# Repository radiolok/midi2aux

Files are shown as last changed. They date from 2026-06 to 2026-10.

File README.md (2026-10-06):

# АВК-6 «Музыкальная пауза»: FPGA-синтезатор и процессор эффектов

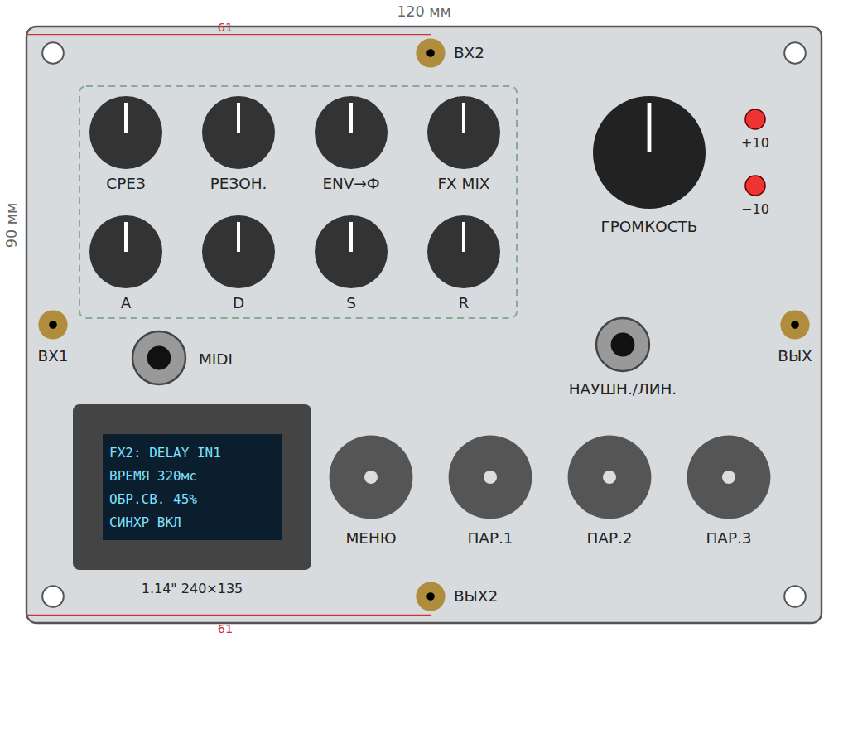
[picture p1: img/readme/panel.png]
Панель модуля (эскиз 120×90 мм)


Сменный модуль для аналогового компьютера **АВК-6**: полифонический MIDI-синтезатор и процессор
эффектов на ПЛИС **Tang Nano 20K** (макет — Tang Nano 9K). Модуль стыкуется с АВК в обе стороны:
входы ВХ1/ВХ2 и СИНХР принимают напряжения АВК и управляют синтезатором и эффектами, а выходы
ВЫХ/ВЫХ2 отдают в АВК звук, огибающие, LFO, GATE или напряжение высоты ноты. Готовый звук
доступен и без АВК — на гнезде наушников / линейного выхода.

Весь звуковой тракт (голоса, фильтры, огибающие, модуляция, эффекты) — в RTL на ПЛИС; распределение
голосов, меню, пресеты — прошивка софт-процессора PicoRV32 внутри той же ПЛИС.

> **Состояние.** Этапы 0–9 плана реализованы и проверены в симуляции (Verilator, бит-в-бит против
> Python-моделей, CI на каждый коммит). Плата, распиновка и проверка на железе — впереди
> (см. [«Что ещё нужно проверить на железе»](#что-ещё-нужно-проверить-на-железе)).
> Предыдущий модуль серии — одноголосный конвертер **MIDI2AUX** на Arduino Nano: [docs/midi2aux.md](docs/midi2aux.md).

Все графики ниже построены по тем же моделям, с которыми бит-в-бит сверяется RTL
(`fpga/model/synthmodel`), а снимки экрана — по коду меню прошивки (`make readme-img`).
Машинная единица АВК (МЕ) = 10 В; входы и выходы — ±12.5 В по постоянному току.

## Содержание

- [Возможности](#возможности)
- [Как устроен](#как-устроен)
- [Аппаратная часть](#аппаратная-часть)
- [Панель](#панель)
- [Голос: генераторы](#голос-генераторы)
- [Фильтр](#фильтр)
- [Огибающие](#огибающие)
- [Модуляция: LFO, матрица, детектор](#модуляция-lfo-матрица-детектор)
- [Связь с АВК](#связь-с-авк)
- [Эффекты](#эффекты)
- [Меню: как пользоваться](#меню-как-пользоваться)
- [Пресеты, SD-карта, обновление прошивки](#пресеты-sd-карта-обновление-прошивки)
- [Консоль](#консоль)
- [Сборка и проверка](#сборка-и-проверка)
- [Что ещё нужно проверить на железе](#что-ещё-нужно-проверить-на-железе)

## Возможности

| | |
|---|---|
| Полифония | 32 голоса на 20K, 16 на 9K (параметр `NUM_VOICES`), MIDI omni, velocity, pitch bend, mod wheel, sustain |
| Голос | 2 генератора (пила, меандр/PWM, треугольник, синус) + шум, расстройка, PolyBLEP, жёсткая синхронизация от СИНХР |
| Фильтр | резонансный ФНЧ / полосовой / ФВЧ 12 дБ/окт на голос, срез от огибающей, velocity и модуляции |
| Огибающие | две ADSR на голос: громкость и срез фильтра |
| Модуляция | 2 LFO (6 форм, сброс фазы от СИНХР), матрица 8 маршрутов «источник × глубина × через» на высоту, срез, громкость, скважность; следящий детектор огибающей входа |
| Связь с АВК | ВХ1/ВХ2 — 12-битные АЦП на 4·fs с цифровым фильтром; СИНХР — период, запуск нот, такт LFO и задержки; ВЫХ2 — любой сигнал шины или напряжение высоты ноты 1 В/окт |
| Эффекты | слоты на общей шине сигналов: MATH (как математические блоки АВК), DELAY ×2, CHORUS/FLANGER, REVERB; мягкий ограничитель на выходах |
| Управление | 8 ручек, 4 энкодера с кнопками, дисплей 240×135, консоль по USB-UART |
| Выходы | ВЫХ, ВЫХ2 — ±12.5 В по постоянному току в АВК; НАУШН./ЛИН. — наушники 16–600 Ом или линейный вход |
| Хранение | пресеты на SD-карте (FAT16/FAT32), обновление прошивки с карты |

## Как устроен

```mermaid
flowchart LR
    MIDI[MIDI вход] --> PARSER[UART + парсер MIDI]
    PARSER --> CPU[PicoRV32: распределение голосов,<br/>меню, пресеты]
    PANEL[ручки, энкодеры,<br/>дисплей] <--> CPU
    CPU --> VOICES
    subgraph VOICES[Голоса ×32, по очереди на одном конвейере]
      OSC[2 генератора + шум] --> SVF[фильтр 12 дБ/окт] --> VCA[усилитель]
      ENV[ADSR1, ADSR2] --> SVF
      ENV --> VCA
    end
    IN[ВХ1, ВХ2<br/>АЦП + дециматор] --> BUS
    SYNC[СИНХР] --> MOD
    MOD[LFO ×2, матрица,<br/>детектор] --> VOICES
    IN --> MOD
    VOICES --> BUS[шина сигналов S0…S7:<br/>синт, ВХ1, ВХ2, LFO1, LFO2,<br/>СИНХР, ENV, GATE]
    MOD --> BUS
    BUS --> SLOTS[слоты: MATH, DELAY,<br/>CHORUS, REVERB]
    SLOTS --> BUS
    SLOTS <--> MEM[(SDRAM / BRAM)]
    BUS --> MIX[микшер ВЫХ + ограничитель] --> DAC[ЦАП PCM5102A:<br/>ВЫХ, НАУШН./ЛИН., ВЫХ2]
    BUS --> MIX2[ВЫХ2: выбранный сигнал] --> DAC
```

Частота отсчётов ≈ 48.34 кГц (PLL 99 МГц из кварца 27 МГц); внутри — 18 бит, 1.0 = 1 МЕ.
Подробности архитектуры и карта регистров — [`fpga/README.md`](fpga/README.md) и ТЗ
[`.plans/fpga-synth/trs.md`](.plans/fpga-synth/trs.md).

## Аппаратная часть

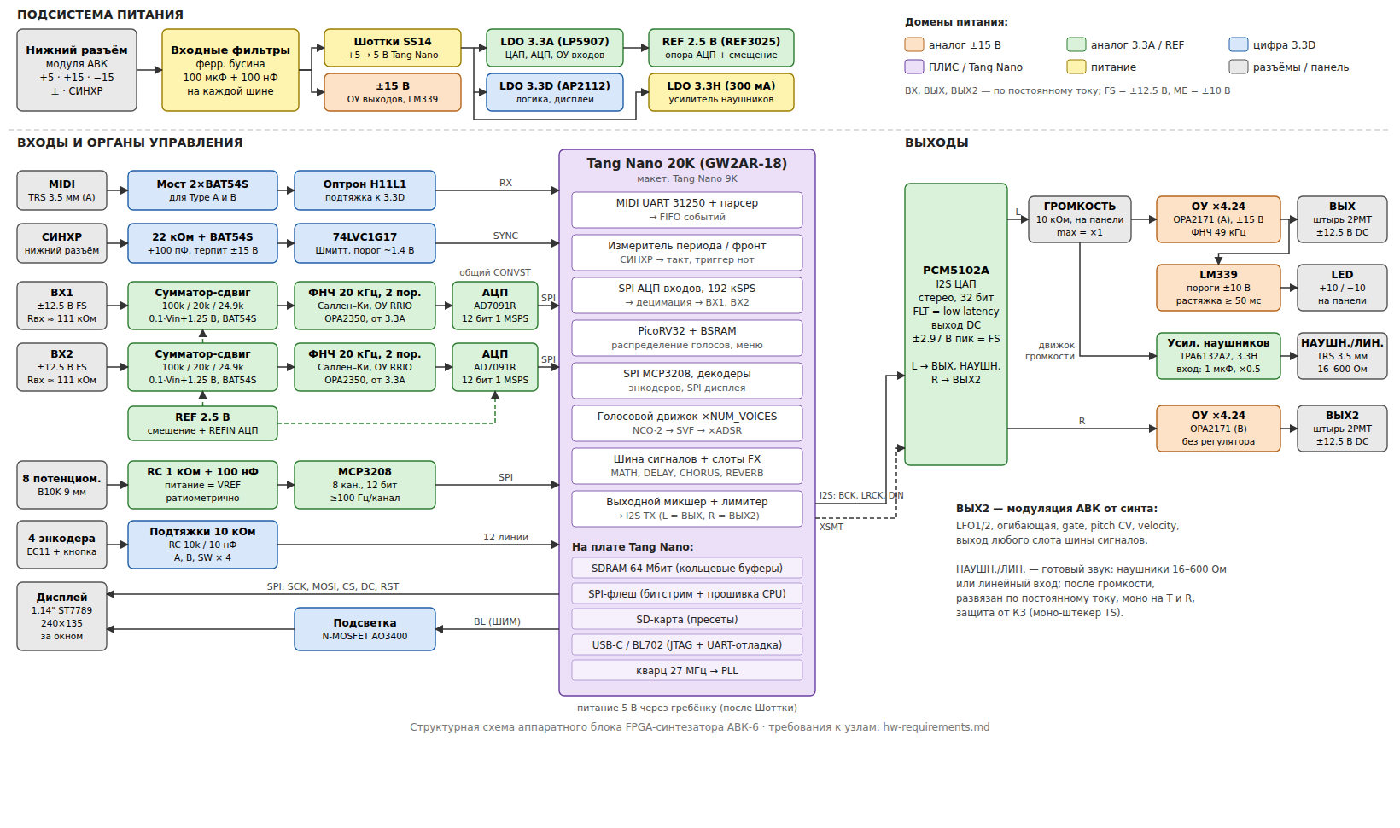
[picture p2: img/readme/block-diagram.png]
Структурная схема аппаратного блока


Цвет блока — домен питания. Всё питание приходит с нижнего разъёма модуля (+5, ±15 В):
Tang Nano питается через диод Шоттки (чтобы USB при прошивке не питал АВК), аналоговая часть —
от отдельного малошумящего LDO 3.3A и опоры 2.5 В, цифра — от LDO 3.3D, усилитель наушников —
от своего LDO 3.3H.

- **Входы ВХ1/ВХ2:** резисторный сумматор-сдвиг (0.1·Vin + 1.25 В, Rвх ≈ 111 кОм, выдерживает ±15 В) →
  ФНЧ 20 кГц 2-го порядка → 12-битный АЦП AD7091R. Оба АЦП запускаются одновременно, опора общая со
  смещением — поэтому A·B и A/B в слоте MATH не страдают от сдвига фаз и дрейфа.
- **MIDI** — через диодный мост (работает с кабелями TRS тип A и B) и оптрон; **СИНХР** с нижнего
  разъёма — через ограничитель и триггер Шмитта (ТТЛ и ±10 В).
- **Ручки** — через 8-канальный MCP3208, энкодеры и дисплей — прямо на ПЛИС.
- **ЦАП PCM5102A:** левый канал → ГРОМКОСТЬ → ОУ ×4.24 → ВЫХ (±12.5 В, индикаторы ±10 на LM339)
  и усилитель наушников TPA6132A2 → НАУШН./ЛИН.; правый канал → ОУ ×4.24 → ВЫХ2.

Требования к каждому узлу — [`hw-requirements.md`](.plans/fpga-synth/hw-requirements.md); принципиальная схема по узлам
(листы, номиналы, подключение по выводам) — [`hw/schematic.md`](hw/schematic.md);
плата и чертёж панели — [`hw/`](hw/README.md).

## Панель

| Элемент | Назначение |
|---|---|
| СРЕЗ, РЕЗОН., ENV→Ф, FX MIX | срез фильтра, резонанс, глубина огибающей на срез, уровень эффектов |
| A, D, S, R | огибающая громкости ADSR1 |
| ГРОМКОСТЬ | аналоговый регулятор выхода; индикаторы +10 / −10 — выход у границы МЕ |
| Энкодер МЕНЮ | листает страницы меню, нажатие — на первую страницу |
| Энкодеры ПАР.1–3 | меняют три параметра текущей страницы; кнопки ПАР.1/ПАР.2 на странице «ПРЕСЕТЫ» — загрузить / записать |
| ВХ1, ВХ2 | входы от АВК, ±12.5 В по постоянному току; штыри 2РМТ: ВХ1 — левый край по центру, ВХ2 — верхний край, 61 мм от левого угла |
| ВЫХ, ВЫХ2 | выходы в АВК: звук и второй канал (см. [ВЫХ2](#выход-2)); ВЫХ — правый край по центру, ВЫХ2 — нижний край, 61 мм от левого угла |
| MIDI | TRS 3.5 мм тип A (тип B тоже работает), слева — со стороны входов |
| НАУШН./ЛИН. | TRS 3.5 мм, справа — со стороны выходов: готовый звук после ГРОМКОСТИ, наушники 16–600 Ом или линейный вход; моно на оба канала, без постоянной составляющей |
| Дисплей | 1.14″ 240×135, меню и строка состояния |

Штыри ВХ/ВЫХ стоят на сетке перемычек АВК-6 (4 мм от края), чтобы соединять модуль с соседними
короткими скобами. Земли на панели нет — она есть на других модулях; СИНХР приходит через нижний
разъём. Эскиз в масштабе — [`panel-sketch.svg`](.plans/fpga-synth/panel-sketch.svg).

## Голос: генераторы

Два генератора на голос, их смесь и шум. Форма у каждого своя (`wave1`, `wave2`), второй генератор
можно сдвинуть на полутоны (`osc2semi`) и расстроить в центах (`detune`) — отсюда «толстый» звук.
Скважность `pw` задаёт ширину импульса меандра, её можно модулировать LFO (ШИМ).

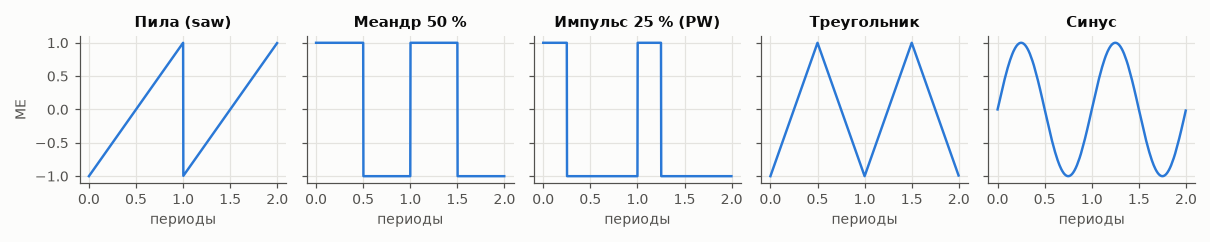
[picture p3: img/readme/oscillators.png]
Формы генераторов


**PolyBLEP** (`blep on`). У пилы и меандра бесконечно крутые скачки; на цифровой частоте отсчётов их
гармоники выше половины fs «заворачиваются» вниз и слышны как негармонический призвук на высоких
нотах. PolyBLEP сглаживает два отсчёта у каждого скачка по-полиномиальному — форма почти не
меняется, а завёрнутые частоты падают примерно на 15 дБ:

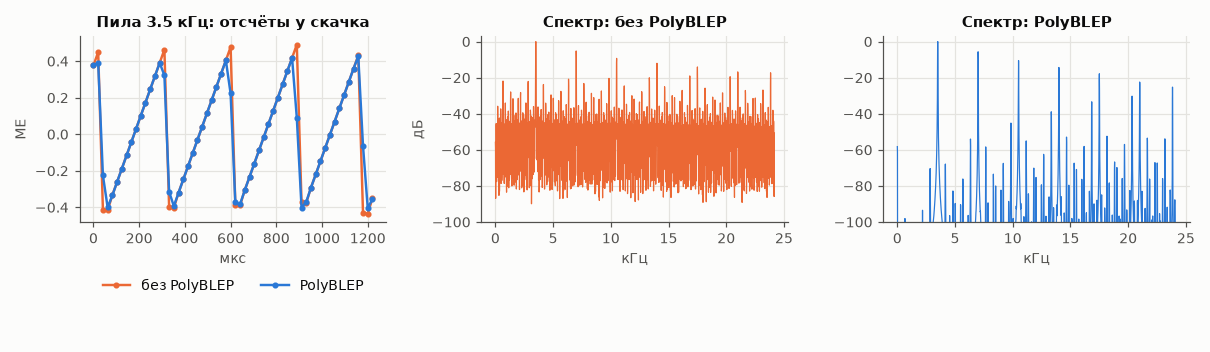
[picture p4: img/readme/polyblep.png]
PolyBLEP


**Жёсткая синхронизация** (`hsync osc1|osc2|both`). Каждый фронт на входе СИНХР перезапускает фазу
выбранных генераторов. Высота звука привязывается к частоте СИНХР, а собственная частота генератора
меняет тембр — классический «sync-звук», управляемый генератором АВК:

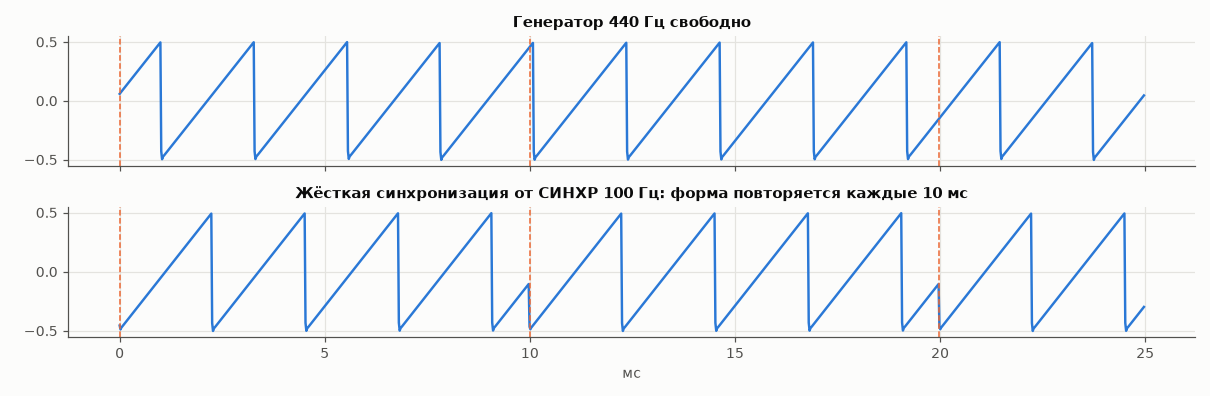
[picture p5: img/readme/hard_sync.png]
Жёсткая синхронизация


## Фильтр

Резонансный фильтр переменных состояний (Chamberlin, 12 дБ/окт, с двукратной передискретизацией) на
каждый голос. Режим `fmode`: **ФНЧ** (lp) — убирает верх, **полосовой** (bp) — оставляет полосу у среза,
**ФВЧ** (hp) — убирает низ. Резонанс (ручка РЕЗОН., добротность Q 0.5…20) поднимает частоты у среза;
при большом Q фильтр «звенит».

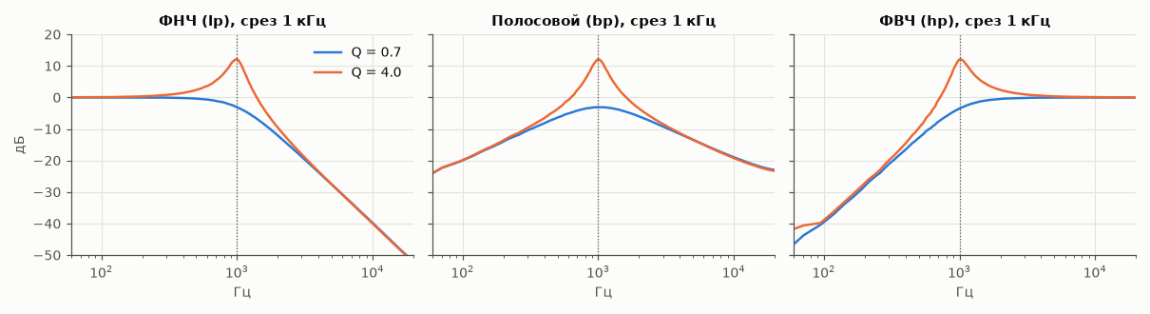
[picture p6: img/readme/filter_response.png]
АЧХ фильтра


Во времени: ФНЧ скругляет скачки пилы, с высоким резонансом на каждом скачке появляется затухающий
звон на частоте среза:

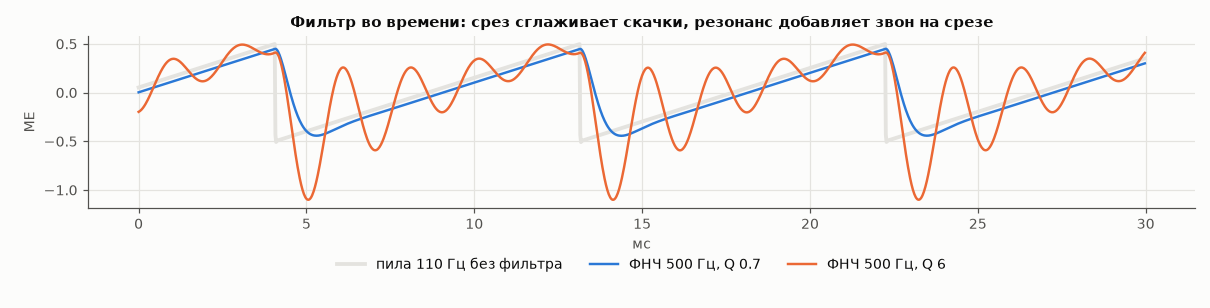
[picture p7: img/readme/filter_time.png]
Фильтр во времени


Срез складывается из: ручки СРЕЗ, огибающей ADSR2 × `env2amt` (± 4 октавы), силы нажатия × `velcut`
и маршрутов матрицы модуляции (например, ВХ1 → срез: генератор АВК «открывает» фильтр).

## Огибающие

**ADSR1** — громкость голоса (ручки A, D, S, R), **ADSR2** — срез фильтра (страницы «ADSR2»). Атака идёт
к 1.0 по экспоненте с «запасом» (как у аналоговых огибающих), спад и затухание — экспоненциальные;
время — до уровня −60 дБ. Повторное нажатие той же ноты перезапускает огибающие.

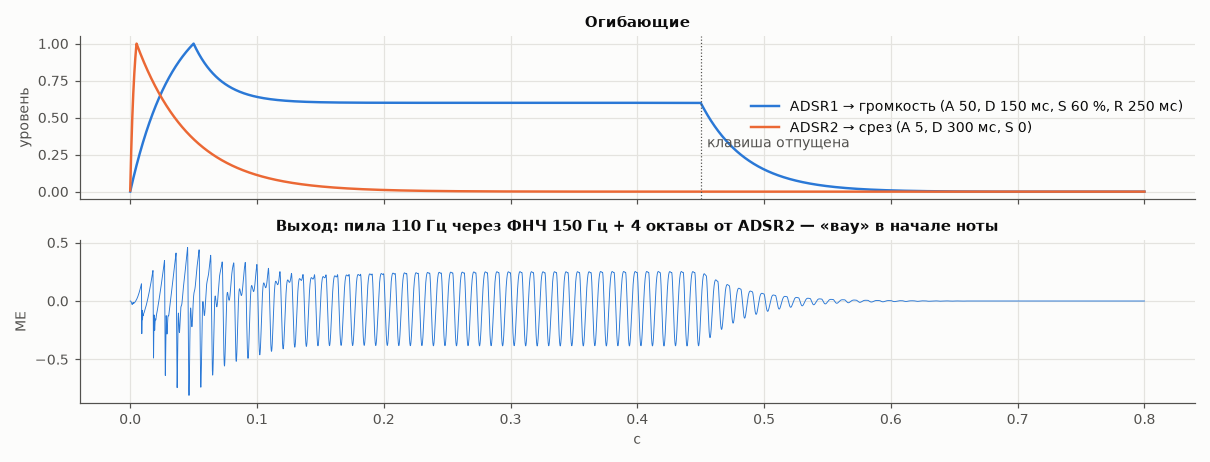
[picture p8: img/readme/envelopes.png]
Огибающие


## Модуляция: LFO, матрица, детектор

**Два LFO** (0.01…50 Гц): синус, треугольник, пила вверх и вниз, меандр, случайный (выборка-хранение).
В режиме `syncmode lfo` фронт СИНХР сбрасывает их фазу — LFO идут в такт с АВК.

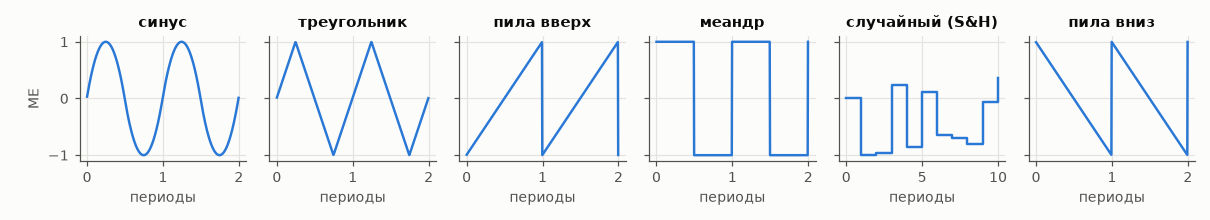
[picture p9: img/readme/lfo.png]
Формы LFO


**Матрица модуляции** — 8 маршрутов «источник × глубина × через»: значение источника умножается на
глубину и, если задан, на третий сигнал «через» (например, LFO1 × колесо модуляции = вибрато, маршрут 0).

| Источники | Назначения |
|---|---|
| 1 LFO1, 2 LFO2, 3 колесо модуляции, 4 ВХ1, 5 ВХ2, 6 СИНХР (±1), 7 ENV (ADSR1 последней ноты), 8 GATE, 9 AUX (из прошивки), 10 детектор огибающей | 1 высота (1 МЕ = октава при глубине 65536), 2 срез, 3 громкость (AM), 4 скважность (ШИМ) |

Маршруты 1…7 задаются из консоли: `route <k> <источник> <через> <назначение> <глубина>`,
например `route 1 4 0 1 65536` — ВХ1 управляет высотой, 1 МЕ (10 В) = октава.

**Следящий детектор огибающей** (источник 10) выделяет громкость сигнала ВХ1 или ВХ2 (`follsrc`), с
отдельными временами атаки и спада (`follatk`, `follrel`). Им удобно, например, открывать фильтр
громкостью сигнала из АВК:

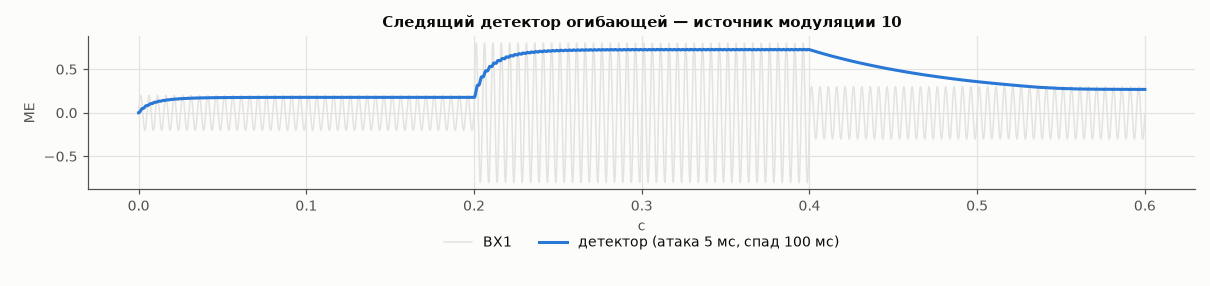
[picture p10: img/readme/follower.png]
Детектор огибающей


## Связь с АВК

**Входы ВХ1, ВХ2.** Два 12-битных АЦП опрашиваются с учетверённой частотой и проходят через
64-отводный цифровой ФНЧ (полоса 21.5 кГц). Нуль и масштаб калибруются командой `cal`.
Входы можно подмешать прямо в выход (`in1mix`, `in2mix`), направить в матрицу модуляции или на
вход любого эффекта.

**Вход СИНХР** (после компаратора) — `syncmode`:
- `off` — только измерение частоты (команда `avk`);
- `lfo` — фронт сбрасывает фазу LFO;
- `note` — каждый фронт перезапускает ноту `syncnote`: АВК «играет» синтезатором.

Также СИНХР задаёт время задержек (`dlysync on`) и жёстко синхронизирует генераторы (`hsync`).

**Шина сигналов.** Всё, что можно смешивать и обрабатывать, лежит на общей шине: S0 синтезатор,
S1 ВХ1, S2 ВХ2, S3 LFO1, S4 LFO2, S5 СИНХР (±1), S6 ENV, S7 GATE, дальше — выходы слотов эффектов.
Вход каждого эффекта — любой сигнал шины, в том числе выход другого эффекта.

**Выход 2** (`out2src`, `out2gain`): любой сигнал шины (по умолчанию LFO1) — так синтезатор
модулирует блоки АВК своими LFO, огибающей или GATE; либо `pitch` — напряжение высоты последней
ноты, 1 В/окт (0 В = нота 60, до первой октавы).

**Выходной микшер.** ВЫХ = синтезатор + подмешанные входы + эффекты (каждый со своим уровнем),
через мягкий ограничитель: до 1 МЕ (10 В) сигнал проходит без искажений, выше плавно упирается
в 1.25 МЕ — перегрузка микшера не даёт жёсткой отсечки:

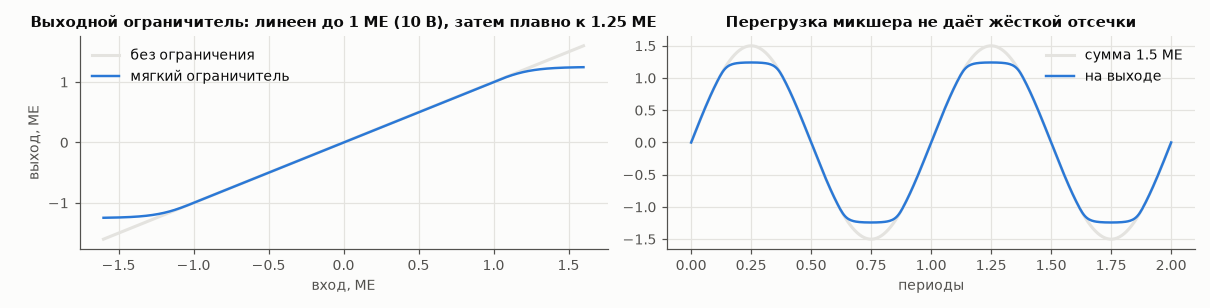
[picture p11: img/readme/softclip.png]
Мягкий ограничитель


## Эффекты

Эффекты — это **слоты** на шине сигналов. У каждого слота вход A (и B) — любой сигнал шины, выход
слота снова попадает на шину и в микшер с уровнем «уровень × FX MIX» (ручка FX MIX масштабирует все
эффекты сразу). На 20K шесть слотов: MATH, MATH, DELAY, DELAY, CHORUS, REVERB; на 9K — MATH, MATH,
DELAY (у 9K мало памяти). Эффекты с памятью работают и в обходе — линия задержки остаётся
заполненной, эффект включается без провала.

### MATH — математика над сигналами

Два слота повторяют математические блоки АВК над любыми двумя сигналами шины (`slot1a`, `slot1b`):

| `slot1op` | Операция | Для чего |
|---|---|---|
| `mul` | A·B | кольцевой модулятор, VCA под управлением АВК |
| `div` | A/B | деление напряжений (с насыщением) |
| `abs` | \|A\| | выпрямитель, удвоение частоты |
| `add`, `sub` | A+B, A−B | сумматор |
| `min`, `max` | min(A, B), max(A, B) | ограничители, логика |
| `mod` | A mod B | остаток — «пилообразное» свёртывание |
| `axpb` | A·k+B | масштаб и смещение (`slot1k`, −2…+2) |

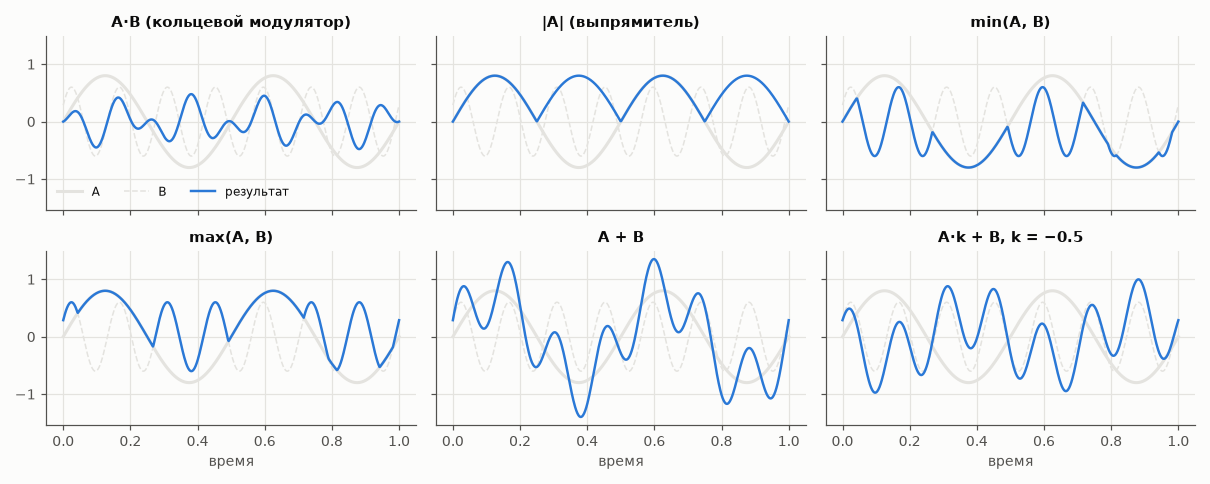
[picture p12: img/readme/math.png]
Операции MATH


Например: `set slot1op 1` (mul), `slot1a in1`, `slot1b in2`, `fxmix 100` — на выходе произведение двух
сигналов АВК; синус 300 Гц × синус 1 кГц даёт 700 и 1300 Гц (проверено в системном тесте).

### DELAY — задержка

Две независимых линии задержки (на 9K — одна): вход (`dly1src`, `dly2src`, по умолчанию ВХ1 и ВХ2),
время (`dly1time`, до 20 с; памяти хватает на ~21 с на линию на 20K и на 85 мс на 9K), повтор —
обратная связь (`dly1fb`, −99…99 %), уровень в выход (`dly1lvl`). `dlysync on` — время задержки равно периоду СИНХР: эхо в такт с АВК.

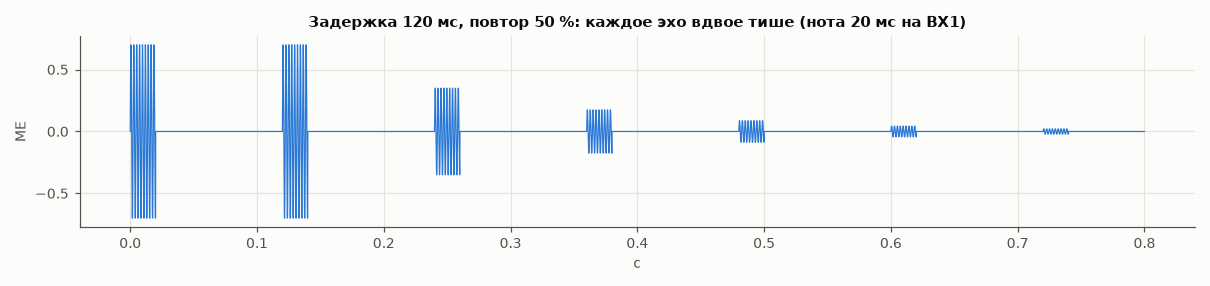
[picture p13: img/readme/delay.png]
Задержка


### CHORUS / FLANGER — хорус и флэнжер

Копия сигнала с задержкой, которая медленно «плавает» (треугольный LFO внутри слота), смешивается
с оригиналом. Параметры: базовая задержка `chobase` (0.1…20 мс), глубина качания `chodepth`,
частота `chorate`, повтор `chofb`, уровень `cholvl`.

- **Хорус** — задержка 5…20 мс, без повтора: звук «размножается», уровень и фаза дышат.

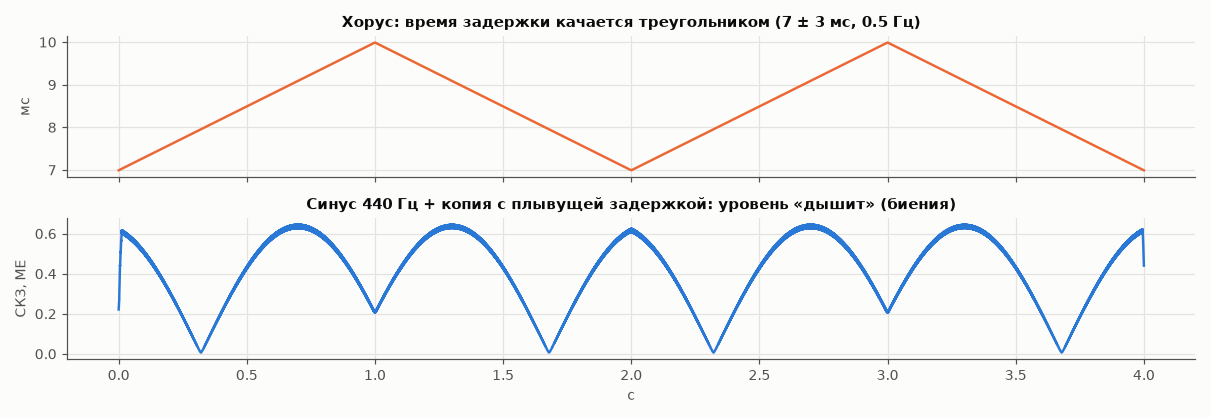
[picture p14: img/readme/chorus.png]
Хорус


- **Флэнжер** — задержка 0.5…5 мс с сильным повтором: получается гребёнка провалов по спектру,
  которая ездит вверх-вниз («реактивный» звук). На шуме это видно на спектрограмме:

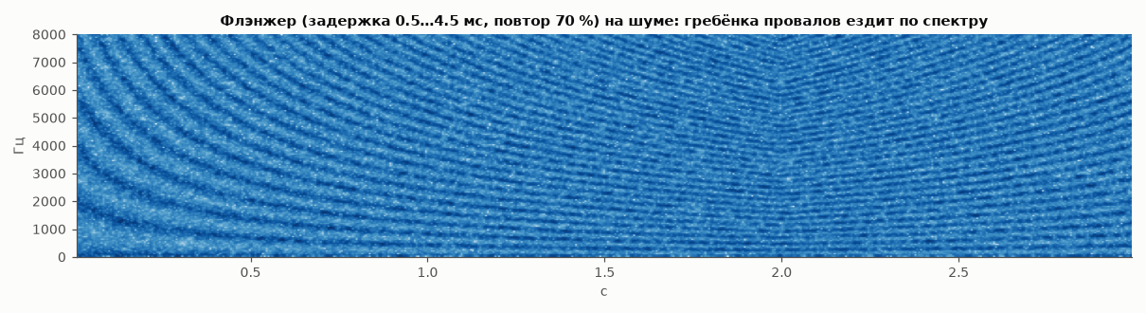
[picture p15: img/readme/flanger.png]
Флэнжер


### REVERB — реверберация

Классическая схема Шрёдера/Freeverb: 4 параллельных гребенчатых фильтра с глушением в обратной
связи и 2 последовательных всепропускающих. `revroom` — размер помещения (длительность хвоста),
`revdamp` — глушение (чем больше, тем быстрее гаснут высокие), `revlvl` — уровень, `revsrc` — вход
(по умолчанию синтезатор; можно реверберировать и сигнал АВК).

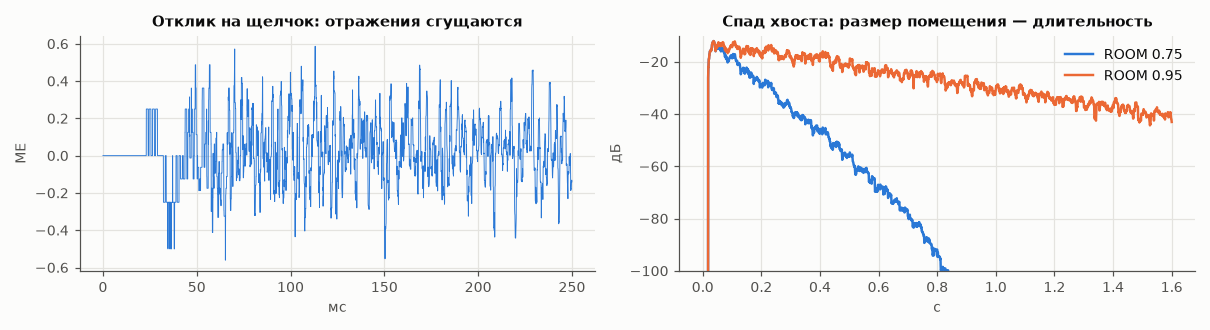
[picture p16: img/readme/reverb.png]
Реверберация


### Как добавить эффект

Эффект = RTL-модуль со стандартным интерфейсом слота (`fpga/rtl/avk/slot_*.sv`: `start`, A, B →
`y`, `done`; параметры; порт памяти) + строка в списке слотов (`SLOT_TYPES`) + описание в прошивке
(`sw/fw/avk.c`). Для каждого слота есть Python-модель, с которой RTL сверяется бит-в-бит.

## Меню: как пользоваться

Меню — это 22 страницы по три параметра. Верхняя строка — название и номер страницы, ниже три
параметра с текущими значениями, внизу строка состояния.

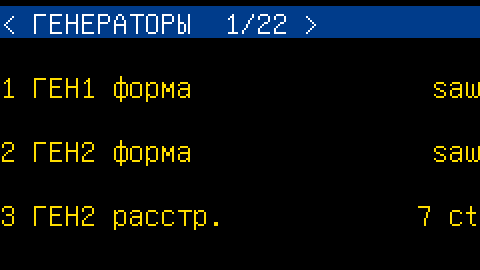
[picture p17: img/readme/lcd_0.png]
Страница меню


- **Энкодер МЕНЮ** листает страницы по кругу (назад с первой — на последнюю). **Нажатие МЕНЮ** —
  сразу на первую страницу.
- **Энкодеры ПАР.1, ПАР.2, ПАР.3** меняют первый, второй и третий параметр страницы. Шаг зависит от
  единиц: частоты, времена и добротность меняются примерно на 6 % за щелчок (быстро проходят весь
  диапазон), остальные — на 1/200 диапазона, перечисления — на один вариант.
- **Восемь ручек** закреплены за своими параметрами (СРЕЗ, РЕЗОН., ENV→Ф, FX MIX, A, D, S, R). Ручка
  не перехватывает параметр, пока её не повернули: после загрузки пресета значения не прыгают, а при
  первом повороте параметр переходит к положению ручки. По краям хода — «мёртвые зоны», чтобы
  уверенно доставать минимум и максимум. Срез, резонанс и времена — по экспоненте, остальное — линейно.
  При повороте ручки строка состояния на 1.5 с показывает новое значение:

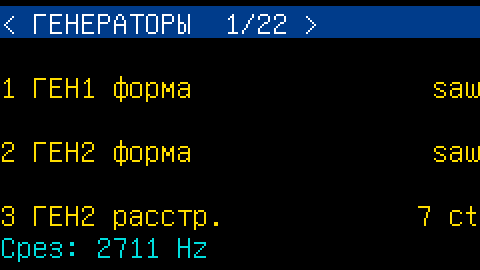
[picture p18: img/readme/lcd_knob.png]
Строка состояния при повороте ручки


- Строка состояния также показывает последнее MIDI-событие и результат записи/загрузки пресета.
- Все параметры меню доступны и из консоли (`set <имя> <значение>`, имена — в таблице).

Все страницы:

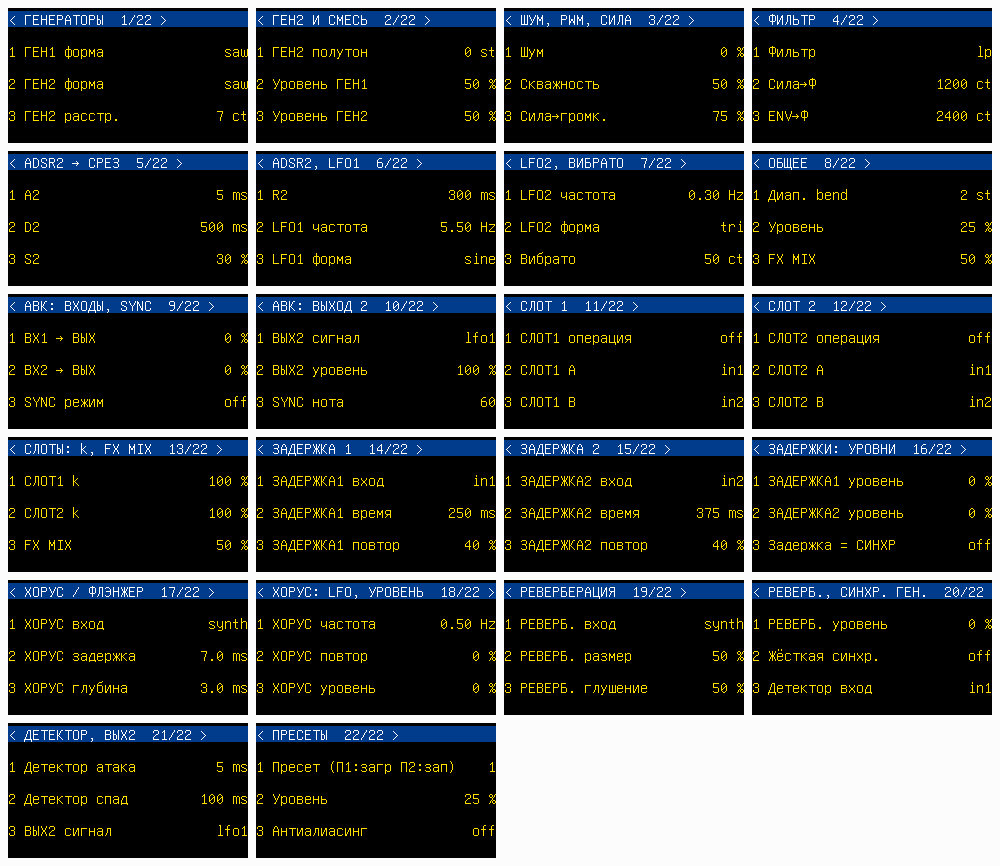
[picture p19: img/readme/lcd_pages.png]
Все страницы меню


| № | Страница | ПАР.1 | ПАР.2 | ПАР.3 |
|---|---|---|---|---|
| 1 | ГЕНЕРАТОРЫ | ГЕН1 форма (`wave1`) | ГЕН2 форма (`wave2`) | ГЕН2 расстр. (`detune`) |
| 2 | ГЕН2 И СМЕСЬ | ГЕН2 полутон (`osc2semi`) | Уровень ГЕН1 (`mix1`) | Уровень ГЕН2 (`mix2`) |
| 3 | ШУМ, PWM, СИЛА | Шум (`noise`) | Скважность (`pw`) | Сила→громк. (`velamp`) |
| 4 | ФИЛЬТР | Фильтр (`fmode`) | Сила→Ф (`velcut`) | ENV→Ф (`env2amt`) |
| 5 | ADSR2 → СРЕЗ | A2 (`a2`) | D2 (`d2`) | S2 (`s2`) |
| 6 | ADSR2, LFO1 | R2 (`r2`) | LFO1 частота (`lfo1rate`) | LFO1 форма (`lfo1wave`) |
| 7 | LFO2, ВИБРАТО | LFO2 частота (`lfo2rate`) | LFO2 форма (`lfo2wave`) | Вибрато (`vibrato`) |
| 8 | ОБЩЕЕ | Диап. bend (`bend`) | Уровень (`master`) | FX MIX (`fxmix`) |
| 9 | АВК: ВХОДЫ, SYNC | ВХ1 → ВЫХ (`in1mix`) | ВХ2 → ВЫХ (`in2mix`) | SYNC режим (`syncmode`) |
| 10 | АВК: ВЫХОД 2 | ВЫХ2 сигнал (`out2src`) | ВЫХ2 уровень (`out2gain`) | SYNC нота (`syncnote`) |
| 11 | СЛОТ 1 | СЛОТ1 операция (`slot1op`) | СЛОТ1 A (`slot1a`) | СЛОТ1 B (`slot1b`) |
| 12 | СЛОТ 2 | СЛОТ2 операция (`slot2op`) | СЛОТ2 A (`slot2a`) | СЛОТ2 B (`slot2b`) |
| 13 | СЛОТЫ: k, FX MIX | СЛОТ1 k (`slot1k`) | СЛОТ2 k (`slot2k`) | FX MIX (`fxmix`) |
| 14 | ЗАДЕРЖКА 1 | ЗАДЕРЖКА1 вход (`dly1src`) | ЗАДЕРЖКА1 время (`dly1time`) | ЗАДЕРЖКА1 повтор (`dly1fb`) |
| 15 | ЗАДЕРЖКА 2 | ЗАДЕРЖКА2 вход (`dly2src`) | ЗАДЕРЖКА2 время (`dly2time`) | ЗАДЕРЖКА2 повтор (`dly2fb`) |
| 16 | ЗАДЕРЖКИ: УРОВНИ | ЗАДЕРЖКА1 уровень (`dly1lvl`) | ЗАДЕРЖКА2 уровень (`dly2lvl`) | Задержка = СИНХР (`dlysync`) |
| 17 | ХОРУС / ФЛЭНЖЕР | ХОРУС вход (`chosrc`) | ХОРУС задержка (`chobase`) | ХОРУС глубина (`chodepth`) |
| 18 | ХОРУС: LFO, УРОВЕНЬ | ХОРУС частота (`chorate`) | ХОРУС повтор (`chofb`) | ХОРУС уровень (`cholvl`) |
| 19 | РЕВЕРБЕРАЦИЯ | РЕВЕРБ. вход (`revsrc`) | РЕВЕРБ. размер (`revroom`) | РЕВЕРБ. глушение (`revdamp`) |
| 20 | РЕВЕРБ., СИНХР. ГЕН. | РЕВЕРБ. уровень (`revlvl`) | Жёсткая синхр. (`hsync`) | Детектор вход (`follsrc`) |
| 21 | ДЕТЕКТОР, ВЫХ2 | Детектор атака (`follatk`) | Детектор спад (`follrel`) | ВЫХ2 сигнал (`out2src`) |
| 22 | ПРЕСЕТЫ | Пресет (`preset`) | Уровень (`master`) | Антиалиасинг (`blep`) |

Параметры ручек — `cutoff`, `res`, `env2amt`, `fxmix`, `a1`, `d1`, `s1`, `r1` — доступны и из консоли.

## Пресеты, SD-карта, обновление прошивки

На карте (FAT16 или FAT32, файлы в корне) пресеты лежат как `PRESET00.BIN` … `PRESET99.BIN`: все
параметры и маршруты матрицы 1…7. Пресет хранит значения по именам параметров, поэтому старые
пресеты загружаются и после обновления прошивки с новыми параметрами.

- **С панели:** последняя страница «ПРЕСЕТЫ», ПАР.1 — номер; **нажатие ПАР.1 — загрузить,
  нажатие ПАР.2 — записать**. Результат — в строке состояния.
- **Из консоли:** `save 5`, `load 5`, `ls` — список файлов, `sd` — переподключить карту.
- **Обновление прошивки:** положить `FIRMWARE.BIN` в корень карты и дать команду `fwupdate` —
  образ копируется во флеш (с проверкой CRC перед записью заголовка) и загружается при следующем
  включении. Без карты прошивку можно залить по USB-UART: `sw/tools/load.py`.

## Консоль

USB-UART Tang Nano (115200 бод): `help`, `list`, `get`/`set <параметр> <значение>`,
`route …`, `note <n> [vel]` / `off <n>`, `screen`, `panel`, `avk`, `cal <1|2> zero|<мВ>`,
`mem`, `sd`, `ls`, `save`, `load`, `fwupdate`. Подробно — [`sw/README.md`](sw/README.md).

## Сборка и проверка

Из корня репозитория (Ubuntu 24.04: Verilator, gcc-riscv64-unknown-elf, Python 3 с numpy/scipy/matplotlib/cocotb):

| Команда | Что делает |
|---|---|
| `make test` | линт RTL, тесты моделей, хост-тесты прошивки, юнит-тесты RTL (cocotb), системные тесты ядра — то же, что CI |
| `make fw` | прошивка RISC-V → `build/sw/fw.bin` |
| `make bitstream-20k`, `make bitstream-9k` | битстрим в Gowin EDA (локально) |
| `make readme-img` | картинки этого README |
| `make plots` | графики симуляции в `fpga/sim/img` |

Дальше: [`fpga/README.md`](fpga/README.md) — RTL, платы, тестбенч; [`fpga/sim/README.md`](fpga/sim/README.md)
— что и как проверяется, с графиками по этапам; [`sw/README.md`](sw/README.md) — прошивка;
[`.plans/fpga-synth/plan.md`](.plans/fpga-synth/plan.md) — план работ на железе (стенд на отладочных платах,
готовый блок), журнал сделанного в симуляции — [`done-sim.md`](.plans/fpga-synth/done-sim.md).

## Что ещё нужно проверить на железе

- распиновка: ручки, энкодеры, дисплей, АЦП, СИНХР, SD-карта пока не назначены (вопрос HO-01);
- фаза тактового сигнала встроенной SDRAM 20K (HO-07; команда `mem` для проверки);
- ресурсы и тайминг 32 голосов и 6 слотов в Gowin EDA;
- калибровка входов по реальному входному каскаду (`cal`);
- инициализация конкретного модуля ST7789, направление энкодеров, совместимость SD-карт;
- порядок и критерии всех проверок — части А (стенд) и Б (блок) [плана](.plans/fpga-synth/plan.md);
- PSRAM на 9K не используется (нужен IP Gowin) — на 9K одна задержка до 85 мс, без хоруса и реверберации.

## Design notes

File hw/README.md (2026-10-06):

# Железо: несущая плата и панель

Проект KiCad схемы — [`kicad/`](kicad/README.md) (сгенерирован по `schematic.md`, цепи сверены скриптом; PDF —
[`kicad/avk_synth.pdf`](kicad/avk_synth.pdf)). Дальше здесь будут плата (Tang Nano 20K, ЦАП, АЦП входов, ОУ, MIDI, СИНХР, органы
управления) и чертёж панели 120×90 мм. Схему и разводку рисует автор проекта.

Структурная схема

Исходные данные:
- **принципиальная схема по узлам** (листы KiCad, позиционные обозначения, номиналы, подключение по выводам, расчёты) —
  [`schematic.md`](schematic.md);
- требования к узлам, номиналы, открытые вопросы `HO-xx` — [`.plans/fpga-synth/hw-requirements.md`](../.plans/fpga-synth/hw-requirements.md);
- структурная схема — [`.plans/fpga-synth/block-diagram.svg`](../.plans/fpga-synth/block-diagram.svg)
  (генерируется `.plans/fpga-synth/tools-gen-block-diagram.py`);
- эскиз панели — [`.plans/fpga-synth/panel-sketch.svg`](../.plans/fpga-synth/panel-sketch.svg);
- трек «железо» H1–H4 — [`.plans/fpga-synth/plan.md`](../.plans/fpga-synth/plan.md).

Предварительная распиновка макета (этап 0) — в `fpga/boards/*/*.cst`, окончательная — после этапа 6 (HO-01).

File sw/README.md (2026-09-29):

# Прошивка софт-процессора (PicoRV32, RV32IMC)

```
include/hw.h       карта памяти и регистры периферии (fpga/rtl/synth_core.sv)
include/lib.h      общий рантайм: UART, printf-подмножество, CRC-32, SPI-флеш, string.h
lib/               его реализация (без libc, -nostdlib; libgcc — для 64-битной арифметики)
boot/              загрузчик в ROM (0x0010_0000, ≤ 4 КБ, без .data/.bss)
fw/                прошивка в RAM с адреса 0: start.S, link.ld, main.c
test/              хост-тесты на обычном gcc (+ ASan/UBSan): unity_lite.h, test_*.c
tools/bin2hex.py   BIN → HEX 32-битных слов (инициализация RAM в симуляции)
tools/bin2rom.py   BIN → SV case-ROM (fpga/rtl/soc/boot_rom.sv)
tools/load.py      загрузка прошивки по UART с компьютера (pyserial)
```

Сборка из корня репозитория:

| Команда | Результат |
|---|---|
| `make fw` | `build/sw/fw.{elf,bin,hex,map}`, `build/sw/boot.{elf,bin}` |
| `make swtest` | хост-тесты `sw/test` |
| `make bootrom` | пересобрать загрузчик и `fpga/rtl/soc/boot_rom.sv` (CI проверяет, что файл актуален) |

Тулчейн: `riscv-none-elf-` (xPack) или `riscv64-unknown-elf-` (Ubuntu: `apt install gcc-riscv64-unknown-elf`),
выбирается автоматически; явно — `make fw CROSS=riscv-none-elf-`.

## Загрузка прошивки

Загрузчик (`boot/boot.c`) после сброса печатает `AVK6 boot`, ждёт образ по UART `SYSINFO_BOOT_WAIT` мс
(500 по умолчанию), затем грузит образ из SPI-флеша, а если его нет — ждёт образ по UART бесконечно.
Работающая прошивка тоже реагирует на магическое слово `AVKB` и передаёт управление загрузчику,
поэтому новая прошивка заливается без нажатия сброса и без пересборки битстрима:

```bash
make fw
python3 sw/tools/load.py /dev/ttyUSB1 build/sw/fw.bin           # в RAM, запуск
python3 sw/tools/load.py /dev/ttyUSB1 build/sw/fw.bin --flash   # и сохранить во флеш
```

Протокол: `AVKB` → устройство отвечает `LOAD` → `len:u32le flags:u32le образ crc32:u32le`
(`flags` бит 0 — записать во флеш) → `OK` и запуск, либо `E1` (длина), `E2` (CRC), `E3` (проверка флеша).
Во флеше по адресу `SYSINFO_FW_FLASH`: заголовок `{"AVKF", len, crc}`, образ — со смещения +256.
Смещение — параметр `FW_FLASH_OFFSET` ядра (9K: 1 МБ, 20K: 5 МБ — за битстримом; уточнить на железе).

Системные тесты `fpga/sim/system/test_synth_core_soc.py` прогоняют всё это в Verilator: загрузку по UART,
отказ по CRC и повтор, запись во флеш (модель SPI NOR) и загрузку из него, повторный вход из прошивки,
печать MIDI-событий прошивкой.

## Консоль (UART, 115200 или `UART_BAUD` ядра)

| Команда | Что делает |
|---|---|
| `list`, `get <p>`, `set <p> <v>` | параметры из таблицы `fw/patch.c` (те же, что в меню) |
| `route <k> <src> <via> <dst> <depth>` | маршрут матрицы модуляции 1…7 (0 — вибрато); номера — `SRC_*`, `DST_*` в `hw.h` |
| `note <n> [vel]`, `off <n>` | нажать / отпустить ноту |
| `screen`, `panel` | текст экрана; энкодеры, кнопки, ручки |
| `avk` | коды и значения ВХ1/ВХ2, частота и счётчик фронтов СИНХР, текущие значения шины сигналов |
| `cal <1\|2> zero` | калибровка нуля входа: на вход подан 0 В |
| `cal <1\|2> <мВ>` | калибровка масштаба (после `zero`): на вход подано известное напряжение |

Параметры связи с АВК: `in1mix`, `in2mix` (входы в ВЫХ), `out2src`, `out2gain` (источник и уровень ВЫХ2),
`syncmode` (`off` / `lfo` — фронт СИНХР сбрасывает фазу LFO / `note` — фронт перезапускает ноту `syncnote`),
`slot1op`…`slot2k` (операция слота MATH, источники A и B, коэффициент k), `fxmix` (уровень слотов в ВЫХ).

Задержки (слоты DELAY): `dly1src`, `dly1time` (мс), `dly1fb` (повтор, %), `dly1lvl` (уровень в ВЫХ), то же `dly2*`;
`dlysync on` — время задержки равно периоду СИНХР. `mem <слово> [значение]` — чтение/запись внешней памяти
(проверка SDRAM на плате).

Хорус/флэнжер: `chosrc`, `chobase`, `chodepth` (0.1 мс), `chorate`, `chofb`, `cholvl`. Реверберация: `revsrc`,
`revroom`, `revdamp`, `revlvl`. `hsync` — жёсткая синхронизация генераторов от СИНХР (`osc1`/`osc2`/`both`);
детектор огибающей: `follsrc`, `follatk`, `follrel`, источник 10 в `route`; `out2src pitch` — на ВЫХ2
напряжение высоты последней ноты (1 В/окт, 0 В = нота 60).

SD-карта (FAT16/FAT32, корневой каталог): `sd` — подключить (делается и при старте), `ls`, `save <n>` / `load <n>` —
пресет `PRESETnn.BIN` (все параметры и маршруты 1…7), `fwupdate` — записать `FIRMWARE.BIN` во флеш (загрузится
при следующем старте). С панели: последняя страница «ПРЕСЕТЫ», номер — энкодер ПАР.1, нажатие ПАР.1 —
загрузить, ПАР.2 — записать. `tools/fatimg.py` — образы FAT для тестов.

`blep on` — PolyBLEP (подавление наложения спектра) для пилы и меандра.

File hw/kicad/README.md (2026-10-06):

# Проект KiCad: несущая плата FPGA-синтезатора АВК-6

Схема по описанию [`../schematic.md`](../schematic.md) и требованиям
[`hw-requirements.md`](../../.plans/fpga-synth/hw-requirements.md). Формат — **KiCad 7** (открывается и в 8/9,
при сохранении KiCad обновит формат). PDF всех листов — [`avk_synth.pdf`](avk_synth.pdf).

| Файл | Что |
|---|---|
| `avk_synth.kicad_pro`, `avk_synth.kicad_sch` | проект и корневой лист |
| `power`, `fpga`, `midi_sync`, `analog_in`, `audio_out`, `phones`, `panel` `.kicad_sch` | 7 листов по функциональным блокам (`schematic.md`, раздел 0) |
| `avk_synth.kicad_sym`, `sym-lib-table` | свои символы: **AD7091R**, **Tang_Nano_20K** (в стандартных библиотеках KiCad 7 их нет) |
| `tools/gen_kicad.py` | генератор: все детали, номиналы, посадочные места и цепи — в нём |
| `tools/check.py` | проверка: KiCad экспортирует netlist, он сравнивается с задуманными цепями |
| `tools/render.sh` | экспорт листов в SVG/PNG для просмотра |

## Как устроена схема

- Символы и посадочные места — **из стандартных библиотек KiCad** (Device, Diode, Audio, Amplifier_Audio, Comparator,
  Analog_ADC, Isolator, Regulator_Linear, Reference_Voltage, Memory_Flash …). Где точного символа нет, взят
  совместимый по выводам: OPA2350 — символ TLV9062, OPA2171 — символ OPA2277, W25Q64JV — символ W25Q32JVSS.
- На листе каждый узел — **блок в пунктирной рамке с заголовком**; блоки уложены по листу плитками, детали внутри — рядами.
  Выводы соединены **метками цепей**: локальные —
  внутри листа, глобальные — между листами, земля — символом GND. Проводов между деталями нет: это схема
  «на метках», её удобно читать по цепям и сверять с `schematic.md`; при желании перерисовать проводами в KiCad.
- Имена цепей к ПЛИС совпадают с портами `fpga/boards/tang_nano_20k/top_synth.sv`.
- Обозначения — как в `schematic.md` (R101…, U401…), аннотация не нужна.

## Проверено

- `python3 tools/check.py`: все **153 цепи** netlist KiCad совпадают с задуманными, нет повторов обозначений
  и цепей из одного вывода.
- Цоколёвки PCM5102A, LM339, MCP3208, H11L1, BAT54S, 74LVC1G17, W25Q, TPA6132A2 взяты из символов KiCad
  и сверены с `schematic.md`.
- ERC в KiCad 7 из командной строки недоступен — **запусти ERC в редакторе** при первом открытии.

## Не проверено — сверить до разводки

| Что | Где |
|---|---|
| Номера выводов **AD7091R** (свой символ, по памяти) и режим внешней опоры | `adc`, HO-09 |
| Выводы **Tang Nano 20K**: имена с `[IOnn]` — из `.cst` (предварительно), остальные не назначены; посадочного места нет | `fpga`, HO-01 |
| Распиновка **нижнего разъёма** J101 (сейчас Conn_01x05) и его посадочное место | `power`, HO-06 |
| TPA6132A2: HPVDD (конденсатор или к VDD), G0/G1 для 0 дБ, EN | `hp` |
| Порядок выводов модуля дисплея J901 и тип входа BLK | `panel` |
| Посадочные места панельных деталей (гнёзда TRS, потенциометры, энкодеры) — по купленным деталям | все |

## Перегенерация

```bash
python3 hw/kicad/tools/gen_kicad.py     # перезаписывает *.kicad_sch и avk_synth.kicad_sym
python3 hw/kicad/tools/check.py         # нужен kicad-cli (sudo apt install kicad)
```

**Генератор перезаписывает листы.** Пока схема правится через `gen_kicad.py` — правь его и `schematic.md` вместе.
Как только начнёшь править схему руками в KiCad (перерисовка проводами, разводка), генератор больше не запускай:
источником правды становятся файлы KiCad, а `check.py` можно оставить для сверки цепей с `schematic.md`.

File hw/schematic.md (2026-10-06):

# Принципиальная схема несущей платы: описание по узлам

Статус: **черновик v0.1** — исходные данные для рисования схемы в KiCad.
Требования (`Т-xx`) и обоснования — [`hw-requirements.md`](../.plans/fpga-synth/hw-requirements.md);
структурная схема — [`block-diagram.svg`](../.plans/fpga-synth/block-diagram.svg); панель — [`panel-sketch.svg`](../.plans/fpga-synth/panel-sketch.svg).

Как читать:
- **Проект KiCad** по этому описанию — [`kicad/`](kicad/README.md) (все листы, цепи сверены с этим документом скриптом).
- Картинки узлов — `hw/img/sch_*.png` (рядом SVG), генерируются `python3 hw/img/gen_schematics.py`
  (schemdraw + matplotlib); при изменении номиналов правится скрипт, а не картинка.
- Схема разбита на **7 листов KiCad** по функциональным блокам (раздел 0); разделы ниже идут по узлам (ain, adc, dac, aout, hp — части листов `analog_in`, `audio_out`, `phones`). У каждого листа — назначение, таблица элементов
  (позиционное обозначение, номинал, корпус, куда подключён), расчёт номиналов и замечания по разводке.
- **Имена цепей ПЛИС совпадают с портами** `fpga/boards/tang_nano_20k/top_synth.sv` (`i2s_bck`, `pot_cs_n`, …) —
  так проще сверять схему с `.cst`.
- **Номера выводов** указаны там, где цоколёвка стандартная (сдвоенный ОУ SOIC-8, LM339, MCP3208, SOT-23 и т. п.).
  Где написано «по даташиту» — цоколёвку брать из символа KiCad/даташита конкретной микросхемы и **обязательно сверить**.
- Резисторы 0603 1 %, если не сказано иное; «0.1 %» — прецизионные (тонкоплёночные, 25 ppm/°C). Конденсаторы до 1 нФ
  — C0G/NP0; 100 нФ…10 мкФ — X7R; электролиты — с запасом по напряжению ×1.5.

---

## 0. Листы и шины

| Лист | Поз. | Содержание | Шины питания |
|---|---|---|---|
| `power` | 1xx | нижний разъём, фильтры, Шоттки 5 В, LDO 3V3A / 3V3D / 3V3H, опора 2.5 В | вход: +5, +15, −15 |
| `fpga` | 2xx | гребёнки Tang Nano 20K, SPI-флеш прошивки, контрольные точки цифры | 5V_TN, 3V3D |
| `midi_sync` | 3xx | MIDI TRS → мост → оптрон; СИНХР → ограничитель → триггер Шмитта | 3V3D |
| `analog_in` | 4xx, 45x, 5xx | входные каскады ВХ1 / ВХ2 (сумматор-сдвиг, ограничитель, ФНЧ Саллена–Ки) и 2× AD7091R | 3V3A, 3V3D, REF2V5 |
| `audio_out` | 6xx, 7xx | PCM5102A; ГРОМКОСТЬ, выходные ОУ ВЫХ/ВЫХ2, индикаторы перегрузки | 3V3A, 3V3D, ±15, REF2V5 |
| `phones` | 8xx | усилитель наушников, гнездо НАУШН./ЛИН. | 3V3H |
| `panel` | 9xx | 8 потенциометров + MCP3208, 4 энкодера, дисплей, панельные штыри | 3V3A, 3V3D |

**Шины (глобальные метки):**

| Цепь | Источник | Потребители |
|---|---|---|
| `+5V_IN` | нижний разъём, после фильтра | Шоттки → `5V_TN`, LDO 3V3A / 3V3D / 3V3H |
| `5V_TN` | D102 (Шоттки) | вывод 5 V Tang Nano |
| `+15V`, `−15V` | нижний разъём, после фильтров | OPA2171, LM339 |
| `3V3A` | U101 LP5907 | ОУ входов, АЦП (VDD), ЦАП (AVDD, CPVDD), MCP3208, потенциометры, REF |
| `3V3D` | U102 AP2112K | ЦАП (DVDD), АЦП (VDRIVE), флеш, оптрон, 74LVC1G17, энкодеры, дисплей |
| `3V3H` | U103 AP2112K | усилитель наушников |
| `REF2V5` | U104 REF3025 | REFIN обоих АЦП, смещение входов, пороги индикаторов |
| `GND` | нижний разъём | единая земля (Т-2.1) |

---

## 1. Лист `power`

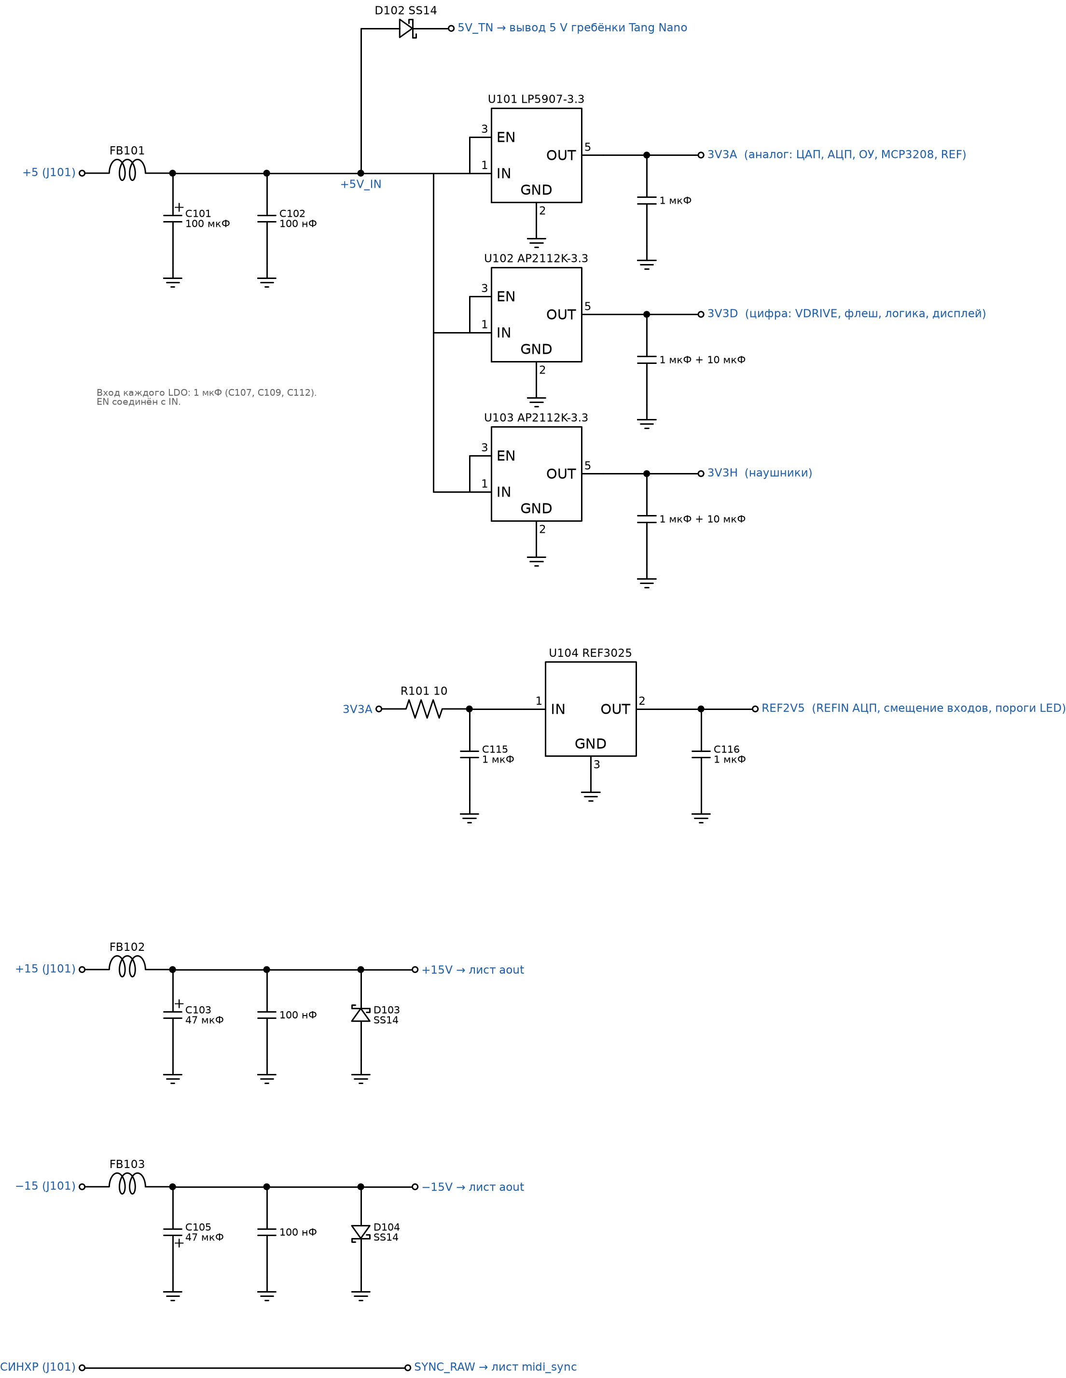
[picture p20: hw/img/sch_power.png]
Лист power: фильтры питания, LDO, опора 2.5 В


| Поз. | Номинал / тип | Корпус | Подключение / примечание |
|---|---|---|---|
| J101 | разъём штатного модуля АВК-6 | по образцу | +5, +15, −15, GND, СИНХР; распиновка — HO-06 |
| FB101 | ферритовая бусина 600 Ом @100 МГц, ≥ 2 А | 0805 | +5 → `+5V_IN` |
| FB102, FB103 | ферритовая бусина 600 Ом @100 МГц, ≥ 0.5 А | 0603 | +15 → `+15V`, −15 → `−15V` |
| C101 | 100 мкФ / 10 В, электролит или полимер | SMD 6.3×5.4 | `+5V_IN` – GND |
| C103, C105 | 47 мкФ / 25 В, электролит | SMD 6.3×5.4 | `+15V` – GND, `−15V` – GND (минус к −15!) |
| C102, C104, C106 | 100 нФ | 0603 | рядом с электролитами |
| D102 | SS14 (1 А, 40 В) | SMA | анод `+5V_IN`, катод `5V_TN` (Т-2.2) |
| D103 | SS14 | SMA | катод `+15V`, анод GND (защита ОУ, Т-2.9) |
| D104 | SS14 | SMA | анод `−15V`, катод GND |
| U101 | LP5907MFX-3.3 (250 мА, 6.5 мкВ rms) | SOT-23-5 | 1 IN = `+5V_IN`, 2 GND, 3 EN = IN, 4 NC, 5 OUT = `3V3A` |
| C107, C108 | 1 мкФ X7R | 0603 | вход и выход U101 (керамика обязательна) |
| U102 | AP2112K-3.3 (600 мА) | SOT-23-5 | 1 VIN = `+5V_IN`, 2 GND, 3 EN = VIN, 4 NC, 5 VOUT = `3V3D` |
| C109, C110 | 1 мкФ + C111 10 мкФ | 0603 / 0805 | вход, выход U102; 10 мкФ — на выходе (дисплей, флеш) |
| U103 | AP2112K-3.3 | SOT-23-5 | как U102, VOUT = `3V3H` |
| C112, C113 | 1 мкФ + C114 10 мкФ | 0603 / 0805 | вход, выход U103 |
| R101 | 10 Ом | 0603 | `3V3A` → вход REF (RC-фильтр с C115) |
| C115 | 1 мкФ | 0603 | вход U104 – GND |
| U104 | REF3025 (2.5 В, 0.2 %, 50 ppm/°C) или REF3325 / ADR361 (лучше по дрейфу) | SOT-23-3 | REF3025: 1 IN, 2 OUT = `REF2V5`, 3 GND (сверить по даташиту выбранной опоры) |
| C116 | 1 мкФ X7R | 0603 | `REF2V5` – GND, у вывода OUT (проверить допустимую ёмкость нагрузки опоры) |
| TP101…TP107 | контрольные точки | — | `+5V_IN`, `+15V`, `−15V`, `3V3A`, `3V3D`, `3V3H`, `REF2V5`; TP108, TP109 — GND |

**Расчёт и замечания:**
- Потери на LDO: (5 − 3.3) В × ток. U102 (3V3D: дисплей ~30 мА, флеш, логика) — до 0.1 Вт; U103 (наушники) — до 0.15 Вт
  в пиках. SOT-23-5 справляется, но под выводом GND — полигон.
- REF2V5 нагружен: 2 × REFIN АЦП (единицы мкА), 2 × Rb 20 кОм (до ±0.1 мА в зависимости от входа), ветка индикаторов
  (≤ 0.1 мА) — итого < 0.5 мА, REF3025 отдаёт до 25 мА.
- Шины ±15 в схеме используются только в листе `aout`; −15 не заводить на другие листы.

## 2. Лист `fpga`

| Поз. | Номинал / тип | Корпус | Подключение / примечание |
|---|---|---|---|
| J201, J202 | гнёзда 1×20, шаг 2.54 (ответные к гребёнкам Tang Nano 20K) | THT | цоколёвка — по схеме Sipeed Tang Nano 20K (HO-01) |
| U201 | W25Q64JVSSIQ (64 Мбит SPI NOR) — прошивка CPU и калибровки | SOIC-8 | 1 /CS = `flash_cs_n`, 2 DO = `flash_miso`, 3 /WP = 3V3D, 4 GND, 5 DI = `flash_mosi`, 6 CLK = `flash_sck`, 7 /HOLD = 3V3D, 8 VCC = 3V3D |
| R201 | 10 кОм | 0603 | `flash_cs_n` → 3V3D (флеш не выбрана, пока ПЛИС не сконфигурирована) |
| C201 | 100 нФ | 0603 | VCC U201 |
| R202…R2xx | 33 Ом | 0603 | последовательно в **выходах ПЛИС с быстрыми фронтами**, у вывода ПЛИС: `i2s_bck`, `i2s_lrck`, `i2s_din`, `adc_sclk`, `pot_sck`, `lcd_sck`, `flash_sck` (гасят звон на линиях длиннее ~5 см) |
| TP2xx | контрольные точки | — | `i2s_bck`, `i2s_lrck`, `i2s_din`, `adc_sclk`, `adc_sdo1`, `midi_rx`, `sync_in` (Т-15.5) |

**Внешний флеш нужен**: на Tang Nano 20K встроенная SPI-флеш занята битстримом и недоступна пользовательской логике,
поэтому прошивка CPU (`FW_FLASH_OFFSET`) и калибровки (план, Ж0.3) лежат во внешней микросхеме на гребёнке
(`fpga/README.md`). На 9K используется встроенная флеш — U201 на макете не нужна.

**Назначение выводов ПЛИС** (номера — из текущего `tang_nano_20k_synth.cst`, предварительно; остальные — назначить при HO-01
и внести в единую таблицу пинов, план Ж0.1):

| Цепь | Направление | Вывод ПЛИС | Лист |
|---|---|---|---|
| `i2s_bck`, `i2s_lrck`, `i2s_din` | выход | 25, 26, 27 | dac |
| `dac_xsmt` | выход | 28 | dac, hp |
| `midi_rx` | вход | 29 | midi_sync |
| `uart_tx`, `uart_rx` | — | 69, 70 (BL702 на плате Tang Nano — **на несущую не выводить**) | — |
| `flash_sck`, `flash_mosi`, `flash_miso`, `flash_cs_n` | вых/вых/вх/вых | 73, 74, 75, 85 | fpga |
| `sync_in` | вход | HO-01 | midi_sync |
| `adc_convst_n`, `adc_cs_n`, `adc_sclk` | выход | HO-01 | adc |
| `adc_sdo1`, `adc_sdo2` | вход | HO-01 | adc |
| `pot_sck`, `pot_mosi`, `pot_cs_n` / `pot_miso` | выход / вход | HO-01 | panel |
| `enc_a[3:0]`, `enc_b[3:0]`, `enc_sw[3:0]` | вход | HO-01 | panel |
| `lcd_sck`, `lcd_mosi`, `lcd_cs_n`, `lcd_dc`, `lcd_rst_n`, `lcd_bl` | выход | HO-01 | panel |
| `sd_*` | — | слот TF на плате Tang Nano (на несущую не выводить) | — |

Итого на гребёнке: **37 GPIO** (33 по Т-3.4 + 4 на флеш). Если свободных меньше — объединить SCK/MOSI потенциометров,
дисплея и флеша в одну шину с раздельными CS (тогда RTL: общий SPI-мастер, план Ж0.1).

Питание Tang Nano: `5V_TN` → вывод 5 V гребёнки; GND — **все** выводы GND гребёнки на полигон. Вывод 3V3 Tang Nano
на несущей не использовать (у платы свой LDO, и 3V3D от него не зависит).

## 3. Лист `midi_sync`

### 3.1 MIDI (Т-4)

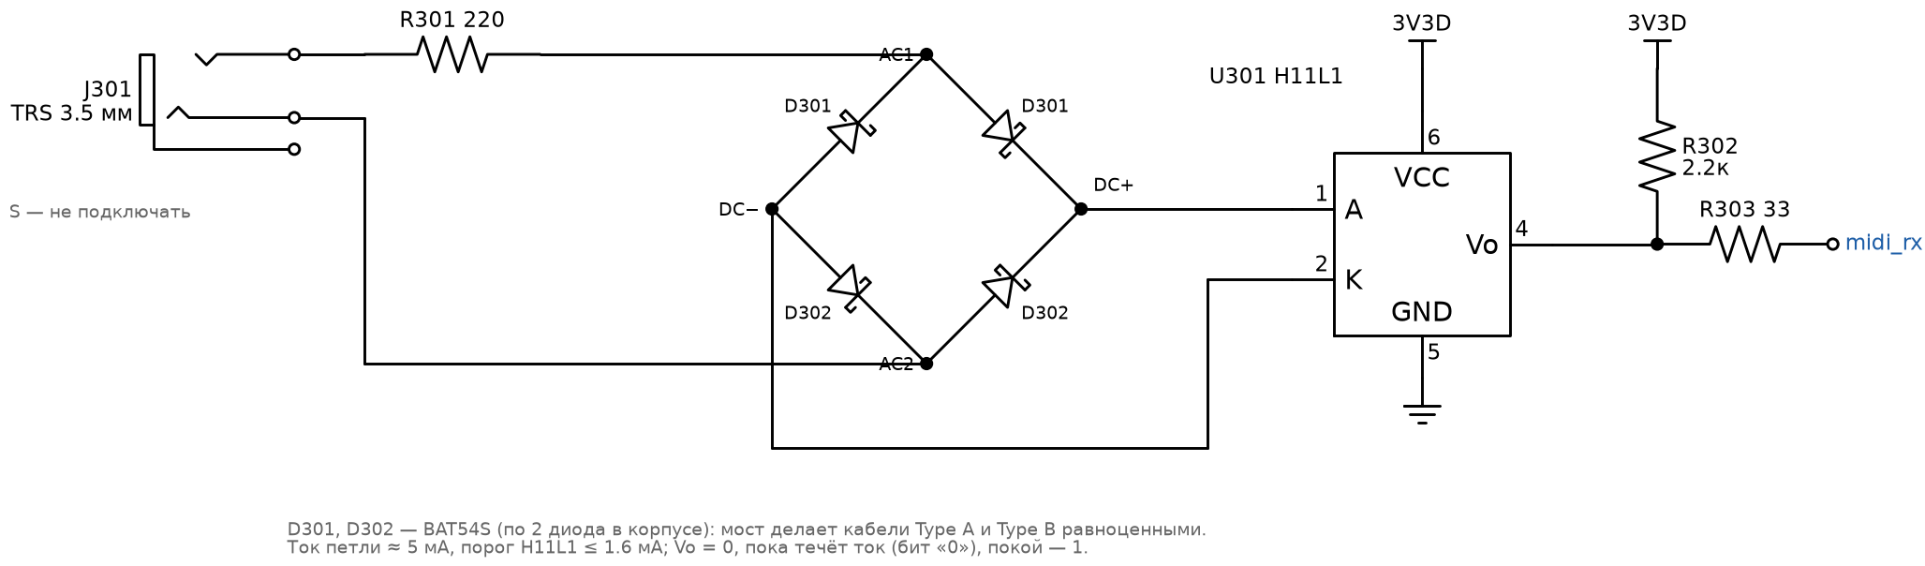
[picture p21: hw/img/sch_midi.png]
MIDI-вход: мост и оптрон


| Поз. | Номинал / тип | Корпус | Подключение / примечание |
|---|---|---|---|
| J301 | гнездо 3.5 мм стерео на панель (PJ-392 / Lumberg 1503 09) | THT | T, R, S; на панели слева (у входов) |
| R301 | 220 Ом | 0805 | T → AC1 моста |
| D301, D302 | BAT54S (два Шоттки последовательно; 1 — анод D1, 2 — катод D2, 3 — средняя точка) | SOT-23 | мост: вывод 3 D301 = AC1, вывод 3 D302 = AC2; выводы 2 обоих = DC+; выводы 1 обоих = DC− |
| U301 | H11L1 (оптрон с триггером Шмитта, VCC 3…15 В) | DIP-6 / SMD-6 | 1 анод = DC+, 2 катод = DC−, 4 Vo, 5 GND, 6 VCC = 3V3D (сверить цоколёвку по даташиту) |
| C302 | 100 нФ | 0603 | VCC U301 |
| R302 | 2.2 кОм | 0603 | Vo → 3V3D (выход — открытый коллектор) |
| R303 | 33 Ом | 0603 | Vo → `midi_rx` |
| C301 | 10 нФ / 100 В, **не устанавливать** | 0603 | S → GND, только если будут наводки; MIDI-приёмник по стандарту экран не заземляет |

**Расчёт:** ток петли от передатчика 5 В (220 + 220 Ом в передатчике + R301 220 Ом): (5 − 1.2 светодиод − 2·0.3 мост) / 660 ≈ 4.8 мА;
от передатчика 3.3 В (33 + 10 Ом): (3.3 − 1.8) / 263 ≈ 5.7 мА. Порог H11L1 ≤ 1.6 мА — запас ×3.
Полярность: ток течёт при «0» бита → Vo = 0; покой (нет тока) → Vo = 1 — это и ждёт `uart_rx` RTL (покой — высокий уровень).
Мост делает разницу между TRS Type A и Type B несущественной (Т-4.2).

### 3.2 СИНХР (Т-5)

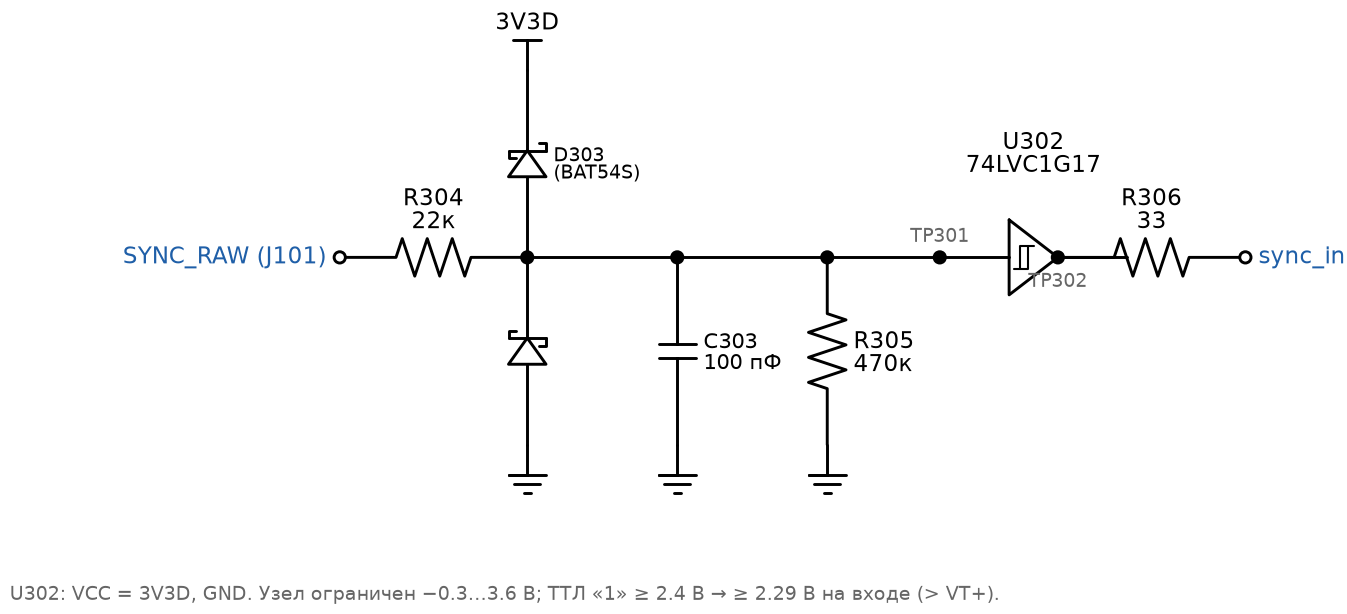
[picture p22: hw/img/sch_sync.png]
Вход СИНХР


| Поз. | Номинал / тип | Корпус | Подключение / примечание |
|---|---|---|---|
| R304 | 22 кОм | 0603 | `SYNC_RAW` → узел |
| D303 | BAT54S | SOT-23 | 1 = GND, 2 = 3V3D, 3 = узел (ограничение −0.3…+3.6 В) |
| C303 | 100 пФ | 0603 | узел → GND (τ = 2.2 мкс — фильтр иголок, на 1.1 кГц не влияет) |
| R305 | 470 кОм | 0603 | узел → GND: определённый «0», когда АВК выключен или СИНХР не подан |
| U302 | 74LVC1G17 (буфер с триггером Шмитта) | SOT-23-5 | 1 NC, 2 A = узел, 3 GND, 4 Y, 5 VCC = 3V3D |
| C304 | 100 нФ | 0603 | VCC U302 |
| R306 | 33 Ом | 0603 | Y → `sync_in` |

**Расчёт:** ТТЛ «1» ≥ 2.4 В → узел 2.4 · 470 / 492 = 2.29 В > порога VT+ 74LVC1G17 при 3.3 В (≤ 2.0 В) — уверенная «1».
При +15 В ток через ограничитель (15 − 3.6) / 22 к ≈ 0.52 мА — поглощает нагрузка 3V3D; при −15 В ≈ 0.67 мА в GND.
**Поправка к Т-5.3:** порог — порог 74LVC1G17 при 3.3 В (VT+ ≈ 1.5…2.0 В, VT− ≈ 0.9…1.4 В), а не «~1.4 В»; для ТТЛ и ±10 В годится.

## 4. Лист `ain` (повторяется для ВХ1 и ВХ2)

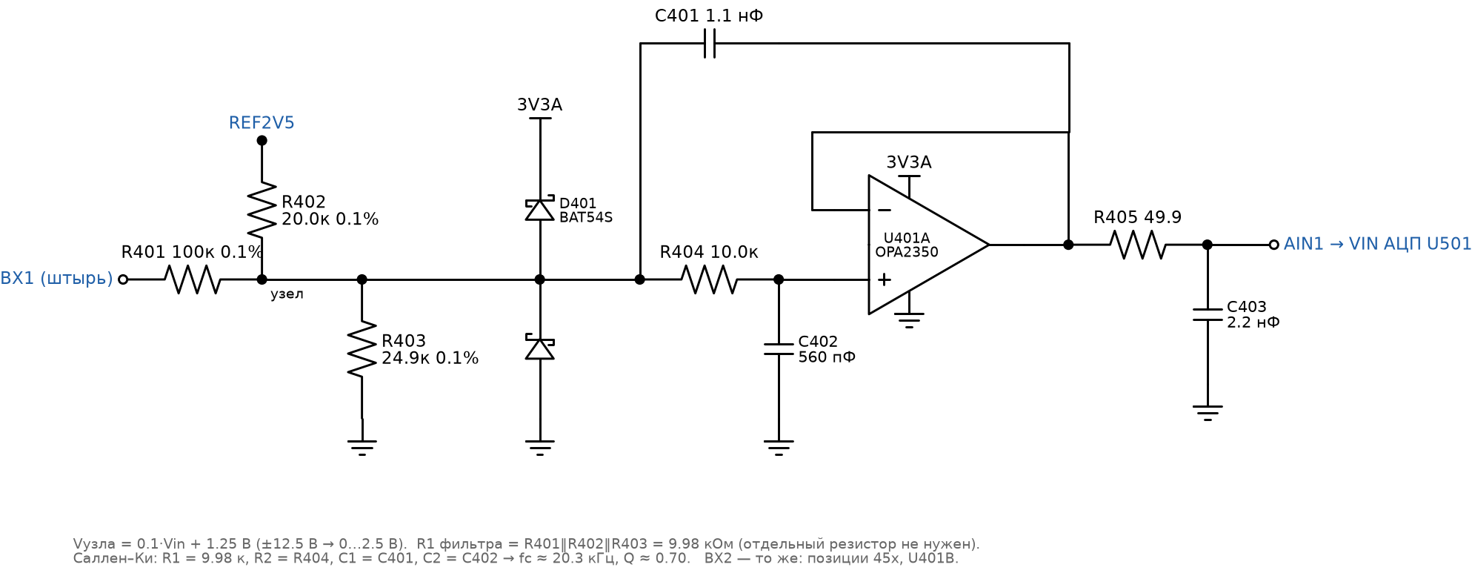
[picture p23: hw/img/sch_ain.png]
Входной каскад ВХ1 (ВХ2 — так же)


| Поз. (ВХ1 / ВХ2) | Номинал / тип | Корпус | Подключение / примечание |
|---|---|---|---|
| R401 / R451 | 100 кОм 0.1 % | 0805 | панельный штырь ВХ → узел сумматора (Ra) |
| R402 / R452 | 20.0 кОм 0.1 % | 0603 | `REF2V5` → узел (Rb) |
| R403 / R453 | 24.9 кОм 0.1 % | 0603 | узел → GND (Rc) |
| D401 / D451 | BAT54S | SOT-23 | 1 = GND, 2 = 3V3A, 3 = узел |
| C401 / C451 | 1.1 нФ C0G 1 % (или 1 нФ + 100 пФ) | 0603 | узел → выход ОУ (C1 фильтра Саллена–Ки) |
| R404 / R454 | 10.0 кОм 0.1 % | 0603 | узел → вход + ОУ (R2 фильтра) |
| C402 / C452 | 560 пФ C0G 1 % | 0603 | вход + ОУ → GND (C2 фильтра) |
| U401 | OPA2350 / TLV9062 / OPA2365 — **одна сдвоенная на оба канала**: A — ВХ1, B — ВХ2 | SOIC-8 | 1 OUTA, 2 IN−A = 1, 3 IN+A; 4 V− = GND; 5 IN+B, 6 IN−B = 7, 7 OUTB; 8 V+ = 3V3A |
| C404 | 100 нФ | 0603 | V+ U401 |
| R405 / R455 | 49.9 Ом | 0603 | выход ОУ → `AIN1` / `AIN2` |
| C403 / C453 | 2.2 нФ C0G | 0603 | `AIN1` / `AIN2` → GND, у вывода VIN АЦП |
| TP401 / TP451 | контрольная точка | — | `AIN1` / `AIN2` (Т-15.5) |

**Расчёт:**
- Сумматор: 1/Ra : 1/Rb : 1/Rc = 1 : 5 : 4.02 → Vузла = 0.1·Vin + 0.5·REF = 0.1·Vin + 1.25 В. ±12.5 В → 0…2.5 В.
  Выходное сопротивление узла (Тевенен) R1 = Ra‖Rb‖Rc = 9.98 кОм — это **первый резистор фильтра**, отдельный не нужен.
  Rвх по ВХ ≈ Ra + Rb‖Rc = 111 кОм (Т-6.2).
- Фильтр Саллена–Ки, единичное усиление, R1 = 9.98 к, R2 = 10.0 к, C1 = 1.1 нФ, C2 = 560 пФ:
  fc = 1 / (2π·√(R1·R2·C1·C2)) ≈ 20.3 кГц; Q = √(R1·R2·C1·C2) / (C2·(R1 + R2)) ≈ 0.70 (Баттерворт).
  На 172 кГц: −40·lg(172/20.3) ≈ −37 дБ (Т-6.3).
- Перегрузка: при +15 В узел = 2.75 В (< 3.3 В, ограничитель молчит), при −15 В узел = −0.25 В — открывается D401,
  ток ≤ 0.15 мА. ОУ с однополярным питанием 3V3A сам не выведет АЦП за 0…3.3 В.
- RC 49.9 Ом / 2.2 нФ (fc ≈ 1.45 МГц) — «резервуар» для заряда УВХ АЦП; ОУ видит его через 49.9 Ом и остаётся устойчивым.
- Погрешность: 0.1 % резисторов → ≤ 0.2 % усиления и ≤ 3 мВ смещения (приведено ко входу ≤ 30 мВ) до калибровки (Т-6.4).

**Разводка:** R401 у штыря, остальное — компактно у АЦП; узел сумматора (высокоомный) — короткий, окружить GND,
цифровые линии рядом не вести. Каналы ВХ1 и ВХ2 развести симметрично (Т-6.6).

## 5. Лист `adc`

| Поз. | Номинал / тип | Корпус | Подключение / примечание |
|---|---|---|---|
| U501, U502 | AD7091R (12 бит, 1 MSPS, SPI) — U501 для ВХ1, U502 для ВХ2 | MSOP-10 | выводы — **по даташиту**; цепи ниже |
| — VIN | | | U501: `AIN1`; U502: `AIN2` |
| — VDD | | | 3V3A, у каждой 100 нФ + 1 мкФ (C501…C504) |
| — VDRIVE | | | 3V3D, 100 нФ (C505, C506) — логика 3.3 В (Т-7.4) |
| — REFIN/REFOUT | | | `REFIN_ADC` (см. ниже), 1 мкФ X7R на GND у каждого (C507, C508; номинал — по даташиту) |
| — REGCAP (если есть) | | | конденсатор внутреннего регулятора — по даташиту |
| — GND | | | GND |
| — CONVST | | | `adc_convst_n` — **общий** для обоих (одновременная выборка, Т-7.1) |
| — CS | | | `adc_cs_n` — общий |
| — SCLK | | | `adc_sclk` — общий (через 33 Ом у ПЛИС, лист fpga); развести «звездой» от ПЛИС или цепочкой с минимальным отводом |
| — SDO | | | U501 → `adc_sdo1`, U502 → `adc_sdo2` (раздельные линии; общий CS не мешает) |
| R501 | 0 Ом (перемычка, выбор опоры) | 0603 | `REF2V5` → `REFIN_ADC` |

**Опора (HO-09).** По требованию Т-7.3 оба АЦП работают от общей внешней 2.5 В (`REF2V5`), той же, что даёт смещение
входов, — тогда смещение и шкала уходят вместе и сокращаются. **Нужно подтвердить по даташиту AD7091R**, как отключается
внутренняя опора при подаче внешней на REFIN/REFOUT (вывод, команда или режим питания). Запасной вариант без внешней опоры:
R501 не ставить, `REF2V5` брать с REFOUT U501 через повторитель на свободном ОУ (буфер обязателен — REFOUT высокоомный),
U104 не устанавливать.

**Разводка:** АЦП — между входными каскадами и ПЛИС; аналоговая и цифровая стороны микросхемы ориентированы к своим зонам;
полигон GND сплошной, без разреза.

## 6. Лист `dac`

| Поз. | Номинал / тип | Корпус | Подключение / примечание |
|---|---|---|---|
| U601 | PCM5102A | TSSOP-20 | цоколёвка ниже — **сверить с даташитом** |
| вывод 1 CPVDD | | | 3V3A; C601 100 нФ + C602 10 мкФ |
| 2 CAPP — 4 CAPM | | | C603 2.2 мкФ X7R между CAPP и CAPM (летающий конденсатор накачки) |
| 3 CPGND | | | GND |
| 5 VNEG | | | C604 2.2 мкФ X7R → GND |
| 6 OUTL | | | → R601 470 Ом → `DAC_L`; C605 2.2 нФ C0G `DAC_L` → GND |
| 7 OUTR | | | → R602 470 Ом → `DAC_R`; C606 2.2 нФ C0G `DAC_R` → GND |
| 8 AVDD | | | 3V3A; C607 100 нФ + C608 10 мкФ |
| 9 AGND | | | GND |
| 10 DEMP | | | GND (без де-эмфазиса) |
| 11 FLT | | | 3V3D (фильтр low latency, Т-8.2) |
| 12 SCK | | | GND (тактирование PLL от BCK, Т-8.1) |
| 13 BCK, 14 DIN, 15 LRCK | | | `i2s_bck`, `i2s_din`, `i2s_lrck` |
| 16 FMT | | | GND (I2S) |
| 17 XSMT | | | `dac_xsmt` через R603 1 кОм; R604 10 кОм → GND (молчит, пока ПЛИС не сконфигурирована, Т-8.3) |
| 18 LDOO | | | C609 1 мкФ X7R → GND (выход внутреннего LDO, наружу не нагружать) |
| 19 DGND | | | GND |
| 20 DVDD | | | 3V3D; C610 100 нФ + C611 10 мкФ |
| TP601, TP602 | | | `DAC_L`, `DAC_R` |

**Расчёт:** RC 470 Ом / 2.2 нФ (fc ≈ 154 кГц) — рекомендованный даташитом фильтр внеполосного шума.
Нагрузка на `DAC_L`: ГРОМКОСТЬ 10 к ‖ делитель наушников 20 к ≈ 6.7 кОм — 470 Ом дают −6.6 % шкалы на ВЫХ при громкости
на максимуме; на `DAC_R` (нагрузка ~1 МОм входа ОУ) — 0 %. Это **убирается программной калибровкой выходов** (план Ж0.3):
требование «×1 в крайнем положении» (Т-9.2) выполняется для всей цепочки после калибровки. Если нужна точность без
калибровки — R601 = 100 Ом, C605 = 10 нФ (та же fc, −1.5 %).

**Разводка:** конденсаторы накачки (C603, C604) и LDOO — вплотную к выводам; I2S от ПЛИС — короткие, с GND рядом.

## 7. Лист `aout`

### 7.1 Выходные усилители ВЫХ, ВЫХ2 (Т-9)

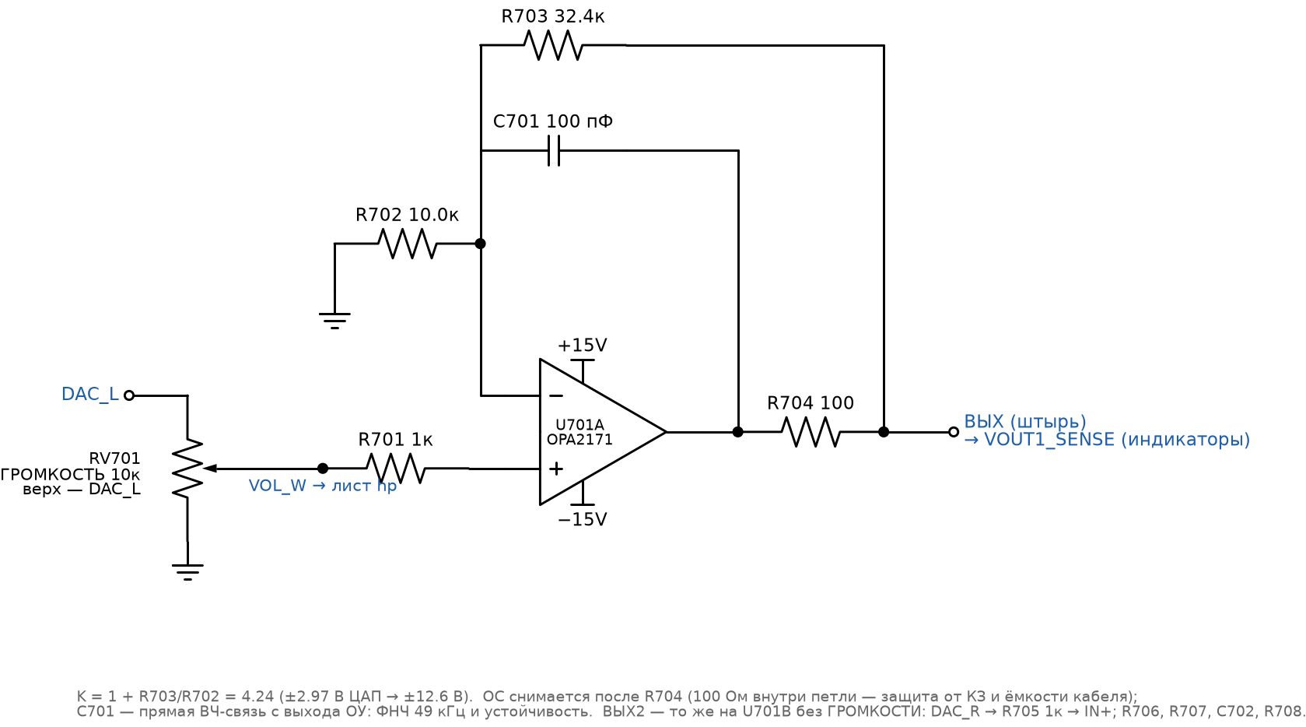
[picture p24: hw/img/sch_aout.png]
Выходной усилитель ВЫХ (ВЫХ2 — так же, без громкости)


| Поз. | Номинал / тип | Корпус | Подключение / примечание |
|---|---|---|---|
| RV701 | 10 кОм, логарифмический (A) или линейный (HO-04), на плату, вал с резьбовой втулкой; Ø ручки — крупная | 9 / 16 мм | 1 (низ) = GND, 3 (верх) = `DAC_L`, 2 (движок) = `VOL_W` |
| R701 | 1 кОм | 0603 | `VOL_W` → IN+ U701A (защита входа, развязка от ёмкости) |
| U701 | OPA2171 (±18 В, RRO, малый входной ток) | SOIC-8 | 1 OUTA, 2 IN−A, 3 IN+A, 4 V− = −15V, 5 IN+B, 6 IN−B, 7 OUTB, 8 V+ = +15V |
| C703, C704 | 100 нФ | 0603 | V+ и V− U701, у выводов; C705, C706 10 мкФ / 25 В на группу |
| R702 / R706 | 10.0 кОм 0.1 % | 0603 | IN− → GND (Rg) |
| R703 / R707 | 32.4 кОм 0.1 % | 0603 | **ВЫХ / ВЫХ2 (после R704 / R708)** → IN− (Rf: ОС с нагрузки, Т-9.5) |
| C701 / C702 | 100 пФ C0G | 0603 | **OUT ОУ** → IN− (ВЧ-обратная связь мимо R704 — устойчивость на ёмкость кабеля + ФНЧ) |
| R704 / R708 | 100 Ом | 0805 | OUT ОУ → штырь ВЫХ / ВЫХ2 (защита от КЗ и ёмкости, внутри петли ОС) |
| R705 | 1 кОм | 0603 | `DAC_R` → IN+ U701B |
| TP701, TP702 | | | ВЫХ, ВЫХ2 |

**Расчёт:** K = 1 + 32.4/10.0 = 4.24 → полная шкала ЦАП ±2.97 В → ±12.6 В; МЕ ±10 В при 0.79 FS (Т-9.1).
ФНЧ: 1/(2π·32.4 к·100 пФ) ≈ 49 кГц (Т-9.6). Выходное сопротивление на НЧ ≈ 100 Ом / (петлевое усиление) < 0.1 Ом (Т-9.5).
КЗ на GND: ток ограничен ОУ (~±35 мА у OPA2171) и 100 Ом; рассеяние в SOIC-8 ≈ 0.5 Вт на канал в худшем случае —
кратковременно допустимо; длительное КЗ обоих каналов — проверить нагрев на макете (план, А4.6).

### 7.2 Индикаторы перегрузки +10 / −10 (Т-10)

Все четыре компаратора LM339 питаются от +15 / −15 (вывод 3 VCC = +15V, вывод 12 GND = **−15V**): тогда входной диапазон
−15…+13.5 В охватывает и ±10 В, и 0 В, а открытый коллектор тянет выход к −15 В.

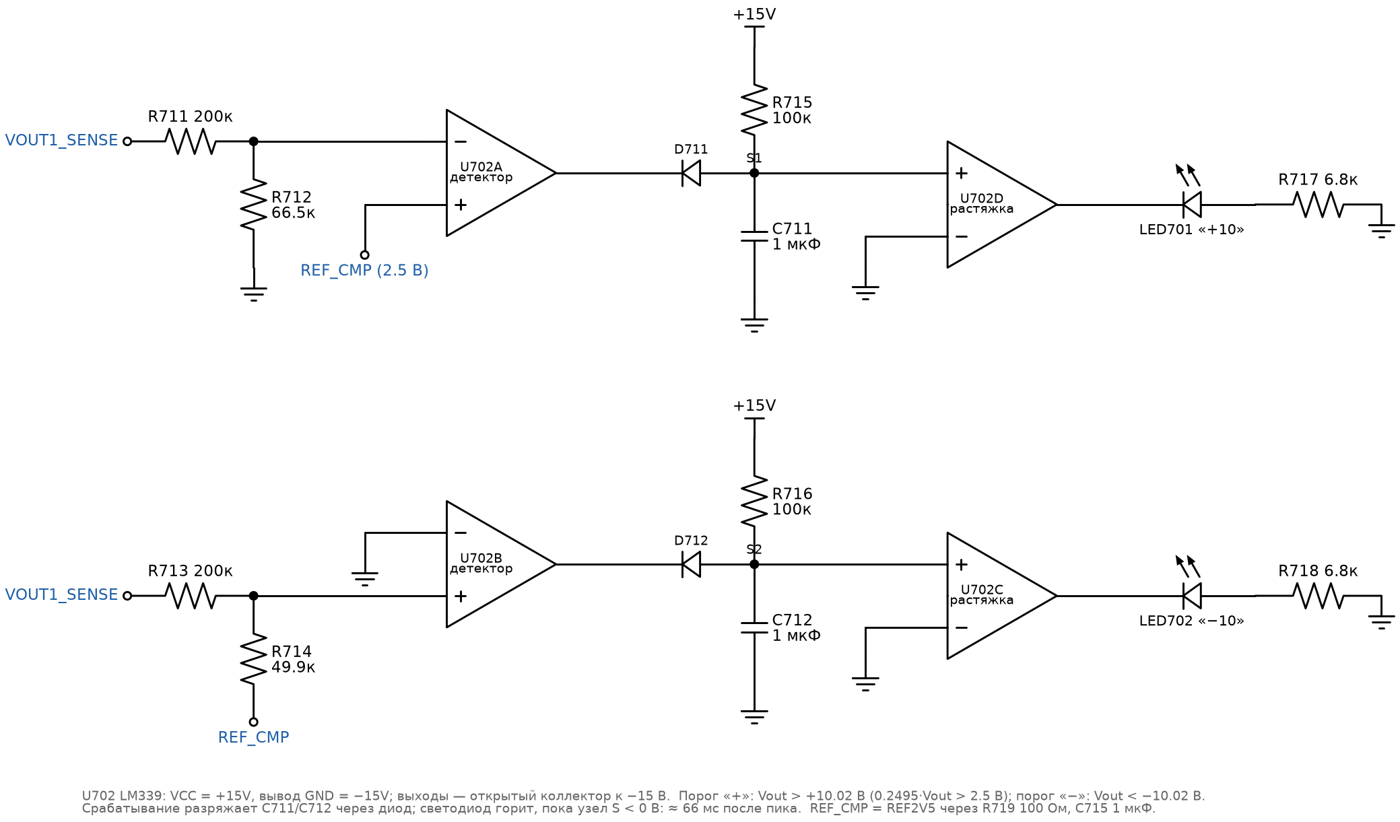
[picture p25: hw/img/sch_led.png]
Индикаторы перегрузки +10 / −10


| Поз. | Номинал / тип | Корпус | Подключение / примечание |
|---|---|---|---|
| U702 | LM339 (4 компаратора, открытый коллектор) | SOIC-14 | 1 OUT2, 2 OUT1, 3 VCC = +15V, 4 IN1−, 5 IN1+, 6 IN2−, 7 IN2+, 8 IN3−, 9 IN3+, 10 IN4−, 11 IN4+, 12 GND = −15V, 13 OUT4, 14 OUT3 |
| C713, C714 | 100 нФ | 0603 | VCC и «GND» (−15V) U702 |
| R711 / R712 | 200 кОм / 66.5 кОм | 0603 | делитель ВЫХ → IN1− (порог +10.02 В) |
| R713 / R714 | 200 кОм / 49.9 кОм | 0603 | сумматор ВЫХ и `REF_CMP` → IN2+ (порог −10.02 В) |
| R719, C715 | 100 Ом, 1 мкФ | 0603 | `REF2V5` → `REF_CMP` (развязка опоры АЦП от бросков компараторов; 100 Ом последовательно с R714 сдвигают порог «−» всего на 0.02 В — больше не ставить) |
| D711, D712 | 1N4148W | SOD-123 | анод — узел S1/S2, катод — OUT1/OUT2 |
| R715, R716 | 100 кОм | 0603 | S1/S2 → +15V |
| C711, C712 | 1 мкФ X7R / 25 В | 0805 | S1/S2 → GND |
| LED701, LED702 | красный 3 мм повышенной яркости (на панель, Т-10) | THT | катод → OUT4 / OUT3, анод → R717 / R718 |
| R717, R718 | 6.8 кОм | 0603 | анод LED → GND |

**Как работает:**
- Детектор «+»: 0.2495·Vout > 2.5 В (Vout > +10.02 В) → IN1− > IN1+ → OUT1 открыт (−15 В) → через D711 быстро
  разряжает C711 до ≈ −14 В.
- Детектор «−»: (Vout/200к + 2.5/49.9к) < 0 (Vout < −10.02 В) → IN2+ < IN2− → OUT2 открыт → разряжает C712.
- Растяжка: пока S < 0 В, IN+ < IN− → OUT открыт → светодиод горит, ток (15 − 1.8) / 6.8 к ≈ 1.9 мА.
  После превышения S заряжается через 100 к к +15 В; от −14 В до 0 В — τ·ln(29/15) ≈ 66 мс (Т-10.2: ≥ 50 мс).
- Нагрузка на ВЫХ: 266.5 к ‖ 249.9 к ≈ 129 кОм (Т-10.3: ≥ 100 кОм). Порог ±10.02 В ±0.25 В при 0.1 % делителях и 0.2 % опоре.

## 8. Лист `hp` — наушники / линейный (Т-9a)

| Поз. | Номинал / тип | Корпус | Подключение / примечание |
|---|---|---|---|
| R801, R802 | 10 кОм / 10 кОм | 0603 | `VOL_W` → R801 → узел HP_IN → R802 → GND (×0.5) |
| C801, C802 | 1 мкФ (плёнка PPS / X7R 16 В) | 0805 | HP_IN → INL+ (2), HP_IN → INR+ (3) |
| C808, C809 | 1 мкФ (как C801/C802) | 0805 | INL− (1) → GND, INR− (4) → GND: **входы TPA6132A2 дифференциальные**, «−» сажается на землю по переменному току через такой же конденсатор |
| U801 | TPA6132A2RTE (усилитель наушников DirectPath) | WQFN-16 3×3 | выводы по символу KiCad: 1 INL−, 2 INL+, 3 INR+, 4 INR−, 5 OUTR, 6 G0, 7 G1, 8 HPVSS, 9 CPN, 10 PGND, 11 CPP, 12 HPVDD, 13 EN, 14 VDD, 15 SGND, 16 OUTL, 17 EP |
| — VDD (14) | | | `3V3H`; C806 2.2 мкФ + C807 100 нФ |
| — накачка | | | C804 1 мкФ CPP–CPN; C805 1 мкФ HPVSS → GND; C810 1 мкФ HPVDD → GND (**проверить по даташиту**: возможно, HPVDD соединяется с VDD) |
| — PGND, SGND, EP | | | GND |
| — G0, G1 | | | R804, R805 0 Ом на GND — коэффициент 0 дБ проверить по таблице даташита (вариант +6 дБ — перестановкой перемычек) |
| — EN | | | `HP_EN`: `dac_xsmt` → R803 10 кОм → EN; C803 1 мкФ → GND (включение ≈ 10 мс после ЦАП, Т-9a.7) |
| — OUTL / OUTR | | | → J801 Tip / Ring напрямую (каждый наушник — свой канал, Т-9a.5) |
| J801 | гнездо 3.5 мм стерео на панель | THT | T = OUTL, R = OUTR, S = GND; на панели справа (у выходов) |
| D801, D802 | TVS PESD5V0S1BA (двунаправленные) | SOD-323 | T → GND, R → GND |
| TP801 | | | HP_IN |

**Расчёт:** полная шкала ЦАП на `VOL_W` 2.1 В rms → ×0.5 → ≈ 1.05 В rms на входе → при 0 дБ ≈ 1 В rms на выходе
(линейный уровень; на 32 Ом ≈ 31 мВт — ограничение самой микросхемы, Т-9a.3). Нижняя граница — от 1 мкФ и входного
сопротивления TPA6132A2 (единицы–десятки кОм по выбранному усилению): ≤ 5 Гц проверить по даташиту, при необходимости
C801/C802 и C808/C809 → 2.2 мкФ. Делитель 20 кОм нагружает движок громкости; учтено в листе `dac`.

**Альтернатива под ручную пайку** (если QFN неудобен): NJM4556A (SOIC-8) от ±9 В (78L09 / 79L09 от ±15 В),
канал A → Tip, B → Ring, по 10 Ом в выходе, вход 1 мкФ + 100 кОм на GND, усиление ×1 (повторитель). Защита от
длительного КЗ хуже (Т-9a.6) — оставить посадочное место только если TPA6132A2 недоступен.

## 9. Лист `panel`

### 9.1 Потенциометры и MCP3208 (Т-11)

| Поз. | Номинал / тип | Корпус | Подключение / примечание |
|---|---|---|---|
| RV901…RV908 | B10K, 9 мм, вертикальный, на плату, вал с резьбовой втулкой | THT | 1 = GND, 3 = `3V3A` (VREF), 2 → R90x; порядок: RV901 СРЕЗ, RV902 РЕЗОН., RV903 ENV→Ф, RV904 FX MIX, RV905 A, RV906 D, RV907 S, RV908 R |
| R901…R908 | 1 кОм | 0603 | движок → CHx |
| C901…C908 | 100 нФ | 0603 | CHx → GND, у MCP3208 |
| U901 | MCP3208 | SOIC-16 | 1…8 CH0…CH7 (= RV901…RV908), 9 DGND, 10 CS/SHDN = `pot_cs_n`, 11 DIN = `pot_mosi`, 12 DOUT = `pot_miso`, 13 CLK = `pot_sck`, 14 AGND, 15 VREF, 16 VDD |
| — VDD, VREF | | | `3V3A`; C909 100 нФ + C910 1 мкФ у VDD; VREF — от той же `3V3A` через R909 10 Ом + C911 1 мкФ (общая точка с верхними выводами потенциометров → ратиометрия, Т-11.2) |
| R910 | 10 кОм | 0603 | `pot_cs_n` → 3V3D (АЦП выключен до конфигурации ПЛИС) |

Порядок каналов CH0…CH7 = порядок ручек в прошивке (`panel` в консоли, план А3.4) — при ином порядке разводки
поправить таблицу в прошивке, а не схему.

### 9.2 Энкодеры (Т-12) — на каждый из 4 (n = 0…3)

| Поз. | Номинал / тип | Корпус | Подключение / примечание |
|---|---|---|---|
| SW90n | EC11 с кнопкой (вал 20 мм, 20–30 щелчков) | THT | C (общий) = GND; A, B, кнопка (второй вывод кнопки — GND) |
| R92n, R93n, R94n | 10 кОм | 0603 | подтяжки A, B, кнопки → 3V3D (у энкодера) |
| R95n, R96n, R97n | 10 кОм | 0603 | A → `enc_a[n]`, B → `enc_b[n]`, кнопка → `enc_sw[n]` |
| C92n, C93n, C94n | 10 нФ | 0603 | `enc_a/b/sw[n]` → GND (у ПЛИС; τ = 100 мкс) |

SW900 = МЕНЮ (`enc_*[0]`), SW901 = ПАР.1, SW902 = ПАР.2, SW903 = ПАР.3. Активный уровень — низкий (как ждёт RTL).

### 9.3 Дисплей (Т-13)

| Поз. | Номинал / тип | Корпус | Подключение / примечание |
|---|---|---|---|
| J901 | гнездо 1×8, 2.54 (или FPC — по выбранному модулю) | THT | 1 GND, 2 VCC = 3V3D, 3 SCL = `lcd_sck`, 4 SDA = `lcd_mosi`, 5 RES = `lcd_rst_n`, 6 DC = `lcd_dc`, 7 CS = `lcd_cs_n`, 8 BLK (порядок выводов — **по модулю**) |
| C912 | 10 мкФ + 100 нФ | 0805 / 0603 | VCC дисплея |
| R911 | 100 Ом | 0603 | `lcd_bl` → BLK (вариант 1: у модуля свой ключ подсветки, вход BLK — логический) |
| Q901, R912, R913 | AO3400 (SOT-23: 1 G, 2 S, 3 D), 100 Ом в затвор, 100 кОм затвор → GND — **не устанавливать в варианте 1** | SOT-23 | вариант 2 (BLK — прямо анод подсветки, ~20 мА): BLK → 3V3D через токовый резистор модуля, катод подсветки → D Q901, S → GND, G ← `lcd_bl` |

Какой вариант — по конкретному модулю (Т-13.2): у большинства модулей ST7789 1.14″ вход BLK логический (вариант 1).

### 9.4 Панельные штыри

| Поз. | Тип | Подключение |
|---|---|---|
| J911…J914 | контактные площадки / гнездо 1×1 под провод к штырю 2РМТ | J911 = ВХ1 → R401, J912 = ВХ2 → R451, J913 = ВЫХ ← R704, J914 = ВЫХ2 ← R708 |

Земля на панель не выводится (Т-14.2).

## 10. Сводная таблица цепей ПЛИС ↔ листы

| Цепь RTL | Лист / элемент | Подтяжка / защита |
|---|---|---|
| `midi_rx` | U301 Vo | R302 2.2 к к 3V3D, R303 33 Ом |
| `sync_in` | U302 Y | R306 33 Ом |
| `adc_convst_n`, `adc_cs_n`, `adc_sclk` | U501, U502 | 33 Ом на SCLK у ПЛИС |
| `adc_sdo1`, `adc_sdo2` | U501, U502 SDO | — |
| `i2s_bck`, `i2s_lrck`, `i2s_din` | U601 | 33 Ом у ПЛИС |
| `dac_xsmt` | U601 XSMT (R603/R604), U801 EN (R803/C803) | R604 10 к к GND |
| `pot_sck`, `pot_mosi`, `pot_miso`, `pot_cs_n` | U901 | R910 10 к к 3V3D на CS; 33 Ом на SCK |
| `enc_a/b/sw[3:0]` | SW900…SW903 | 10 к к 3V3D + 10 к / 10 нФ |
| `lcd_*` | J901 | 33 Ом на SCK |
| `flash_*` | U201 | R201 10 к к 3V3D на CS; 33 Ом на SCK |

## 11. Что проверить по даташитам при рисовании

| # | Что | Где |
|---|---|---|
| 1 | Цоколёвка и отключение внутренней опоры AD7091R при внешней на REFIN (HO-09), номинал конденсатора на REFIN/REFOUT и REGCAP | лист `adc` |
| 2 | Цоколёвка PCM5102A (TSSOP-20), номиналы накачки и LDOO | лист `dac` |
| 3 | TPA6132A2: выводы, G0/G1 для 0 дБ, полярность и пороги EN, входное сопротивление (нижняя граница), конденсаторы накачки | лист `hp` |
| 4 | Цоколёвка H11L1 (DIP-6 / SMD) | лист `midi_sync` |
| 5 | Распиновка гребёнок Tang Nano 20K: 5 V, GND, свободные GPIO в банках 3.3 В (HO-01) | лист `fpga` |
| 6 | Распиновка нижнего разъёма АВК-6 (HO-06) | лист `power` |
| 7 | Модуль дисплея: порядок выводов и тип входа BLK | лист `panel` |
| 8 | Допустимая ёмкость на выходе выбранной опоры 2.5 В | лист `power` |

## 12. Перечень элементов (сводно)

| Тип | Поз. | Кол-во |
|---|---|---|
| ЦАП PCM5102A | U601 | 1 |
| АЦП AD7091R | U501, U502 | 2 |
| АЦП MCP3208 | U901 | 1 |
| ОУ OPA2350 / TLV9062 (3.3 В) | U401 | 1 |
| ОУ OPA2171 (±15 В) | U701 | 1 |
| Компаратор LM339 | U702 | 1 |
| Усилитель наушников TPA6132A2 | U801 | 1 |
| Оптрон H11L1 | U301 | 1 |
| 74LVC1G17 | U302 | 1 |
| SPI NOR W25Q64JV | U201 | 1 |
| LP5907-3.3 / AP2112K-3.3 | U101 / U102, U103 | 1 / 2 |
| Опора REF3025 (или REF3325 / ADR361) | U104 | 1 |
| SS14 | D102…D104 | 3 |
| BAT54S | D301…D303, D401, D451 | 5 |
| 1N4148W | D711, D712 | 2 |
| TVS для наушников | D801, D802 | 2 |
| AO3400 (опционально) | Q901 | 0–1 |
| Ферритовые бусины | FB101…FB103 | 3 |
| Потенциометры B10K 9 мм / ГРОМКОСТЬ 10 к | RV901…RV908 / RV701 | 8 / 1 |
| Энкодеры EC11 с кнопкой | SW900…SW903 | 4 |
| Светодиоды 3 мм красные | LED701, LED702 | 2 |
| Гнёзда 3.5 мм TRS на панель | J301, J801 | 2 |
| Гнёзда 1×20 под Tang Nano | J201, J202 | 2 |
| Гнездо дисплея 1×8 | J901 | 1 |
| Нижний разъём АВК | J101 | 1 |
| Резисторы 0.1 % | R401–R404, R451–R454, R702, R703, R706, R707, (R711–R714 — 0.1 % желательно) | 12 (+4) |

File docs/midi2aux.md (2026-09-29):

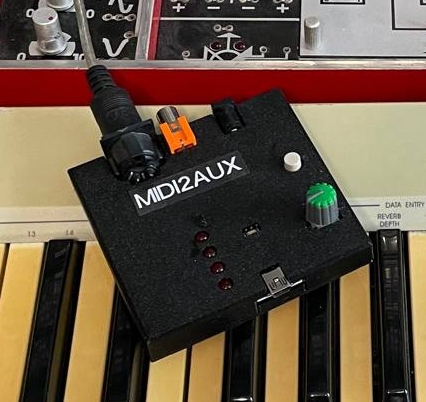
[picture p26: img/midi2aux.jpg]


# MIDI→AUX Converter

> Исходный README модуля MIDI2AUX (Arduino Nano). Главная страница репозитория — [README.md](../README.md): FPGA-синтезатор для АВК-6.

Firmware for Arduino Nano (ATmega328P) that converts MIDI Note-On/Off messages into analog audio waveforms. Part of the АВК-6 «Музыкальная пауза» project.

## Hardware

| Pin | Function |
|-----|---|
| PD0 | MIDI input (RX via optocoupler, 31250 baud) |
| PD2 | Optocoupler enable (active HIGH) |
| PD3 | Audio PWM output (OC2B → RC filter, 160 kHz) |
| PC0 | Potentiometer (ADC0, 0–5V) |
| PC1 | Button (internal pull-up, mode switch + note off on press) |
| PD4 | LED — Square wave |
| PD5 | LED — Triangle wave |
| PD6 | LED — Sawtooth wave |
| PD7 | LED — Sine wave |

## Waveform Modes

| Mode | Waveform | Potentiometer effect |
|---|---|---|
| 0 | Square | Duty cycle (0–100%) |
| 1 | Triangle | Rise/fall split point |
| 2 | Sawtooth | Ramp duration |
| 3 | Sine | None (fixed) |

Short press the button to cycle modes. Note is silenced on press.

## Building & Upload

```bash
pio run                 # build
pio run --target upload # build & upload
```

Remove MIDI jumper before upload — optocoupler gate (PD2) isolates RX.

## Architecture

Fully interrupt-driven. Main loop does nothing but sleep (`SLEEP_MODE_IDLE`).

| Subsystem | Timer | Interrupt | Priority | Description |
|---|---|---|---|---|
| Button | Timer1 | `TIMER1_COMPA_vect` | **High** | 10 ms tick, debounce 30 ms, calls `noteOff()` on press |
| Waveform | Timer0 | `TIMER0_COMPA_vect` | Low | Generates PWM sample at note × 64 Hz |
| Audio PWM | Timer2 | — | — | 160 kHz Fast PWM on PD3, OCR2B updated by waveform ISR |
| ADC | — | `ADC_vect` | — | Free-running, updates `potValue` every 104 µs |
| MIDI | — | `USART_RX_vect` | — | Calls `midiParser()` directly, no buffers |

### Timer0 Prescaler

| Period | Prescaler | OCR0A range |
|---|---|---|
| < 2040 | 8 | 62–254 |
| ≥ 2040 | 64 | 32–238 |

OCR0A clamped to ≥ 350 (44 µs period at prescaler 8) to prevent ISR cascade on high notes.

### Memory

| Resource | Used | Free |
|---|---|---|
| Flash | 2586 bytes (8.4%) | 28134 bytes |
| RAM | 74 bytes (3.6%) | 1974 bytes |

## Project Structure

```
platformio.ini
fw/src/
├── main.cpp          # init, sleep loop
├── uart.h / uart.cpp # MIDI UART (RX-only, ISR-driven)
├── midi.h / midi.cpp # Note period table, MIDI parser, noteOn/noteOff
└── waveform.h / waveform.cpp  # Sine table, waveform ISR, 4 modes
```

---

*Project created with [KiloCode](https://github.com/Kilo-Org/kilocode) agent, model `deepseek/deepseek-v4-pro`.*

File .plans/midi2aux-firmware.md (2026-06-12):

# MIDI→AUX Converter Firmware Plan

## Overview

Firmware for Arduino Nano (ATmega328P) that converts MIDI Note-On/Off messages into analog audio waveforms. Part of the АВК-6 "Музыкальная пауза" project.

## Hardware Pinout

| Pin | Function |
|---|---|
| PD0 | MIDI input (RX via optocoupler, collector pull-up to +5V) |
| PD1 | Free (TX, unused) |
| PD3 | Audio PWM output (OC2B) → RC filter → output capacitor |
| PC0 | Potentiometer (ADC0, 0–5V) |
| PC1 | Button (internal pull-up) |
| PD4 | LED0 – Square wave |
| PD5 | LED1 – Triangle wave |
| PD6 | LED2 – Sawtooth wave |
| PD7 | LED3 – Sine wave |

- PD3 = D3 (OC2B) — PWM audio OUT
- PD4–PD7 = D4–D7 — 4 LEDs (as per spec)

## Project Structure

```
C:\home\midi2aux\
├── platformio.ini
├── fw/
│   └── src/
│       ├── main.cpp          # Entry point, setup(), main loop
│       ├── uart.cpp          # Peter Fleury UART (single USART, adapted)
│       ├── uart.h
│       ├── midi.cpp          # Note period table, noteOn/noteOff, MIDI parser
│       ├── midi.h
│       ├── waveform.cpp      # Sine table init, Timer1 ISR, waveform compute
│       └── waveform.h
```

## Architecture

### 1. MIDI Input (USART0 @ 31250 baud)
- Peter Fleury UART library (`ATMEGA_USART0` for ATmega328P)
- Single USART — use `uart_init()`, `uart_getc()`, `uart_available()`
- MIDI parser: collect 3-byte packets (Note On 0x90 / Note Off 0x80)
- Note On velocity>0 → `noteOn(note)`; velocity=0 or Note Off → `noteOff()`
- System Stop (0xFC) → `noteOff()`

### 2. Note→Frequency (from BrainfuckPC reference)
```cpp
uint32_t notes[12] = { 1956947, 1847042, 1743489, 1646090, 1553247, 1466074,
                       1384083, 1306122, 1233141, 1163636, 1098524, 1036672 };

uint16_t getNotePeriod(uint8_t note) {
    uint8_t octave = note / 12;
    uint8_t semi   = note % 12;
    uint32_t fp    = notes[semi] >> octave;
    return (uint16_t)(fp >> 6);  // prescaler=1 → divide by 64
}
```
- This yields `OCR1A = F_CPU / (128 * freq_note) - 1` → Timer1 period for note*64 Hz
- Default octaves: contra (note 24) to third (note 64)

### 3. Timer2 – PWM (160kHz, 100 steps)
- Mode 7: Fast PWM, OCR2A as TOP
- `OCR2A = 99` → `f = 16e6 / 100 = 160kHz`
- Output on PD3 (OC2B), duty cycle = `OCR2B` (0–99)
- `TCCR2A = (1<<COM2B1) | (1<<WGM21) | (1<<WGM20)`
- `TCCR2B = (1<<WGM22) | (1<<CS20)` — prescaler 1

### 4. Timer1 – System Timer (note*64 Hz)
- CTC mode 4, prescaler = 1
- `OCR1A` = period from `getNotePeriod(note)`
- `TIMSK1 = (1<<OCIE1A)`
- ISR fires 64 times per note cycle, computes next PWM value
- Phase counter `phase` (0–63) increments each ISR

### 5. Waveform Generation (4 modes)

Phase counter `phase` (0–63) increments each Timer1 ISR. Pot value `pot` (0–255) from ADC.

| Mode | Pot effect | Computation |
|---|---|---|
| 0 - Square | Duty cycle (0–100%) | `OCR2B = (phase < pot*64/255) ? 99 : 0` |
| 1 - Triangle | Rise/fall split | pot determines split point; linear ramp up then down |
| 2 - Sawtooth | Ramp duration | pot determines ramp duration; linear up then 0 |
| 3 - Sine | **No effect** | 16-entry quarter-wave table lookup |

### 6. Sine Table (16 entries, quarter wave)
- Computed at startup: `sine[i] = sin(i * π / 32) * 49` (0–49)
- Centered at 50 (midpoint of 0–99 PWM range):
  - Q1 (phase 0–15):  `50 + sine[phase]`
  - Q2 (phase 16–31): `50 + sine[31-phase]`
  - Q3 (phase 32–47): `50 - sine[phase-32]`
  - Q4 (phase 48–63): `50 - sine[63-phase]`

### 7. Button & LEDs
- Button on PC1: short press cycles mode 0→1→2→3→0
- Debounce: ~30ms
- LEDs active high on PD4–PD7

### 8. ADC
- PC0 (ADC0), 8-bit via ADCH (ADLAR=1)
- Read in main loop, `volatile uint8_t potValue` (0–255)

### 9. Main Loop Pseudocode
```
loop:
    read ADC → potValue
    if button short press (debounced):
        waveMode = (waveMode+1) % 4
        update LEDs (PD4–PD7)
        wait release
    if uart data available:
        midiParser(uart_getc())
```

### 10. noteOn / noteOff
```
noteOn(note):
    period = getNotePeriod(note)
    OCR1A = period
    TCNT1 = 0
    TCCR1B |= (1<<CS10)  // start timer
    TIMSK1 |= (1<<OCIE1A)

noteOff():
    TCCR1B &= ~((1<<CS12)|(1<<CS11)|(1<<CS10))  // stop timer
    TIMSK1 &= ~(1<<OCIE1A)
    OCR2B = 0  // silence PWM
```

## Implementation Order

1. Create `platformio.ini` (bare AVR-GCC, board nanoatmega328)
2. Copy & adapt `uart.h`/`uart.cpp` — strip uart2/uart3, keep single USART
3. Create `midi.h`/`midi.cpp` — note table, period calc, MIDI parser state machine
4. Create `waveform.h`/`waveform.cpp` — sine table init, Timer1 ISR, 4 waveforms
5. Create `main.cpp` — timer init, GPIO, ADC, main loop
6. Build: `pio run`
7. Upload: `pio run --target upload`

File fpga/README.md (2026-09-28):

# FPGA-синтезатор для АВК-6 — RTL, симуляция, модели

ТЗ и план: [`.plans/fpga-synth/`](../.plans/fpga-synth/). Сейчас реализован **этап 0** (инфраструктура):
заглушечное ядро `stub_core` — синус 440 Гц в левый канал и пила в правый через I2S, эхо байтов MIDI
для тестбенча, «мигалка».

Графики и результаты: симуляция — [`sim/README.md`](sim/README.md), модели — [`model/README.md`](model/README.md).

## Структура

```
fpga/
  rtl/                 переносимый RTL (без примитивов производителя)
    files.f            список файлов — общий для Verilator и Gowin EDA
    stub_core.sv       ядро этапа 0
    audio/             audio_clkgen (BCK/LRCK/audio_tick), i2s_tx, nco_sine,
                       sine_quarter_rom.sv (генерируется: make luts)
    midi/              uart_rx, uart_tx, midi_parser
    common/            sync_fifo
    soc/               шина PicoRV32: RAM, boot ROM (генерируется: make bootrom), периферия, SPI
    voice/             voice_engine (голоса с разделением по времени), mod_unit (LFO, матрица)
    panel/             ручки (MCP3208), энкодеры, контроллер ST7789
    avk/               связь с АВК: АЦП ВХ1/ВХ2 + дециматор, СИНХР, шина сигналов, слоты (MATH, DELAY)
    mem/               внешняя память: арбитр, BRAM, контроллер SDRAM
    third_party/       PicoRV32 (ISC), без изменений
    mono_core.sv       ядро этапа 1 (один голос, без процессора)
    synth_core.sv      ядро с этапа 2 (PicoRV32 + звуковой тракт)
    lint.vlt           исключения линта (third_party, board-top)
  boards/
    tang_nano_9k/      top_synth.sv / top_mono.sv, pll_sys.v (rPLL), .cst на каждое ядро, .sdc, build.tcl
    tang_nano_20k/     то же для 20K
  sim/
    tb/tb_audio.cpp    общий тестбенч Verilator для ядер: MIDI → ядро → декодер I2S → WAV + JSON
    system/            системные тесты (pytest): сборка, прогон, анализ WAV, графики
    unit/              юнит-тесты блоков RTL (cocotb + Verilator), сравнение с моделями
    stimuli/           файлы стимулов MIDI
    gowin_stubs/       заглушки примитивов Gowin для линта board-top
  model/
    synthmodel/        Python-модели: clocks, nco, adsr, svf, analysis, wavio, luts
    tests/             pytest
    gen_refs.py        эталонные WAV + графики моделей
  requirements.txt
```

## Установка (Ubuntu 24.04)

```bash
sudo apt-get install verilator gcc-riscv64-unknown-elf make g++   # Verilator 5.020, GCC 13
pip install -r fpga/requirements.txt                               # numpy, scipy, matplotlib, pytest
```

Другие дистрибутивы: Verilator ≥ 5.0 (из пакетов или из исходников), любой RISC-V GCC —
`riscv64-unknown-elf-gcc` или xPack `riscv-none-elf-gcc`; префикс определяется автоматически,
можно задать явно: `make fw CROSS=riscv-none-elf-`.

## Команды (из корня репозитория)

| Команда | Что делает |
|---|---|
| `make lint` | `verilator --lint-only -Wall`: ядро и оба board-top (с заглушкой `rPLL`) |
| `make unit` | юнит-тесты блоков RTL (cocotb) |
| `make sim` | системные тесты: ядро целиком, MIDI → WAV → проверки |
| `make model` | pytest моделей + эталонные WAV в `build/model/` |
| `make fw` | прошивка RISC-V → `build/sw/fw.{elf,bin,hex,map}` |
| `make test` | `lint` + `model` + `unit` + `sim` — то же, что проверяет CI (кроме `fw`) |
| `make all` | `test` + `fw` |
| `make luts` | перегенерировать `rtl/audio/sine_quarter_rom.sv` из модели |
| `make plots` | `sim` + `refs` и обновить графики в `sim/img/`, `model/img/` |
| `make bitstream-9k`, `make bitstream-20k` | Gowin EDA, только локально |

Отдельный тест: `python3 -m pytest -q fpga/sim/system/test_mono_core.py`.

Результаты в `build/sim/<тест>/`: WAV (стерео, 24 бит — можно послушать), PNG (осциллограммы, спектры),
JSON (сводка тестбенча). В CI — артефакты `sim-results`, `model-refs`, `firmware` на странице запуска workflow.

## Что проверяется

Тестбенч (`tb/tb_audio.cpp`, код возврата ≠ 0 при ошибке):
- формат I2S на уровне выводов, как его принимает ЦАП: LRCK/DIN меняются только по спаду BCK,
  32 такта BCK на слот, MSB через такт после фронта LRCK, биты ниже `DATA_W` — нули, период BCK постоянный;
- MIDI: байты из файла стимулов передаются на `midi_rx` с таймингом 31250 бод; принятые ядром байты
  совпадают с отправленными (ядра с `-DMIDI_ECHO`).

`system/test_stub_core.py` (этап 0):
- fs = sys_clk / (128 · BCK_HALF), отклонение от 48 кГц ≤ 3 %;
- L (синус): основной тон 440 Гц ± 0.5 %, THD ≤ −70 дБ, THD+N ≤ −60 дБ, пик 0.99…1.0 FS;
- R (пила): основной тон ± 0.5 %, H2/H1 = −6 ± 1 дБ;
- оба канала **побитово** совпадают с моделью `synthmodel.nco`.

`system/test_mono_core.py` (этап 1): частота каждой ноты ± 0.1 % (running status, Note On vel 0,
байт realtime внутри сообщения, omni, pitch bend ±2 полутона), гейт на R, тишина после Note Off,
All Notes Off и Stop, задержка MIDI → звук ≤ 3 мс.

Юнит-тесты (`unit/`): `uart_rx` (рассогласование скорости ±3 %, ошибка стопа, помеха), `sync_fifo`,
`midi_parser` (случайные потоки против `synthmodel.midi`), `pitch2inc` (побитово с `synthmodel.pitch`,
точность < 0.02 цента), `dac_scale`; далее — голоса, модуляция, панель, блоки `avk/` (подробно по этапам —
в [`sim/README.md`](sim/README.md)).

### Формат стимулов MIDI

Текст, строка — `<время_мс> <байт hex> [<байт hex> …]`, `#` — комментарий. Байты строки идут
подряд с указанного времени (или сразу после предыдущего сообщения, если оно ещё передаётся).
Пример — `sim/stimuli/stub_midi.txt`; тесты генерируют стимулы сами (`vsys.write_midi`). Входы ВХ1/ВХ2 из файлов подключатся к тестбенчу вместе
с моделью АЦП (этап 6), сейчас у ядра этих входов нет.

## Тактирование

Кварц 27 МГц → rPLL → sys_clk **99 МГц** (27 · 11 / 3, VCO 792 МГц).
BCK = sys_clk / (2 · 16) = 3.094 МГц = 64 · fs, **fs = 48 339.84 Гц** (+0.7 % от 48 кГц).
Инкремент фазы NCO считается от фактической fs (`synthmodel.clocks`, `stub_core.sv`).
Для другой sys_clk достаточно поменять `SYS_CLK_HZ` — делитель BCK выбирается автоматически
(нужно sys_clk ≥ 256 · fs).

## Gowin EDA (битстрим, локально)

В CI Gowin EDA нет. Нужна Gowin EDA (Education достаточно) с `gw_sh` в `PATH`:

```bash
make bitstream-9k             # synth_core → build/gowin/9k-synth/impl/pnr/avk_synth_9k.fs
make bitstream-9k CORE=mono   # mono_core (этап 1, без процессора)
make bitstream-20k            # → build/gowin/20k-synth/impl/pnr/avk_synth_20k.fs
openFPGALoader -b tangnano9k build/gowin/9k-synth/impl/pnr/avk_synth_9k.fs       # в SRAM
openFPGALoader -b tangnano20k -f build/gowin/20k-synth/impl/pnr/avk_synth_20k.fs # во флеш
```

После прошивки битстрима `synth_core` загрузить прошивку: `python3 sw/tools/load.py <порт> build/sw/fw.bin`
(см. [`sw/README.md`](../sw/README.md)).

Или в GUI: новый проект под нужный кристалл (9K: `GW1NR-LV9QN88PC6/I5`, 20K: `GW2AR-LV18QN88C8/I7`),
добавить файлы из `rtl/files.f`, `boards/<плата>/pll_sys.v`, `top_<ядро>.sv`, `<плата>_<ядро>.cst`, `.sdc`; top module — `top`,
Verilog Language — SystemVerilog 2017.

`build.tcl` проверен только «всухую» (на заглушках команд `gw_sh`): при первой сборке могут
понадобиться правки опций под версию Gowin EDA. Для второго мнения RTL синтезируется и yosys:
`yosys -p "read_verilog -sv <files>; synth_gowin -top top"` (≈ 240 LUT, таблица синуса → BSRAM).

Светодиоды `synth_core`: 0–3 — GPIO прошивки (0 мигает), 4 — активность MIDI, 5 — trap процессора.
`mono_core`: 0 — мигание, 1 — событие MIDI, 2 — гейт, 3 — PLL, 4 — ЦАП включён.
Кнопки: S1 — сброс (9K: активный 0, 20K: активная 1), S2 — вход GPIO.

**Распиновка — предварительная (HO-01)**: I2S и MIDI на свободных выводах разъёмов
(9K и 20K: BCK 25, LRCK 26, DIN 27, XSMT 28, MIDI 29); UART BL702 — 9K: 17/18, 20K: 69/70;
SPI-флеш — 9K: встроенная на плате (59–62), 20K: внешняя на разъёме (73, 74, 75, 85). Перед подключением сверить со схемой
Sipeed; окончательная таблица пинов — после этапа 6.

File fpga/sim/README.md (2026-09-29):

# Симуляция (Verilator)

Запуск: `make sim` из корня. Как устроены тестбенч, стимулы и проверки — в [`../README.md`](../README.md#что-проверяется).

## Этап 0: `stub_core` — синус → I2S → WAV

Выход I2S, декодированный тестбенчем на уровне выводов (как принимает PCM5102A), 0.3 с симуляции,
sys_clk 99 МГц, fs = 48 339.84 Гц.

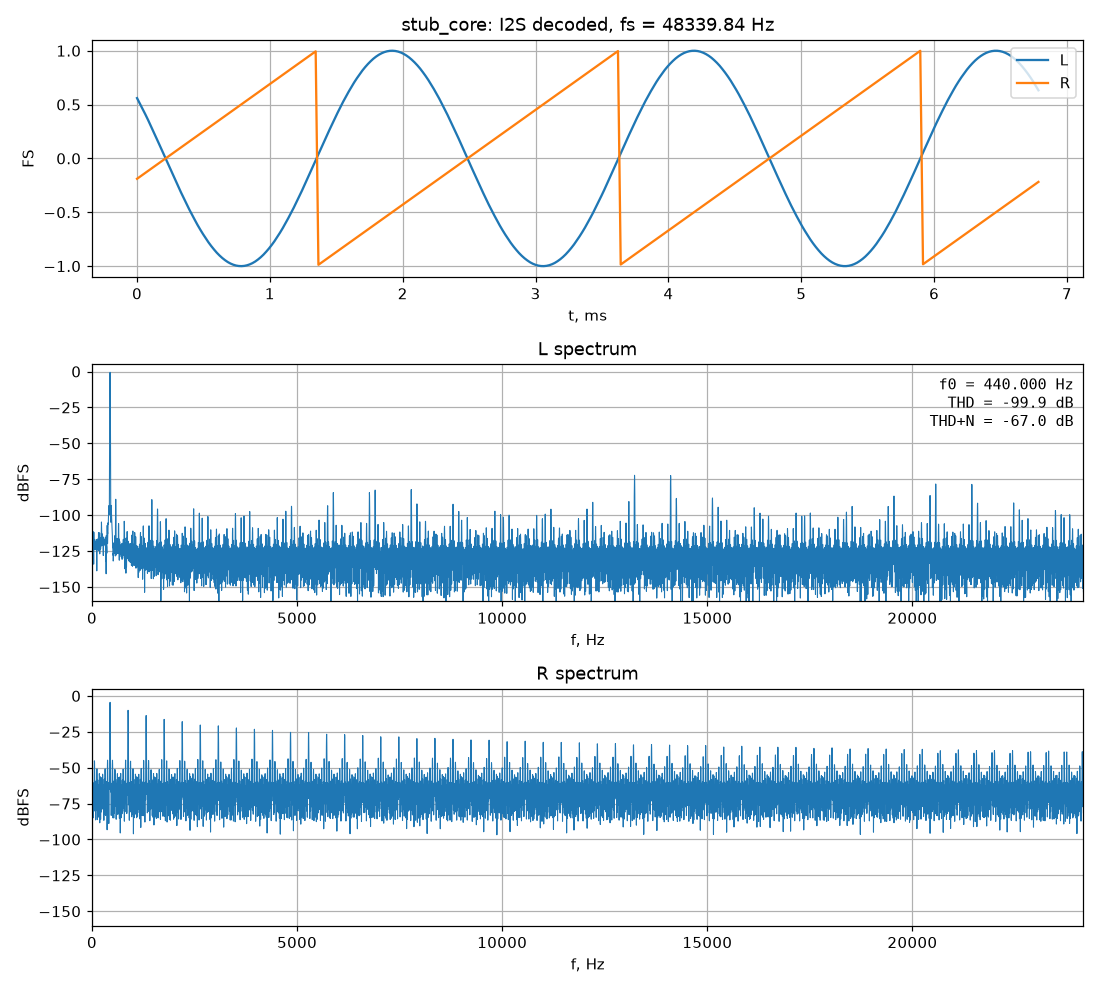
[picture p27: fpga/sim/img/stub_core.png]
stub_core: осциллограмма и спектры


- вверху — левый канал (синус 440 Гц) и правый (пила того же NCO);
- в середине — спектр синуса: THD ≈ −100 дБ, THD+N ≈ −67 дБ; шум и отдельные пики на −75…−90 дБ —
  от усечения фазы до 12 бит (таблица 1024 точки на четверть периода, без интерполяции);
- внизу — спектр пилы: гармоники спадают как 1/n (H2 = −6 дБ), выше — наложение спектров
  (наивная пила без PolyBLEP, P1).

Результаты проверок последнего прогона:

| Проверка | Значение | Допуск |
|---|---|---|
| Формат I2S, тайминг, эхо MIDI (22 байта) | ошибок нет | — |
| fs | 48 339.84 Гц (+0.71 %) | ≤ 3 % |
| Тон L | 440.000 Гц | 440 ± 0.5 % |
| THD / THD+N | −99.9 / −67.0 дБ | ≤ −70 / ≤ −60 дБ |
| Пик L | 0.99999 FS | 0.99…1.0 |
| Тон R (пила), H2/H1 | 439.999 Гц, −6.02 дБ | ± 0.5 %, −6.02 ± 1 дБ |
| L, R против `synthmodel.nco` | совпадают побитово | точно |

График в репозитории обновляется командой `make plots` (свежие графики каждого прогона — в артефактах CI).

## Этап 1: `mono_core` — MIDI → один голос

Одноголосное ядро без процессора (как MIDI2AUX): парсер MIDI, FIFO событий, последняя нота,
pitch bend ±2 полутона, меандр ±0.5 МЕ на ВЫХ (L) с плавным включением 2.6 мс, гейт +10 В на ВЫХ2 (R).
Тест `system/test_mono_core.py` проверяет частоту каждой ноты (± 0.1 %), гейт, тишину и задержку.

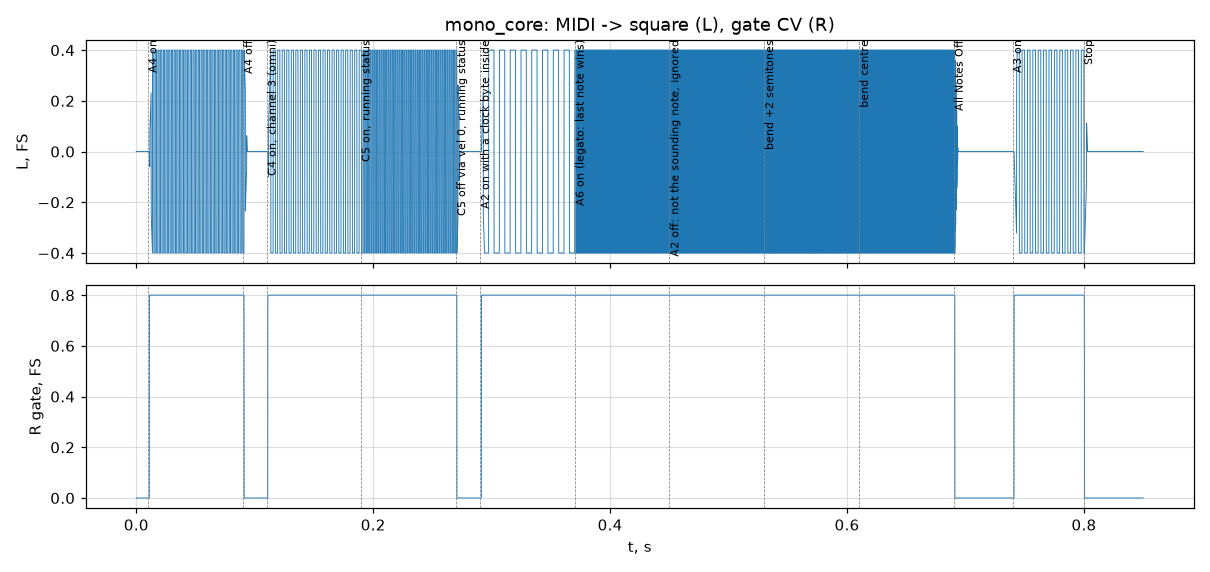
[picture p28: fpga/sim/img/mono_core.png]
mono_core: ноты, гейт


## Этап 3: `synth_core` — полифония

PicoRV32 с прошивкой (`sw/fw`) распределяет голоса и пишет регистры голосового движка
(`fpga/rtl/voice/voice_engine.sv`, 22 такта на голос, общий умножитель). Тест
`system/test_synth_core_voices.py` (4 голоса для скорости симуляции): аккорд C4–E4–G4 (все три
основных тона ± 0.2 %), затухание release до тишины, pitch bend +2 полутона, 6 нот на 4 голосах —
звучат последние четыре, две самые старые украдены.

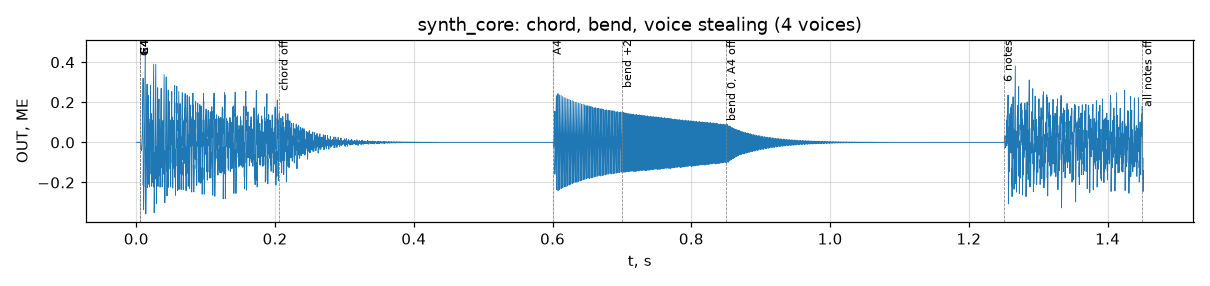
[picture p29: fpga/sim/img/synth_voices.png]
synth_core: аккорд, bend, кража голосов


Юнит-тест `unit/test_voice_engine.py` сравнивает RTL движка с моделью `synthmodel.voice`
**побитово** на случайных параметрах, гейтах, ретриггерах и модуляции (2800 отсчётов);
`unit/test_softclip.py` — мягкий ограничитель.

## Этап 4: модуляция — LFO, вибрато, огибающая фильтра

Блок модуляции (`fpga/rtl/voice/mod_unit.sv`, побитово = `synthmodel.modunit`): 2 LFO (синус, треугольник,
пила вверх/вниз, меандр, случайный S&H), матрица из 8 маршрутов «источник × глубина × via → приёмник»
(высота, срез, громкость, ширина импульса). Маршрут 0 — вибрато: LFO1 × mod wheel → высота.
Параметры в тестах задаются через консоль UART прошивки (`set <param> <value>`).

Вибрато (`test_synth_core_mod.py`): mod wheel 0 → 127 на 0.3 с, частота основного тона по кадрам:
до — 440 Гц, после — ±50 центов с частотой 5.5 Гц.

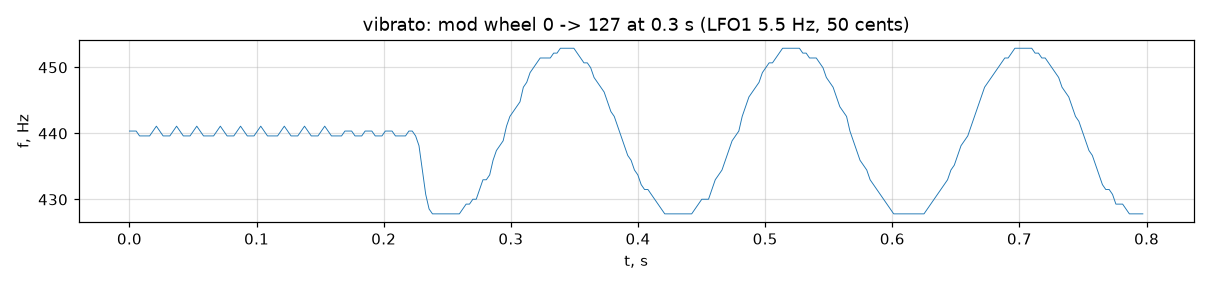
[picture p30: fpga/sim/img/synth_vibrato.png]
vibrato


Огибающая фильтра: срез 150 Гц + 4 октавы от ADSR2 (D2 = 400 мс, S2 = 0) — спектральный центроид
в начале ноты больше, чем в конце, более чем втрое.

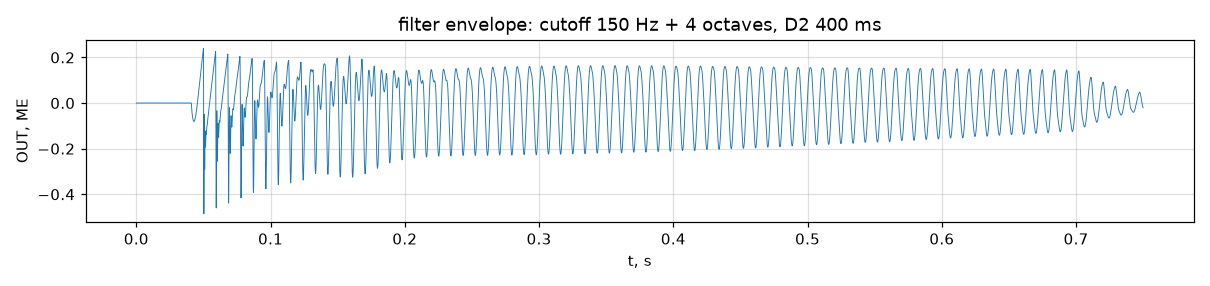
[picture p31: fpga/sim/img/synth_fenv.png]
filter envelope


## Этап 5: панель — ручки, энкодеры, дисплей

RTL: опрос MCP3208 (`panel/periph_pots.sv`, 8 каналов, сглаживание), декодер энкодеров с антидребезгом
(`panel/periph_enc.sv`), потоковый контроллер ST7789 с аппаратной заливкой и развёрткой 1-битных
глифов (`panel/lcd_ctrl.sv`). Прошивка: меню из таблицы параметров (энкодер МЕНЮ — страницы,
ПАР.1–3 — параметры страницы), 8 фиксированных ручек (подхватывают параметр при первом повороте),
строка статуса; вывод на экран не блокирует обработку MIDI (текстовая модель экрана, изменившиеся
ячейки отправляются, пока в FIFO контроллера есть место).

В тестбенче — модели MCP3208, энкодеров и дисплея ST7789 (кадровый буфер). Тест
`system/test_synth_core_panel.py` крутит энкодеры и ручку и сравнивает кадр дисплея **попиксельно**
с эталоном, отрисованным в Python тем же шрифтом. Кадр из симуляции (×3):

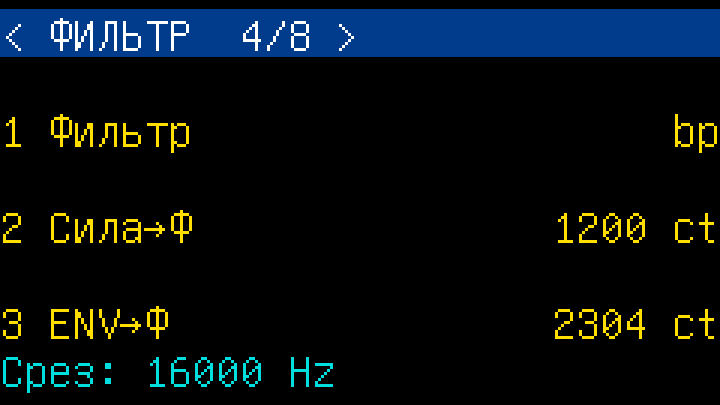
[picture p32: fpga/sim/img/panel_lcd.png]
дисплей в симуляции


`system/test_synth_core_latency.py`: задержка MIDI → звук при непрерывной перерисовке меню —
25 нот, максимум 0.7 мс (требование ТЗ — ≤ 3 мс).

## Этап 6: связь с АВК — входы, СИНХР, шина сигналов, слоты

RTL: `avk/adc_in.sv` (два AD7091R, 4·fs, калибровка, КИХ-дециматор), `avk/sync_in.sv` (фронты, период),
`avk/fx_bus.sv` (шина сигналов, слоты, микшеры ВЫХ/ВЫХ2), `avk/slot_math.sv` (слот MATH). Юнит-тесты
`unit/test_avk_bus.py`, `unit/test_avk_inputs.py` сравнивают RTL с `synthmodel/avk.py` бит-в-бит.

В тестбенче — модель пары AD7091R с идеальным входным каскадом (−12.5…+12.5 В → 0…4095) и источник
СИНХР: `--in1`, `--in2`, `--sync` принимают `dc:V`, `sine:F:A[:DC]`, `square:F:A[:DC]`, `saw:F:A[:DC]`
(в UART-сценарии — команды `in1`/`in2`/`sync` с тем же форматом).

`system/test_synth_core_avk.py`:
- кольцевой модулятор: ВХ1 (300 Гц, 5 В) × ВХ2 (1 кГц, 5 В) в слоте MATH → ВЫХ: 700 и 1300 Гц по 0.125 МЕ,
  исходные частоты подавлены; ВЫХ2 = ВХ1;

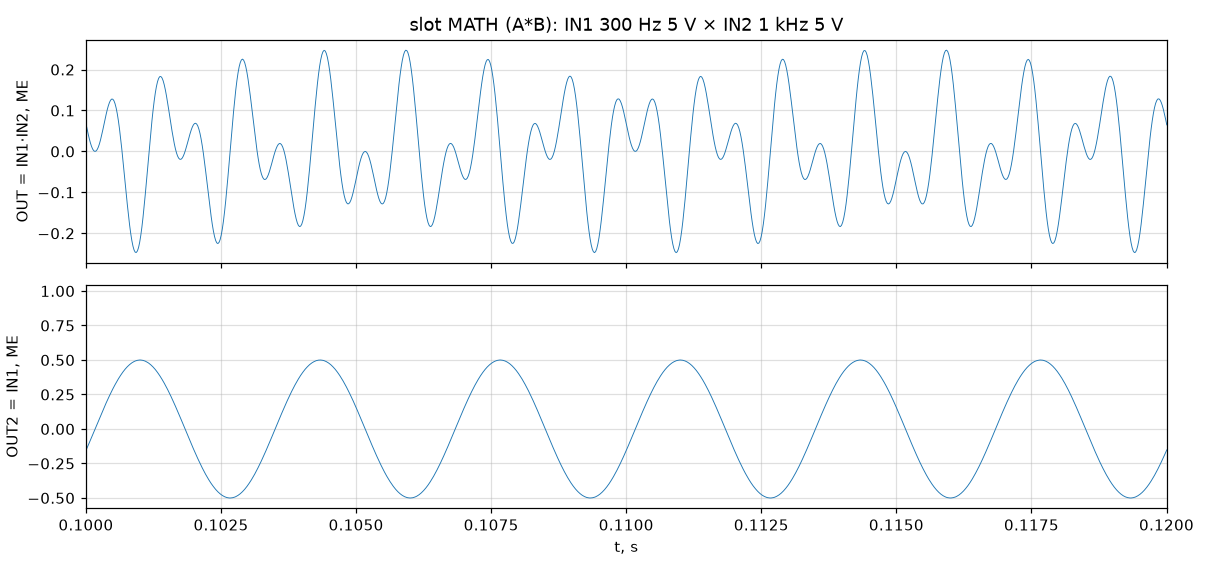
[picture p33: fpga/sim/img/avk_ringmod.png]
кольцевой модулятор
  
- ВХ1 = +5 В через матрицу модуляции → высота тона (1 МЕ = октава): ля 440 Гц звучит на пол-октавы выше;
  ВЫХ2 = GATE (1 МЕ, пока нажата клавиша);

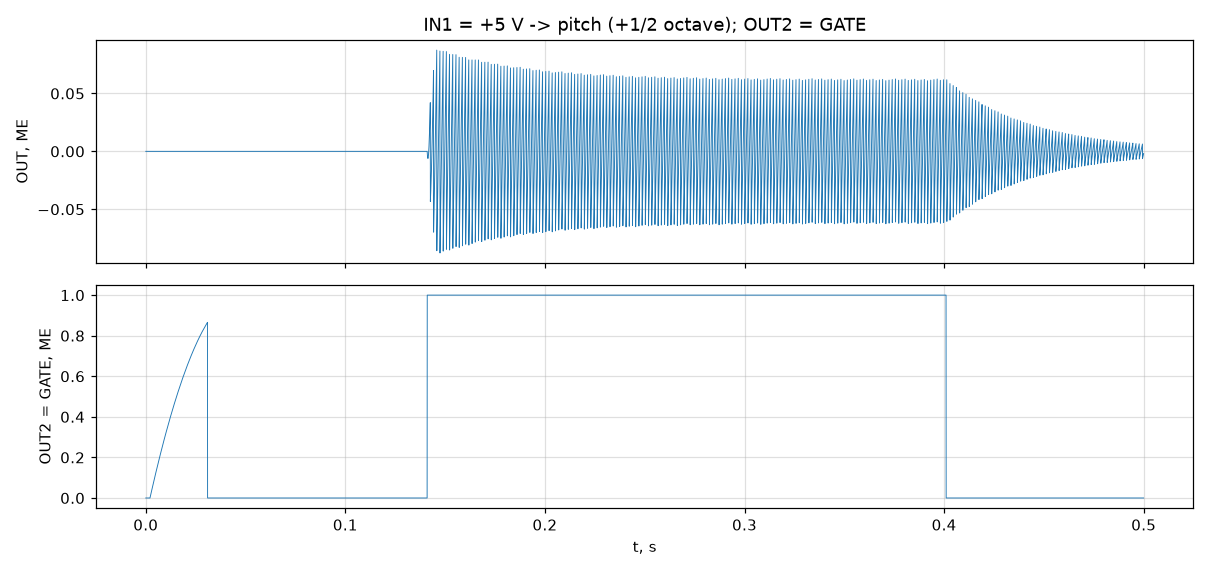
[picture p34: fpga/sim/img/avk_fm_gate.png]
ВХ1 → высота, ВЫХ2 = GATE
  
- СИНХР 100 Гц: консоль `avk` показывает частоту; в режиме «нота» каждый фронт перезапускает ноту 60.

## Этап 7: внешняя память, слот DELAY

RTL: `mem/mem_arb.sv`, `mem/mem_bram.sv`, `mem/sdram_ctrl.sv`, `avk/slot_delay.sv`. Юнит-тесты:
`unit/test_mem.py` — контроллер SDRAM против модели микросхемы, проверяющей временные параметры
команд, инициализацию и интервал регенерации, случайные чтения/записи с маской байтов; арбитр + BRAM
с двумя мастерами; `unit/test_avk_bus.py::test_fx_bus_delay` — слоты MATH + 2 × DELAY бит-в-бит с моделью
при случайной задержке памяти.

В тестбенче — модель внешней памяти на порту `xm_*` (`--xmem-words`, `--xmem-latency`: случайная
задержка 0…N тактов). `system/test_synth_core_delay.py`: эхо 50 мс с обратной связью 50 % (задержка
точно 2417 отсчётов, уровни 1, 1/2, 1/4, …), время задержки от периода СИНХР, запись и чтение памяти
процессором через окно `0x4000_0000` одновременно с работой слотов.

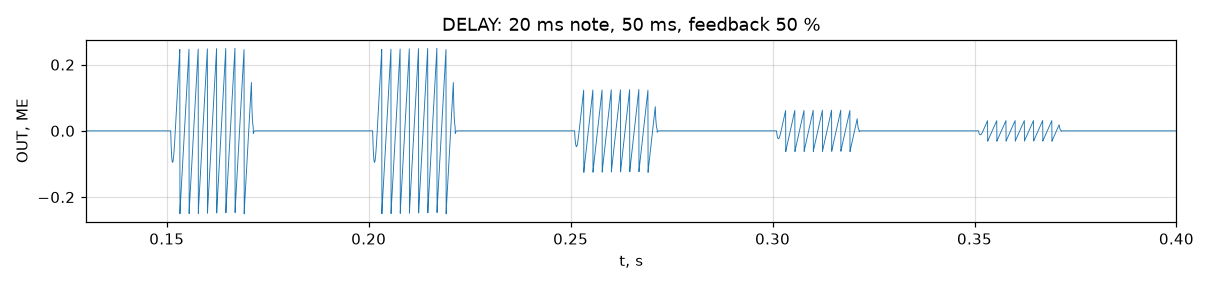
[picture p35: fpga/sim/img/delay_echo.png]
эхо


## Этап 8: хорус, реверберация, жёсткая синхронизация, детектор огибающей

RTL: `avk/slot_chorus.sv`, `avk/slot_reverb.sv`; `voice/voice_engine.sv` — регистр HSYNC и вход
`sync_edge`, регистр BLEP (PolyBLEP для пилы и меандра, 32 такта на голос); `voice/mod_unit.sv` —
детектор огибающей (источник 10). PolyBLEP проверяется бит-в-бит в `unit/test_voice_engine.py` и по
спектру в модели (`model/tests/test_voice.py`: наложение −14…−15 дБ). Юнит-тесты: слоты бит-в-бит
(`unit/test_avk_bus.py::test_fx_bus_chorus_reverb`), жёсткая синхронизация в `unit/test_voice_engine.py`,
детектор в `unit/test_mod_unit.py`.

`system/test_synth_core_fx.py`: хвост реверберации затухает (без неё — тишина после ноты); хорус
даёт биения уровня без смены высоты; генератор 440 Гц, синхронизированный СИНХР 100 Гц, повторяется
каждые 10 мс и имеет спектр гармоник 100 Гц; ВХ1 → детектор → высота тона; ВЫХ2 = +1 В для ноты до
второй октавы.

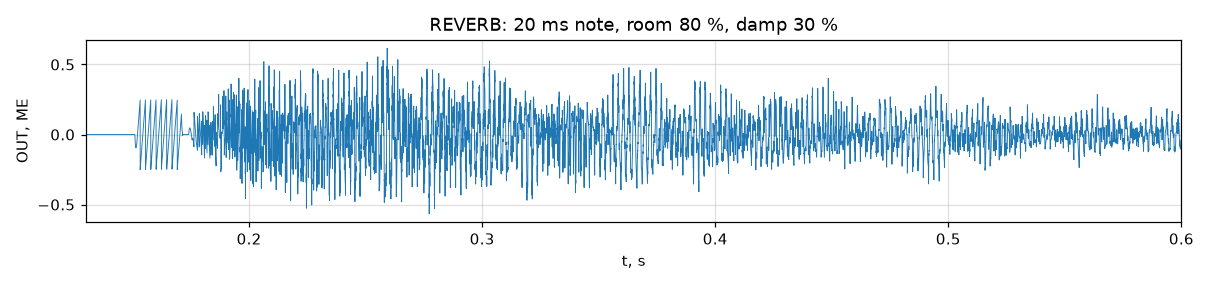
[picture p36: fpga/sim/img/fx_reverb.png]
реверберация


## Этап 9: SD-карта — пресеты, обновление прошивки

В тестбенче — SD-карта в режиме SPI (`models/sd_card_model.h`, общая с хост-тестами прошивки) на выводах
`sd_*`: `--sd-image` образ карты, `--sd-dump` образ после прогона, `--sd-sdsc` — карта со словной
адресацией. Образы FAT16 делает `sw/tools/fatimg.py`. `system/test_synth_core_storage.py`: запись и загрузка
пресетов из консоли и кнопками панели (записанный образ проверяется независимым чтением FAT), отсутствие
карты, `fwupdate` — FIRMWARE.BIN → флеш, затем загрузчик в ROM загружает эту прошивку с флеша.

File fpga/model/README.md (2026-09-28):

# Python-модели DSP-блоков

Пакет `synthmodel` — эталоны для RTL: WAV для прослушивания и сравнения с выходом симуляции.
Тесты — `make model` (pytest), эталонные WAV и графики — в `build/model/` (в CI — артефакт `model-refs`).

| Модуль | Что моделирует | Точность |
|---|---|---|
| `clocks` | делитель sys_clk → BCK/fs, инкременты фазы, таблица нот | побитово с RTL |
| `nco` | аккумулятор фазы + четвертьволновая таблица синуса, пила | побитово с `nco_sine.sv` |
| `adsr` | огибающая ADSR с экспоненциальными участками | float, эталон поведения |
| `svf` | SVF: TPT/ZDF (Simper/Zavalishin) и Chamberlin; ФНЧ/ПФ/ФВЧ, модулируемый срез | float |
| `analysis` | спектр, основной тон, THD, THD+N | — |
| `luts` | генерация `rtl/audio/sine_quarter_rom.sv` (`make luts`) | — |
| `wavio` | чтение/запись PCM WAV 16/24/32 бит | — |

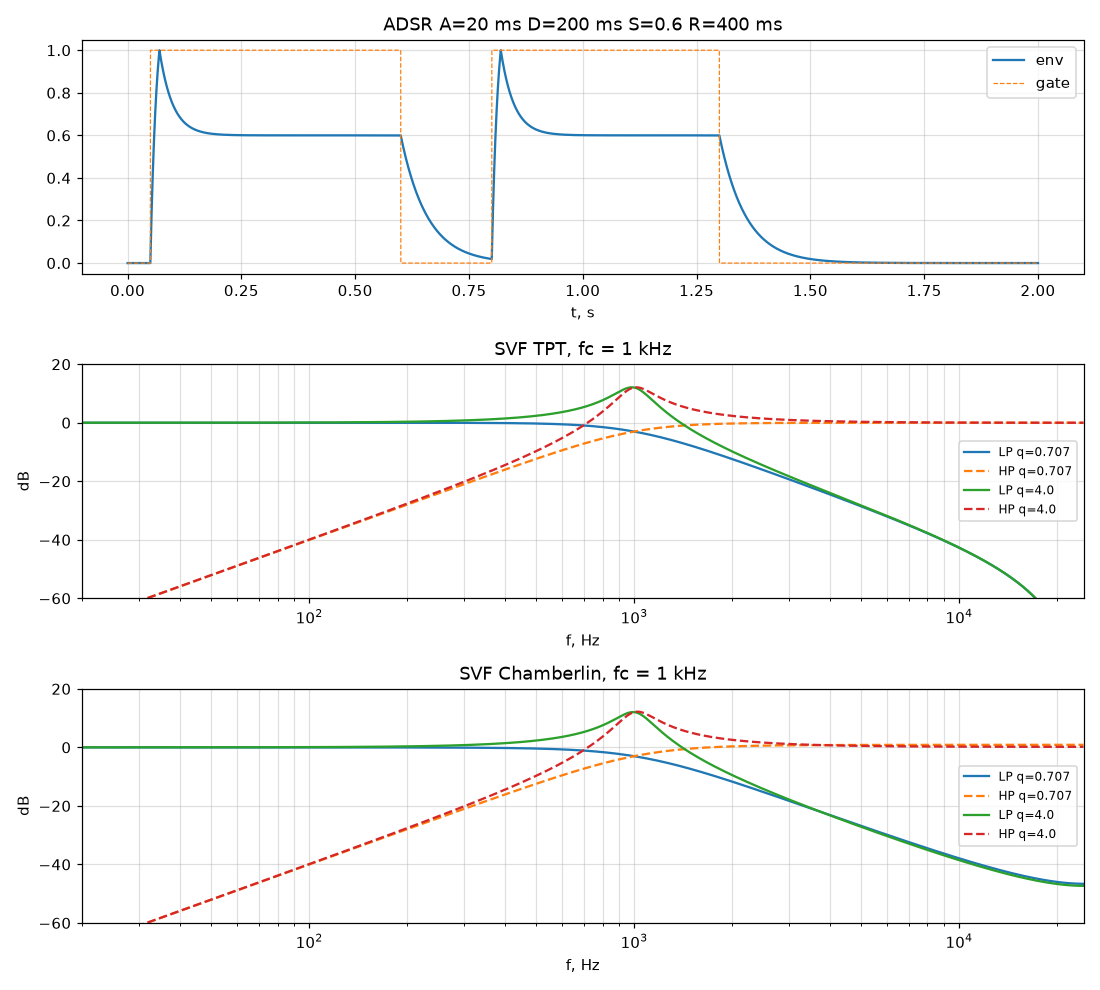
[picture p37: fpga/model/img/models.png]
Модели: ADSR и АЧХ фильтров


- **ADSR** (A = 20 мс, D = 200 мс, S = 0.6, R = 400 мс): атака — экспонента к цели 1.3, обрывается на 1.0
  ровно через A; D и R — время спада до −60 дБ от расстояния до цели. Второе нажатие во время
  затухания перезапускает атаку с текущего уровня, без щелчка.
- **SVF TPT**: точная АЧХ на частоте среза (усиление ФНЧ и ПФ на fc = q), устойчив до fs/2.
- **SVF Chamberlin**: дешевле в фиксированной точке, но АЧХ искажается при приближении к fs/2
  (плато ФНЧ около −47 дБ, подъём ФВЧ) и фильтр неустойчив выше ≈ fs/6. Выбор для RTL — на этапе 4.

График в репозитории обновляется командой `make plots`.

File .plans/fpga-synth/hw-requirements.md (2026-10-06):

# Требования к схеме и плате: FPGA-синтезатор АВК-6

Статус: **черновик v0.3**. Сопутствующие документы: [`trs.md`](trs.md) (ТЗ), [`block-diagram.svg`](block-diagram.svg) (структурная схема), [`panel-sketch.svg`](panel-sketch.svg) (панель), [`hw/schematic.md`](../../hw/schematic.md) (принципиальная схема по узлам: позиционные обозначения, номиналы, подключение по выводам).
Схема и плата делаются в **KiCad**. Документ задаёт требования (`Т-xx`) и рекомендуемую реализацию с расчётом номиналов. Рекомендованные компоненты можно заменить, если требования выполняются.

Открытые вопросы — в разделе 16 (`HO-xx`).

---

## 0. Общая структура

Подробная структурная схема с доменами питания — [`block-diagram.svg`](block-diagram.svg) (PNG рядом). Ниже — упрощённо.

```
                      Нижний разъём модуля (+5, ±15, ⊥, СИНХР)
                                   │
   ┌───────────────────────────────┼─────────────────────────────────────────────┐
   │  Питание: +5 → Tang Nano (через Шоттки), LDO 3.3A (аналог), LDO 3.3D (цифра) │
   │           ±15 → ОУ, компараторы; REF 2.5 В (опора АЦП и смещения)           │
   └──────────────────────────────────────────────────────────────────────────────┘
 ВХ1 ─ делитель+смещение ─ ФНЧ ─ буфер RRIO ─ АЦП1 ─┐
 ВХ2 ─ делитель+смещение ─ ФНЧ ─ буфер RRIO ─ АЦП2 ─┤ SPI
 8 потенциометров ─ RC ─ MCP3208 ───────────────────┤ SPI
 MIDI TRS ─ мост ─ оптрон ──────────────────────────┤             ┌───────────────┐
 СИНХР ─ R + ограничитель ─ триггер Шмитта ─────────┼─────────────┤ Tang Nano 20K │
 4 энкодера ─ подтяжки + RC ────────────────────────┤             │  (на гребёнках)│
 Дисплей ST7789 (SPI) + подсветка (MOSFET) ─────────┘             └──────┬────────┘
                                                                         │ I2S + XSMT
                                   PCM5102A ─ L ─ ГРОМКОСТЬ ─┬─ ОУ ×4.24 ─ ВЫХ ─┬─ LM339 ─ LED +10/−10
                                             │               └─ ×0.5 ─ 1 мкФ ─ TPA6132A2 ─ НАУШН./ЛИН. (TRS)
                                             └ R ──────────────── ОУ ×4.24 ─ ВЫХ2
```

## 1. Сигнальные уровни и шкалы (общие для всех узлов)

| # | Требование |
|---|---|
| Т-1.1 | Машинная единица АВК: ±10 В. |
| Т-1.2 | Полная шкала (FS) аналоговых входов и выходов: **±12.5 В**; ±10 В = 0.8 FS. Запас 25 % нужен, чтобы видеть перегрузки АВК и не резать сигнал на ровно ±10 В. |
| Т-1.3 | Входы и выходы связаны по постоянному току (без разделительных конденсаторов). |
| Т-1.4 | Логика ПЛИС — LVCMOS 3.3 В. Ни один сигнал к ПЛИС не превышает 3.3 В ни при каком состоянии питания. |

## 2. Питание

| # | Требование |
|---|---|
| Т-2.1 | Источники — только от нижнего разъёма модуля: +5 В, +15 В, −15 В, ⊥. Единая земля АВК. |
| Т-2.2 | Tang Nano питается через свой вывод 5 В на гребёнке, через диод Шоттки (≥1 А, Vf ≤ 0.4 В, напр. SS14 / B130). Диод исключает обратное питание АВК от USB при прошивке на проставке. |
| Т-2.3 | Отдельный LDO **3.3A** (аналог): PCM5102A AVDD/CPVDD, АЦП входов, буферы входов, MCP3208 и питание потенциометров. Шумы ≤ 10 мкВ rms (LP5907-3.3, TPS7A2033 или аналог), ток ≥ 150 мА. |
| Т-2.4 | Отдельный LDO **3.3D** (цифра): DVDD PCM5102A, логика VDRIVE АЦП, дисплей, подтяжки энкодеров, оптрон, триггер Шмитта. Ток ≥ 300 мА (AP2112K-3.3, AMS1117-3.3). |
| Т-2.5 | Потребители 3.3D не должны питать ПЛИС через выводы I/O, когда ПЛИС обесточена. Т.к. всё питается от одного +5 В, достаточно одновременного включения; последовательные резисторы 33–100 Ом в линиях, идущих в ПЛИС. |
| Т-2.6 | Опорное напряжение **REF 2.5 В**, ≤ 20 ppm/°C, ≤ 0.1 % (REF3025, ADR361, LM4040C25 с буфером). Используется как REFIN обоих АЦП входов и как источник смещения входных каскадов (ратиометрическая схема). |
| Т-2.7 | ±15 В — на ОУ входов/выходов и компараторы. Фильтр на входе каждой шины: ферритовая бусина + 10 мкФ + 100 нФ. |
| Т-2.8 | Развязка: 100 нФ у каждого вывода питания каждой микросхемы; 10 мкФ на каждую шину у группы. Электролит 47–100 мкФ на +5, +15, −15 на входе платы (у АВК слабые фильтры — см. статью, помехи >1 В). |
| Т-2.9 | Защита от переполюсовки не требуется (разъём с ключом), но на ±15 В — диоды Шоттки от шины к земле в обратном направлении (защита ОУ при несимметричном включении). |
| Т-2.10 | Бюджет тока (оценка): +5 В ≤ 500 мА (Tang Nano 20K ~200 мА, подсветка ~30 мА, LDO 3.3A/3.3D ~80 мА, наушники 3.3H до ~100 мА); +15 / −15 В ≤ 30 мА каждая. |
| Т-2.11 | Контрольные точки на каждой шине: +5, +15, −15, 3.3A, 3.3D, REF2.5, ⊥ (несколько). |

## 3. Tang Nano 20K и распиновка

| # | Требование |
|---|---|
| Т-3.1 | Tang Nano 20K устанавливается на несущую плату на ответных гребёнках (съёмная). Плата разводится под **20K**; 9K используется только на макете. |
| Т-3.2 | USB-C Tang Nano обращён к боковому краю платы, свободен от препятствий (доступ при установке на ремонтную проставку). |
| Т-3.3 | Слот SD-карты Tang Nano доступен без снятия панели (хотя бы при вынутом модуле). |
| Т-3.4 | Таблица пинов — по фактической распиновке 20K (HO-01). Нужно ≈ 37 GPIO (сигналы — как порты `fpga/boards/tang_nano_20k/top_synth.sv`): |
| Т-3.5 | Внешняя SPI NOR флеш (W25Q64JV) на несущей плате — прошивка CPU и калибровки: встроенная флеш 20K занята битстримом и недоступна логике (`fpga/README.md`). +4 GPIO (`flash_*`), учтены в таблице ниже. |

| Группа | Сигналы | Кол-во |
|---|---|---|
| I2S ЦАП | BCK, LRCK, DIN, XSMT (XSMT через RC также включает усилитель наушников) | 4 |
| АЦП входов | CONVST, CS, SCLK (общие для двух AD7091R), SDO1, SDO2 | 5 |
| MCP3208 | SCK, CS, MOSI, MISO | 4 |
| Дисплей | SCK, MOSI, CS, DC, RST, BL | 6 |
| MIDI RX | RX | 1 |
| СИНХР | SYNC | 1 |
| Энкодеры | 4 × (A, B, SW) | 12 |
| SPI-флеш (Т-3.5) | flash_sck, flash_mosi, flash_miso, flash_cs_n | 4 |
| **Итого** | | **37** |
| SD-карта | SCK, MOSI, MISO, CS — выводы встроенного слота 20K, гребёнку не занимают (проверить при HO-01) | (4) |

Если пинов не хватит — сначала объединить SCK/MOSI MCP3208 и дисплея (разные CS), затем кнопки энкодеров через сдвиговый регистр 74HC165.

## 4. MIDI-вход (TRS 3.5 мм)

| # | Требование |
|---|---|
| Т-4.1 | Соответствие MIDI 1.0 (токовая петля 5 мА, 31.25 кбод) и MMA RP-054 **TRS Type A**: Tip = MIDI pin 5 (sink), Ring = pin 4 (source), Sleeve = pin 2 (экран, не соединять с землёй на приёмнике). Сверить с RP-054 при разводке. |
| Т-4.2 | Работа с кабелями **Type A и Type B** без переделки: диодный мост из Шоттки (2× BAT54S) перед светодиодом оптрона. |
| Т-4.3 | Гальваническая развязка: оптрон с выходом ≤ 2 мкс по фронтам, питание 3.3 В: **H11L1** (с триггером Шмитта) или 6N137 / TLP2361 (3.3 В версия). Порог срабатывания светодиода ≤ 2 мА. |
| Т-4.4 | Последовательный резистор 220 Ом (для моста — 180 Ом с учётом падения на Шоттки), защитный диод 1N4148 встречно светодиоду (при мосте не нужен). |
| Т-4.5 | Выход оптрона — открытый коллектор, подтяжка 1–2.2 кОм к 3.3D, в ПЛИС. |
| Т-4.6 | Гнездо — 3.5 мм стерео, крепление на панель гайкой (PJ-392 / Lumberg 1503) или на плату с выходом втулки через отверстие панели. |

## 5. Вход СИНХР (с нижнего разъёма)

| # | Требование |
|---|---|
| Т-5.1 | Уровень сигнала предположительно ТТЛ 0/+5 В (HO-02). Вход должен корректно работать с: ТТЛ; ±5 В; ±10 В; выдерживать ±15 В неограниченно долго. |
| Т-5.2 | Входное сопротивление ≥ 20 кОм. |
| Т-5.3 | Порог — триггер Шмитта 74LVC1G17 при 3.3 В (VT+ ≈ 1.5…2.0 В, VT− ≈ 0.9…1.4 В; гистерезис ≥ 0.4 В), ТТЛ «1» ≥ 2.4 В проходит с запасом при подтяжке узла к GND 470 кОм; частота до 1.1 кГц (с запасом — до 20 кГц); фронт на выходе ≤ 100 нс. |
| Т-5.4 | Реализация: 22 кОм последовательно → Шоттки-ограничитель BAT54S на 3.3D/⊥ → 100 пФ на ⊥ → **74LVC1G17** (триггер Шмитта, 3.3 В) → ПЛИС. Ток через ограничитель при 15 В ≈ 0.5 мА — шина 3.3D должна его поглощать (нагрузка на шине заведомо больше). |
| Т-5.5 | Контрольная точка до и после триггера. |

## 6. Аналоговые входы ВХ1, ВХ2

| # | Требование |
|---|---|
| Т-6.1 | Диапазон ±12.5 В → 0…2.5 В на входе АЦП (Vadc = 1.25 + 0.1·Vin). Неинвертирующая схема (знак сохраняется). |
| Т-6.2 | Входное сопротивление ≥ 100 кОм. Выдерживает ±15 В неограниченно долго без повреждения и без выхода напряжения на АЦП за 0…VDD. |
| Т-6.3 | ФНЧ-антиалиасинг **2-го порядка**, Баттерворт, fc = 20 кГц ±10 %; ослабление на 172 кГц (fs_ADC − 20 кГц при fs_ADC = 192 кГц) ≥ 35 дБ. |
| Т-6.4 | Погрешность до калибровки: смещение ≤ 50 мВ (приведено ко входу), усиление ≤ 1 %. После программной калибровки: ≤ 10 мВ и ≤ 0.2 %. Дрейф ≤ 1 мВ/°C. |
| Т-6.5 | Шум, приведённый ко входу, ≤ 1 мВ rms в полосе 20 кГц (≈ 12-битный АЦП не должен упираться в шум каскада). |
| Т-6.6 | Идентичность каналов (для операций A·B, A/B): задержка между каналами ≤ 1 мкс (одинаковые фильтры, одновременная выборка АЦП). |

**Рекомендуемая реализация (на каждый канал):**

1. Пассивный сумматор на неинвертирующем входе: `Vin —Ra— узел —Rb— REF2.5`, `узел —Rc— ⊥`.
   Условия: вес Vin = 0.1, вес REF = 0.5 → `1/Ra : 1/Rb : 1/Rc = 0.1 : 0.5 : 0.4`.
   **Ra = 100 кОм, Rb = 20.0 кОм, Rc = 24.9 кОм** (0.1 %). Rвх ≈ Ra + Rb‖Rc ≈ 111 кОм; Rвых узла = 10 кОм.
2. Ограничитель в узле: BAT54S на 3.3A и ⊥. При Vin = ±15 В узел = −0.25…+2.75 В — ограничитель срабатывает только на −15 В, ток ≤ 0.15 мА.
3. ФНЧ Саллена–Ки 2-го порядка на ОУ с однополярным питанием 3.3A, **RRIO**, малошумящий, Vos ≤ 1 мВ: OPA2350, OPA2365, MCP6022, TLV9062 (одна сдвоенная микросхема на оба канала). Выходное сопротивление узла (10 кОм) входит в первый резистор фильтра. Выход ОУ сам ограничен рельсами 0…3.3 В.
4. На входе АЦП: 33–49.9 Ом последовательно + 1–2.2 нФ C0G на ⊥ (по рекомендации даташита АЦП к «заряду» входа).

## 7. АЦП входов

| # | Требование |
|---|---|
| Т-7.1 | 2 независимых канала, **одновременная выборка** (общий CONVST/CS). |
| Т-7.2 | Разрешение ≥ 12 бит, скорость ≥ 200 кSPS на канал (работаем на 192 кSPS → децимация 4:1 в ПЛИС). |
| Т-7.3 | Внешний опорный вход 2.5 В (общий REF, Т-2.6) — ратиометрично со смещением входного каскада. |
| Т-7.4 | Отдельное питание логики (VDRIVE/VIO) 3.3 В, SPI ≥ 16 МГц. |
| Т-7.5 | Рекомендуется **AD7091R** (12 бит, 1 MSPS, REFIN/REFOUT, VDRIVE) ×2. Альтернатива: ADS7042 (опора = AVDD → питать от REF3025 не рекомендуется), AD7988-5 (16 бит, если захочется больше). |

## 8. ЦАП

| # | Требование |
|---|---|
| Т-8.1 | **PCM5102A**, режим I2S (FMT = 0), внутренний PLL от BCK (SCK на ⊥), BCK = 64·fs. |
| Т-8.2 | Фильтр: FLT = 1 (low latency) — минимальная задержка важна при обработке сигналов АВК. DEMP = 0. |
| Т-8.3 | XSMT управляется ПЛИС (подтяжка 10 кОм к ⊥ → при старте ЦАП молчит, пока ПЛИС не разрешит). |
| Т-8.4 | Питание: AVDD и CPVDD — 3.3A; DVDD — 3.3D; LDOO и конденсаторы накачки — строго по даташиту (2.2 мкФ, 1 мкФ X7R). |
| Т-8.5 | Проверить на макете (HO-03): тракт пропускает постоянную составляющую; смещение на выходе ≤ 5 мВ; поведение при автоматическом mute на нулевых данных. |
| Т-8.6 | Выход ЦАП: ±2.97 В пик (2.1 В rms) = FS. Нагрузка ЦАП ≥ 1 кОм. |

## 9. Выходы ВЫХ, ВЫХ2

| # | Требование |
|---|---|
| Т-9.1 | Полная шкала ЦАП → ±12.5 В: усиление **×4.21**. ±10 В при 0.8 FS. |
| Т-9.2 | ВЫХ: ЦАП L → потенциометр ГРОМКОСТЬ (делитель) → неинвертирующий усилитель. В крайнем положении ГРОМКОСТЬ передача точно ×1 (движок = верхний вывод). |
| Т-9.3 | ВЫХ2: ЦАП R → неинвертирующий усилитель ×4.21, без регулятора. |
| Т-9.4 | Нагрузка ≥ 2 кОм при ±12.5 В; устойчивость на ёмкость кабеля до 1 нФ; устойчивость к КЗ на ⊥ неограниченно долго. |
| Т-9.5 | Выходное сопротивление ≤ 1 Ом на НЧ (резистор защиты внутри петли ОС). |
| Т-9.6 | Сглаживающий ФНЧ: 1-й порядок, fc ≈ 40–50 кГц (конденсатор параллельно Rf). |
| Т-9.7 | Смещение нуля ≤ 20 мВ до калибровки, шум ≤ 200 мкВ rms (20 кГц). |
| Т-9.8 | При подаче/снятии питания на выходе нет выбросов более ±12.5 В; ЦАП заглушен XSMT до готовности ПЛИС. |

**Рекомендуемая реализация:**

- ОУ: **OPA2171** (A — ВЫХ, B — ВЫХ2; ±18 В, rail-to-rail выход, малый входной ток — нужен из-за высокого сопротивления движка потенциометра). OPA2277 / TL072 хуже (выход только до ±12.5 В с малым запасом).
- Усиление: Rf = 32.4 кОм, Rg = 10.0 кОм (0.1 %) → ×4.24; точная подстройка программно. Cf = 100 пФ → fc ≈ 49 кГц.
- Защита: 100 Ом последовательно в выходе, ОС снимается после резистора; 47 пФ с выхода ОУ на инвертирующий вход для устойчивости.
- ГРОМКОСТЬ: 10 кОм, логарифмический (A) или линейный с «логарифмирующим» резистором (HO-04), 16 мм / 9 мм с крупной ручкой. Верх — ЦАП L, низ — ⊥, движок — неинвертирующий вход ОУ через 1 кОм.

## 9a. Выход на наушники / линейный НАУШН./ЛИН. (TRS 3.5 мм)

| # | Требование |
|---|---|
| Т-9a.1 | Назначение — готовый звук без перемычек к АВК: наушники напрямую, либо линейный вход звуковой карты / усилителя. |
| Т-9a.2 | Источник — движок ГРОМКОСТИ (тот же сигнал, что идёт на ВЫХ): громкость регулирует оба выхода. |
| Т-9a.3 | Нагрузка — наушники **16–600 Ом** или линейный вход ≥ 10 кОм. Мощность ≥ 25 мВт на 16 Ом / ≥ 30 мВт на 32 Ом на канал; напряжение ≥ 1 В rms на нагрузке ≥ 300 Ом (достаточно для 250-омных студийных наушников, ~100 дБ SPL). |
| Т-9a.4 | Развязка по постоянному току: постоянная составляющая сигналов АВК не попадает в наушники и на линейный вход. Нижняя граница ≤ 5 Гц. Постоянное смещение на выходе ≤ 5 мВ. |
| Т-9a.5 | Моно-сигнал на Tip и Ring **от двух отдельных каналов усилителя** (каждый наушник — свой канал; иначе нагрузка 16‖16 = 8 Ом). Sleeve — ⊥. |
| Т-9a.6 | Устойчивость к КЗ любого выхода на ⊥ неограниченно долго (моно-штекер TS замыкает Ring) — встроенное токоограничение и тепловая защита. |
| Т-9a.7 | Без щелчков > 10 мВ при включении/выключении (управление SD/MUTE усилителя от ПЛИС или RC-задержка). |
| Т-9a.8 | Шум на выходе ≤ 10 мкВ rms (A-взвешенный) — в наушниках слышно всё. |
| Т-9a.9 | Питание — отдельная шина **3.3H** (LDO 300 мА от +5 В), чтобы токи наушников не модулировали 3.3A (опора АЦП/ЦАП). |

**Рекомендуемая реализация:** **TPA6132A2** (стерео усилитель наушников DirectPath: выход симметричен относительно земли без выходных конденсаторов, встроенный генератор отрицательного питания, защита от КЗ и перегрева, 25 мВт на 16 Ом от 3.3 В, коэффициент усиления выбирается выводами G0/G1).
- Вход: движок ГРОМКОСТИ → делитель 10 кОм / 10 кОм (×0.5: 2.1 В rms полной шкалы ЦАП → ≈ 1 В rms) → по 1 мкФ (плёнка / X7R) на входы INL и INR (оба канала — один и тот же сигнал). С входным сопротивлением TPA6132A2 нижняя граница — единицы Гц (уточнить по даташиту).
- Усиление 0 дБ (G0/G1 по даташиту); при необходимости громче — +6 дБ.
- Выход: OUTL → Tip, OUTR → Ring напрямую (Т-9a.5); защита от электростатики — TVS на 3.3 В или по даташиту.
- EN (включение) — от той же цепи XSMT, что глушит ЦАП, через RC 10 кОм / 1 мкФ: усилитель включается на ~10 мс позже ЦАП, когда питание и такты уже стабильны (Т-9a.7). Отдельный пин ПЛИС не нужен (проверить по даташиту пороги EN и полярность).
- Альтернатива под ручную пайку (TPA6132A2 — QFN-16 3×3 мм): NJM4556A (SOIC-8, ±70 мА) от ±15 В через 78L09/79L09 (±9 В), по каналу на Tip/Ring, 10 Ом последовательно в выходе, входная развязка 1 мкФ / 100 кОм. Длительное КЗ греет ОУ — защита хуже, чем у TPA6132A2.

Гнездо — 3.5 мм стерео на панель (как у MIDI). Разнести с MIDI (MIDI слева у входов, НАУШН./ЛИН. справа у выходов) и подписать: перепутанное подключение не опасно, но молчит.

## 10. Индикация перегрузки ВЫХ (+10 / −10)

| # | Требование |
|---|---|
| Т-10.1 | Индицирует напряжение **на штыре ВЫХ** (после ГРОМКОСТИ): «+10» при V > +10 В, «−10» при V < −10 В. Порог ±10 В ±0.3 В. |
| Т-10.2 | Растяжка импульса: светодиод горит ≥ 50 мс после короткого превышения (видно одиночные пики). |
| Т-10.3 | Не нагружает выход (Rвх ≥ 100 кОм). |
| Т-10.4 | Реализация: **LM339** от ±15 В: 2 компаратора — детекторы, 2 — растяжители (диод + RC 100 кОм / 1 мкФ). Пороги — делители от ±15 В или от REF2.5 через масштабирование. Светодиоды: анод через резистор к ⊥, катод к выходу компаратора (открытый коллектор тянет к −15 В); 6.8 кОм → ≈ 1.9 мА (светодиоды повышенной яркости, 3 мм, красные). Можно взять схему индикации из модуля умножителя AD633. |

## 11. Потенциометры и MCP3208

| # | Требование |
|---|---|
| Т-11.1 | 8 потенциометров 10 кОм линейных (B10K), 9 мм, вертикальные, на плату, металлический вал с резьбовой втулкой для крепления к панели. |
| Т-11.2 | Питание потенциометров — от опоры MCP3208 (ратиометрично). VREF MCP3208 = 3.3A (или REF2.5 — тогда потенциометры тоже от REF2.5). |
| Т-11.3 | На каждом движке RC: 1 кОм + 100 нФ (фильтр и «резервуар» для выборки MCP3208). |
| Т-11.4 | MCP3208: питание 3.3A, SPI ≤ 1 МГц (при 2.7–3.3 В), опрос ≥ 100 Гц на канал. |

## 12. Энкодеры

| # | Требование |
|---|---|
| Т-12.1 | 4 × EC11 с кнопкой, вал 20 мм (под высоту панели, HO-05), 20–30 щелчков/оборот. |
| Т-12.2 | A, B, SW: подтяжка 10 кОм к 3.3D + RC 10 кОм/10 нФ (τ = 100 мкс), общий вывод на ⊥. Окончательная фильтрация дребезга — в ПЛИС. |

## 13. Дисплей

| # | Требование |
|---|---|
| Т-13.1 | 1.14" IPS, ST7789, 240×135, SPI, питание 3.3D (модуль типа Sipeed или «8-pin»: GND, VCC, SCL, SDA, RES, DC, CS, BLK). |
| Т-13.2 | Подсветка — ШИМ от ПЛИС: если вход BLK модуля логический (у большинства модулей ST7789 1.14″) — напрямую через 100 Ом; если BLK — анод подсветки — через N-MOSFET AO3400 (посадочное место предусмотреть). |
| Т-13.3 | Крепление за окном панели (окно ≈ 26×16 мм под активную область); высота модуля согласуется со стойками (HO-05). Подключение — шлейф/гребёнка к несущей плате. |

## 14. Нижний разъём модуля и панельные штыри

| # | Требование |
|---|---|
| Т-14.1 | Нижний разъём повторяет разъём штатных модулей АВК-6: +5, +15, −15, ⊥, СИНХР. Распиновка — HO-06 (снять со штатного модуля). |
| Т-14.2 | Штыри 2РМТ на панели (ВХ1, ВХ2, ВЫХ, ВЫХ2) соединяются с платой проводом или контактными площадками под пайку; координаты — по сетке АВК (см. `trs.md` 3.2). Земля на панель не выводится. |

## 15. Плата

| # | Требование |
|---|---|
| Т-15.1 | Габарит — не больше 120×90 мм минус зоны направляющих АВК; крепёжные отверстия под стойки в тех же координатах, что и на панели (4 мм от углов). |
| Т-15.2 | **4 слоя** (сигнал / сплошная ⊥ / питание / сигнал) — рекомендуется. При 2 слоях — сплошной полигон ⊥ снизу, без разрезов под аналоговой частью. |
| Т-15.3 | Зонирование: аналоговые узлы (входы, АЦП, ЦАП, выходные ОУ, REF) — в одной зоне, дальше от Tang Nano и SDRAM; цифровые линии не проходят под аналоговыми узлами. |
| Т-15.4 | Все элементы панели (потенциометры, энкодеры, гнездо MIDI, светодиоды, дисплей) стоят на несущей плате и выходят в отверстия панели; высота стоек подбирается под длину валов (HO-05). |
| Т-15.5 | Отладочные точки: I2S (BCK, LRCK, DIN), MIDI после оптрона, СИНХР после триггера, SPI АЦП, аналоговые узлы ВХ1/ВХ2 на входе АЦП, выходы ЦАП L/R. |
| Т-15.6 | Шелкография: подписи всех разъёмов, полярность, версия платы. |
| Т-15.7 | Компоненты — по возможности SMD 0603/0805, SOIC/SOT-23 (ручная пайка), кроме панельных. |

## 16. Открытые вопросы (железо)

| # | Вопрос |
|---|---|
| HO-01 | Фактическая распиновка Tang Nano 20K: сколько свободных GPIO, какие банки 3.3 В, какие пины заняты SD/светодиодами/HDMI. |
| HO-02 | Уровень СИНХР (ТТЛ?) — снять осциллографом. |
| HO-03 | PCM5102A и DC: проверить на макете (этап 1 плана). |
| HO-04 | ГРОМКОСТЬ — логарифмическая или линейная характеристика. |
| HO-05 | Высота конструкции: стойки, длина валов, высота дисплея, место под Tang Nano с USB-C. |
| HO-06 | Распиновка нижнего разъёма штатных модулей АВК-6. |
| HO-07 | Встроенная SDRAM Tang Nano 20K: фаза тактового сигнала `O_sdram_clk` относительно `clk` и задержка чтения (`sdram_ctrl`: `CL`, `RD_EXTRA`) — проверить тестом памяти (`mem` в консоли) на плате. |
| HO-08 | ~~Выход на наушники~~ | **Решено:** нужен; TPA6132A2 от 3.3H, раздел 9a |
| HO-09 | AD7091R с внешней опорой 2.5 В: как отключается внутренняя опора, номиналы на REFIN/REFOUT. Запасной вариант — опора с REFOUT одного АЦП через повторитель (`hw/schematic.md`, лист `adc`). |

## 17. Предварительный перечень ключевых компонентов

| Узел | Компонент | Кол-во |
|---|---|---|
| ЦАП | PCM5102A (TSSOP-20) | 1 |
| АЦП входов | AD7091R | 2 |
| АЦП потенциометров | MCP3208 | 1 |
| Опора | REF3025 / ADR361 | 1 |
| SPI NOR флеш (прошивка, калибровки) | W25Q64JV | 1 |
| ОУ входов (3.3 В, RRIO) | OPA2350 / TLV9062 | 1 (+1 если Саллен-Ки на отдельных ОУ) |
| ОУ выходов (±15 В) | OPA2171 | 1 |
| Усилитель наушников | TPA6132A2 (альт. NJM4556A) | 1 |
| Компараторы LED | LM339 | 1 |
| Оптрон MIDI | H11L1 | 1 |
| Триггер СИНХР | 74LVC1G17 | 1 |
| LDO 3.3A / 3.3D / 3.3H | LP5907-3.3 / AP2112K-3.3 / AP2112K-3.3 | 1 / 1 / 1 |
| Шоттки | SS14, BAT54S | 1 / 5 |
| Потенциометры | B10K 9 мм ×8, ГРОМКОСТЬ 10 кОм ×1 | 9 |
| Энкодеры | EC11 с кнопкой | 4 |
| Дисплей | 1.14" ST7789 240×135 | 1 |
| Гнёзда MIDI, НАУШН./ЛИН. | 3.5 мм TRS, на панель | 2 |
| Светодиоды | 3 мм красные | 2 |

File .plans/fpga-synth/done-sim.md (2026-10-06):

# Журнал этапов 0–9: сделано в симуляции

Что сделано, как проверено и какие решения приняты на этапах 0–9 (RTL, прошивка, модели, тесты, CI).
Всё здесь закрыто **в симуляции** (Verilator, бит-в-бит с моделями `fpga/model/synthmodel`, хост-тесты прошивки,
CI на каждый коммит); на железе не проверено ничего — это работа частей А и Б [плана](plan.md).

Пункты «Осталось на железе» ниже собраны в план: распиновка — А1, звук и цифра — А2, панель и MIDI — А3,
аналоговые узлы — А4, сравнение с симуляцией — А5.

Структура репозитория — в `AGENTS.md`.

### Этап 0. Инфраструктура
1. **CI в GitHub Actions — первым делом**, до первой строчки RTL:
   - линт RTL (`verilator --lint-only -Wall`);
   - симуляция в Verilator: тестбенч подаёт на вход поток MIDI-байтов (и сигналы ВХ1/ВХ2 из файлов), снимает выход I2S → WAV;
   - анализ на Python: спектр (частота основного тона против таблицы нот, гармоники, шум), осциллограммы, огибающие; проверки с допусками → pass/fail;
   - графики (PNG) и WAV — артефакты сборки, их можно скачать и послушать;
   - сборка C-прошивки RISC-V (`riscv-none-elf-gcc` / `riscv64-unknown-elf-gcc`).
2. Каркас `fpga/`, `sw/`, `hw/`, скрипты сборки (`make lint`, `make sim`, `make fw`).
3. Проекты Gowin EDA для 9K и 20K (`fpga/boards/`), обёртки примитивов (PLL, BSRAM). Битстрим собирается локально.
4. Python-модели: NCO, ADSR, SVF → эталонные WAV для сравнения с RTL.
- **Готово, когда:** CI зелёный на заглушечном модуле (генератор синуса → I2S → WAV → проверка частоты), «мигалка» из Gowin EDA работает на 9K.
- **Статус:** сделано всё, кроме проверки на железе: CI (`.github/workflows/fpga-synth.yml`), `make lint/sim/model/fw/test`,
  `stub_core` (синус + пила → I2S, эхо MIDI, мигалка), модели NCO/ADSR/SVF, скрипты `gw_sh` для 9K и 20K.
  Осталось у автора: собрать битстрим в Gowin EDA и проверить «мигалку» на 9K. См. `fpga/README.md`.
- **Решения этапа 0:**
  - sys_clk = 99 МГц (rPLL 27 · 11 / 3), BCK = sys_clk / 32, fs = 48 339.84 Гц (+0.7 %);
  - таблица синуса — четверть периода, 1024 × 17 бит, без интерполяции (THD+N ≈ −67 дБ); генерируется из модели
    в виде `case`-ROM (`make luts`), а не `$readmemh` — нет зависимости от путей в Verilator/Gowin/yosys;
  - стимулы MIDI — текст `<время_мс> <байты hex>`; входы ВХ1/ВХ2 из файлов подключаются в тестбенч вместе
    с моделью АЦП (этап 6);
  - распиновка I2S/MIDI на макете — предварительная (HO-01): 9K и 20K — выводы 25–29.

### Этап 1. Звук наружу (паритет с midi2aux)
- PLL, `audio_tick` ≈ 48 кГц, I2S TX → модуль PCM5102A.
- UART RX 31250 + парсер MIDI (running status) → FIFO событий.
- Временно: один голос, меандр, реакция на последнюю ноту — прямо в RTL.
- Выходной каскад на макетке: ОУ ±15 В → ±10 В. Проверить DC-тракт PCM5102A (O-09).
- **Готово, когда:** клавиатура играет одноголосно через АВК, как старый midi2aux.
- **Статус:** RTL и тесты готовы (`mono_core`, юнит-тесты `uart_rx`, `midi_parser`, `sync_fifo`, `pitch2inc`,
  системный тест нот, pitch bend и задержки); board-top 9K/20K собирают `mono_core`. Осталось на железе:
  PCM5102A + выходной каскад, проверка DC-тракта (O-09).
- **Решения этапа 1:**
  - формат отсчётов Q2.16 в 18 битах: 1.0 = 2^16 = МЕ (±10 В), запас до ±2 МЕ внутри тракта;
    на выходе `dac_scale`: код ЦАП = x · 1.6, т.е. МЕ = 0.8 FS ЦАП (±12.5 В);
  - высота тона в лог-шкале: `pitch = log2(inc) · 2^16` (21 бит), модуляции складываются в этой шкале,
    перевод в инкремент — `pitch2inc` (таблица 2^x 1024 точки + линейная интерполяция, ошибка < 0.02 цента);
  - парсер MIDI отдаёт Note On с velocity 0 как Note Off `8n kk 40`, System Realtime — отдельными событиями.

### Этап 2. Процессор
- PicoRV32 + BSRAM + шина + UART-отладка + таймер.
- Загрузчик: прошивка по UART (BL702) и из SPI-флеша.
- MIDI FIFO читается CPU; `printf` событий в UART.
- **Готово, когда:** C-прошивка обновляется за секунды без пересборки битстрима и печатает ноты.
- **Статус:** RTL, прошивка и тесты готовы: `synth_core` (PicoRV32 RV32IMC, RAM 32 КБ, boot ROM 4 КБ, UART,
  таймер, GPIO, FIFO MIDI, sysinfo, SPI-флеш), загрузчик (UART + SPI-флеш), `sw/tools/load.py`.
  Системные тесты в Verilator: загрузка, запись/чтение флеша, повторный вход из прошивки, печать MIDI.
  На железе: проверить пины UART/флеша (предварительные) и смещение образа во флеше.
- **Решения этапа 2:** шина — нативный интерфейс PicoRV32 с ответом за 1 такт; boot ROM — генерируемый
  case-ROM из `sw/boot` (без путей к файлам в Gowin); в симуляции RAM можно заполнить сразу (`RAM_INIT`),
  минуя загрузчик; прерывания пока не используются (опрос).

### Этап 3. Полифония
- Голосовой движок с мультиплексированием по времени, параметр `NUM_VOICES`.
- 2 NCO на голос (пила, меандр/PWM, треугольник, синус), шум, смесь, расстройка.
- ADSR1 → громкость; velocity → громкость.
- Сумматор с запасом разрядности + софт-лимитер.
- Распределитель голосов на C: свободный голос / кража; pitch bend, mod wheel.
- Замер ресурсов 9K: сколько голосов влезает. Сравнение Gowin EDA и yosys+nextpnr по LUT и Fmax.
- **Готово, когда:** аккорды и Rush E на 16+ голосах без щелчков и переполнений.
- **Статус:** RTL, прошивка и тесты готовы. Движок `voice_engine` (побитово = `synthmodel.voice`): 2 NCO
  (пила, меандр/PWM, треугольник, синус) + шум, смесь, SVF Chamberlin с 2× передискретизацией (ФНЧ/ПФ/ФВЧ),
  ADSR1 → VCA, ADSR2 → срез, velocity → громкость и срез, сумма + мягкий лимитер. Прошивка: распределитель
  голосов (`fw/voice_alloc.c`), пересчёт параметров (`fw/params.c`), MIDI → регистры (`fw/synth.c`),
  неблокирующий лог; хост-тесты всех трёх. Системный тест: аккорд, bend, кража голосов.
  Осталось на железе: замер ресурсов 9K/20K, Fmax (цепочка умножитель → сумматор → регистр операнда
  за один такт — при нехватке Fmax вставить регистр, модель не меняется), сравнение с yosys+nextpnr.
- **Решения этапа 3:**
  - голоса считаются последовательно, 22 такта на голос (32 голоса ≈ 700 из 2048 тактов отсчёта);
  - огибающие — одно-полюсные экспоненты с коэффициентом «мантисса 17 бит + сдвиг» (времена 1 мс…10 с
    без потери точности); release целится в −1e-3, поэтому заканчивается ровно за время R;
  - фильтр — Chamberlin 2×, f = 2θ − θ³/3 (θ = π·fc/2fs), демпфирование ограничено `q ≤ 2 − f − 1/16`
    для устойчивости; срез до 0.34·fs (16 кГц);
  - ретриггер — бит-переключатель (одна сторона пишет каждый регистр);
  - осцилляторы свободно бегущие (без сброса фазы): при расстройке ГЕН2 основной тон «биет».

### Этап 4. Тембр
- SVF (ФНЧ/ПФ/ФВЧ, резонанс), ADSR2 → срез, velocity → срез.
- 2 LFO, вибрато от mod wheel.
- Сверка RTL с Python-моделью по WAV.
- **Готово, когда:** звучат классические пэды, басы и «квакающий» фильтр.
- **Статус:** RTL, прошивка и тесты готовы: SVF и ADSR2 — в движке (этап 3), `mod_unit` (2 LFO + матрица
  из 8 маршрутов, побитово = `synthmodel.modunit`), вибрато от mod wheel, ENV = огибающая последнего нажатого
  голоса, GATE = есть нажатые клавиши. Прошивка: таблица параметров (`fw/patch.c`) и консоль UART
  (`set/get/list/route/note/off`). Системные тесты: вибрато, огибающая фильтра.
- **Найдено и исправлено тестами:** DECAY к sustain = 0 уводил уровень ниже нуля (округление вниз
  `(T − e) >> 14`), в RTL это заворачивалось в огромное значение → щелчки. Уровень ограничен снизу нулём
  в модели и RTL, добавлен регрессионный тест. Память голосов очищается после сброса.
- **Решения этапа 4:** синус LFO — параболическая аппроксимация (ошибка ≤ 6 %, без ROM); случайный LFO —
  xorshift32 при каждом переполнении фазы; выходы блока модуляции движок защёлкивает на следующем
  `audio_tick` (задержка 1 отсчёт).

### Этап 5. Панель управления
- SPI-контроллер + MCP3208: 8 потенциометров → параметры (сглаживание, гистерезис).
- Декодеры энкодеров, драйвер ST7789, шрифт с кириллицей.
- Каркас меню, построенный из дескрипторов параметров.
- **Готово, когда:** звук настраивается без компьютера.
- **Статус:** RTL, прошивка и тесты готовы (в симуляции): опрос MCP3208, энкодеры, контроллер ST7789,
  шрифт 8×16 с кириллицей (GNU Unifont, OFL/GPL с исключением для встраивания), меню из дескрипторов,
  консольные команды `screen`, `panel`. Проверено: кадр дисплея попиксельно, задержка MIDI при нагрузке
  на экран ≤ 0.7 мс. На железе: пины панели не назначены (Gowin расставит сам; HO-01), проверить
  инициализацию конкретного модуля ST7789 (смещения 40/53, инверсия), направление энкодеров, шаг EC11.
- **Решения этапа 5:** ручки подхватывают параметр при первом повороте («jump on move»), с мёртвыми зонами
  по краям хода; сглаживание в RTL начинается с первого измерения (нет «разгона» после сброса);
  экран — текстовая модель 30×8 ячеек, отрисовка неблокирующая; SPI ручек и дисплея — раздельные шины.

### Этап 6. Связь с АВК (ключевой этап)
- АЦП входов (2× SAR, 192 кГц → децимация 48 кГц), нормировка ±10 В ↔ ±1.0.
- Вход СИНХР: измерение периода, фронт → триггер нот, такт для LFO.
- Шина сигналов, выходной микшер, ВЫХ2 (второй канал ЦАП).
- Матрица модуляции: ВХ1/ВХ2 → высота / срез / громкость.
- Вывод LFO / огибающей / gate на ВЫХ2 — модуляция АВК от синта.
- Интерфейс слота + слот MATH (A·B, A/B, |A|, …) — проверка архитектуры слотов.
- **Готово, когда:** генератор АВК модулирует фильтр синта, огибающая синта управляет блоком АВК, слот MATH повторяет умножитель АВК.
- **Статус:** RTL, прошивка и тесты готовы (в симуляции). `avk/adc_in.sv`: два AD7091R (общие CONVST/CS/SCLK),
  4 измерения на отсчёт, калибровка `x = sat18(((code − OFFSET)·GAIN) >> 16)`, КИХ-дециматор 64 отвода
  (Кайзер β = 7, 21.5 кГц), задержка 1 отсчёт; `avk/sync_in.sv`: фильтр дребезга, счётчик фронтов, период
  в тактах; `avk/fx_bus.sv`: шина S0 синт, S1 ВХ1, S2 ВХ2, S3 LFO1, S4 LFO2, S5 СИНХР (±1), S6 ENV, S7 GATE,
  S8+k — выход слота k; ВЫХ = softclip(Σ GAIN·S + DC), ВЫХ2 = softclip(S[SEL2]·GAIN2 + DC2);
  `avk/slot_math.sv`: A·B, A/B, |A|, A+B, A−B, min, max, A mod B, A·k+B. Все блоки бит-в-бит с моделью
  `synthmodel/avk.py`. Прошивка: параметры входов/ВЫХ2/слотов/СИНХР, 5 страниц меню, режимы СИНХР
  (LFO — сброс фазы LFO по фронту, нота — перезапуск ноты по фронту), команды `avk` и `cal` (калибровка
  нуля и масштаба входа). Системные тесты с моделями АЦП и СИНХР в тестбенче: кольцевой модулятор
  ВХ1·ВХ2 в слоте MATH, ВХ1 → высота тона, ВЫХ2 = GATE, частота СИНХР и запуск нот.
  На железе: пины АЦП и СИНХР не назначены (HO-01); калибровка входов по фактическому входному каскаду.
- **Решения этапа 6:** слоты выполняются по порядку, слот, читающий более поздний слот, видит его прошлый
  отсчёт; неизвестный TYPE_ID — сквозной проход A; ВЫХ2 по умолчанию — LFO1; нажатая клавиша (GATE)
  берётся из регистра GATE блока модуляции; режим «нота» от СИНХР повторно нажимает ту же ноту
  (перезапуск огибающих), а не «отпустить + нажать» — оба события попали бы в один отсчёт.
  Консоль: приём UART вычитывается целиком за проход цикла, отрисовка меню — не больше 2 ячеек за
  проход (иначе при 1 Мбод переполнялся FIFO приёма на 16 байт).

### Этап 7. Переход на Tang Nano 20K + память
- Top-level и распиновка 20K; контроллер SDRAM + арбитр портов слотов.
- (На 9K допустимо отладить то же на встроенной PSRAM — интерфейс памяти абстрактный.)
- Слот DELAY: обратная связь, dry/wet, время от энкодера и от СИНХР.
- Масштабирование до 32 голосов.
- **Готово, когда:** 32 голоса + 2 задержки, раздельно на ВХ1 и ВХ2, смешиваются на выходе.
- **Статус:** RTL, прошивка и тесты готовы (в симуляции). Порт внешней памяти (запрос удерживается до
  подтверждения) и арбитр `mem/mem_arb.sv` (слоты — приоритет, затем окно CPU `0x4000_0000`); бэкенды
  `mem/mem_bram.sv` (9K: 4096 × 18 бит = 85 мс) и `mem/sdram_ctrl.sv` (20K: встроенная SDRAM 2M × 32,
  43 с; ACTIVE → READ/WRITE с автоподзарядом, регенерация каждые 7.8 мкс). Контроллер SDRAM проверен
  против модели, контролирующей tRCD/tRC/tRP/tWR/CL/регенерацию/инициализацию (модель ловит
  намеренно испорченные параметры). Слот DELAY (TYPE_ID 2): время, обратная связь, wet/dry, бит-в-бит
  с моделью при случайной задержке памяти. Прошивка: память делится поровну между задержками,
  параметры `dly1*`/`dly2*` (вход, время в мс, повтор, уровень), время от периода СИНХР (`dlysync`),
  команда `mem`. Прошивка переведена на целочисленную арифметику (без soft-float, −5 КБ).
  Системные тесты: эхо 50 мс с затуханием 50 %, время задержки от СИНХР 10 Гц, доступ CPU к памяти.
  PSRAM 9K не используется (нужен IP Gowin); 32 голоса на 20K — параметр `NUM_VOICES`, проверить
  утилизацию и тайминг синтезом. На железе: фаза такта SDRAM (HO-07).
- **Решения этапа 7:** одно слово памяти на отсчёт (18 бит в 32-битном слове); слоты выполняются
  по очереди, поэтому порт памяти шины — порт текущего слота без арбитража между слотами; задержка
  работает и в обходе (линия остаётся заполненной); тактовый сигнал SDRAM синфазен `clk`.

### Этап 8. Эффекты P1
- CHORUS/FLANGER, REVERB.
- PolyBLEP, жёсткая синхронизация от СИНХР, sustain, остальная матрица модуляции, envelope follower, pitch CV на ВЫХ2.
- **Статус:** готово в симуляции, кроме PolyBLEP. Слоты CHORUS (TYPE_ID 3: модулируемая задержка с
  треугольным LFO и линейной интерполяцией; хорус и флэнжер — одни и те же параметры) и REVERB
  (TYPE_ID 4: 4 гребенчатых фильтра с глушением + 2 всепропускающих, 5934 слова памяти) — бит-в-бит
  с моделью при случайной задержке памяти. Жёсткая синхронизация генераторов от фронта СИНХР
  (регистр HSYNC, по генераторам), следящий детектор огибающей ВХ1/ВХ2 — источник 10 матрицы
  модуляции (атака/спад), ВЫХ2 = высота последней ноты 1 В/окт (0 В = до первой октавы), sustain —
  с этапа 3. Прошивка: память — сначала реверберации и хорусу, остаток делят задержки; 5 новых
  страниц меню. На 20K — 6 слотов (MATH, MATH, DELAY, DELAY, CHORUS, REVERB), на 9K — 3 (без хоруса
  и реверберации: мало памяти). PolyBLEP (регистр BLEP, параметр `blep`, по умолчанию выключен):
  x = d/inc через pitch2inc от дробной части высоты (2^(17 − frac)) — 17 бит точности на всех
  высотах, коррекция на обоих скачках меандра; голос стал 32 такта (32 голоса — ~1060 из 2048);
  в модели снижает наложение спектра пилы/меандра 3.5 кГц на 14–15 дБ.
- **Решения этапа 8:** реверберация с фиксированными длинами линий (Freeverb, пересчёт на 48 кГц
  не делается); вход гребёнок ослаблен в 4 раза; ROOM 0.70…0.98, DAMP 0…0.4 из процентов в прошивке.

### Этап 9. Пресеты и сервис
- FAT на SD: сохранение и загрузка пресетов (синт + маршрутизация + слоты).
- Прошивка CPU во флеш из файла на SD.
- **Статус:** готово в симуляции. SPI-блок 11 для SD-карты (старт на 400 кГц, дальше 16.5 МГц); драйвер SD
  (SDHC/SDSC, одиночные блоки); FAT16/FAT32 — файлы корневого каталога, имена 8.3 (длинные имена
  пропускаются); пресеты `PRESETnn.BIN` — двоичная запись (значения по хешу имени параметра, переживает
  добавление/удаление параметров) + маршруты 1…7; команды `sd`, `ls`, `save`, `load`, `fwupdate`;
  страница меню «ПРЕСЕТЫ» (кнопка ПАР.1 — загрузить, ПАР.2 — записать). Обновление: FIRMWARE.BIN → флеш
  в формате загрузчика, с проверкой CRC перед записью заголовка. Тесты: хост-тесты FAT на образах
  независимого генератора `sw/tools/fatimg.py` (он же проверяет записанные образы), SD на модели карты;
  системные — модель SD в тестбенче: пресеты из консоли и с панели, обновление прошивки и загрузка
  с флеша. На железе: пины SD (HO-01), совместимость конкретных карт.
- **Решения этапа 9:** двоичный формат пресета вместо текстового — прошивка должна помещаться в 32 КБ
  ОЗУ 9K (текущий объём 30.6 КБ со стеком 2 КБ; компактное 64-битное деление вместо libgcc, буфер лога
  512 Б); запас — десятки байт. Для дальнейшего роста — ОЗУ 64 КБ на 20K (параметр `RAM_BYTES`)
  или отдельная урезанная сборка для 9K.

### Этап 10. Интеграция
- Калибровка ВХ/ВЫХ (смещение, масштаб), проверка при Volume = max.
- Демонстрационные схемы набора на АВК (для статьи).
- Подробно — шаги Ж6–Ж7 ниже.

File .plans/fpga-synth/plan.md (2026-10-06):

# План: FPGA-синтезатор для АВК-6 — железо

ТЗ: [`trs.md`](trs.md) · требования к схеме: [`hw-requirements.md`](hw-requirements.md) · схема по узлам:
[`hw/schematic.md`](../../hw/schematic.md) · проект KiCad: [`hw/kicad`](../../hw/kicad/README.md) · эскиз панели:
[`panel-sketch.svg`](panel-sketch.svg) · сделанное в симуляции: [`done-sim.md`](done-sim.md).

## Где мы сейчас

| Часть | Что | Статус |
|---|---|---|
| Этапы 0–9 | RTL, прошивка, Python-модели, тесты, CI: голоса, фильтр, огибающие, модуляция, связь с АВК, эффекты, панель, пресеты | **готово в симуляции**, журнал и решения — [`done-sim.md`](done-sim.md) |
| Документы железа | ТЗ, требования к узлам (`Т-xx`), схема по узлам, рисунки узлов, проект KiCad (сгенерирован, цепи сверены) | черновик, уточняется по итогам части А |
| **Ж0** | подготовка ПО к работе с железом: команды запуска, калибровки, счётчики, ОЗУ 64 КБ, скрипты стенда | **следующий шаг** (агент, без железа) |
| **Часть А** | стенд на отладочных платах: Tang Nano 20K, готовые модули, свои узлы на макетках | впереди |
| **Часть Б** | готовый блок: несущая плата, панель, работа в корзине АВК-6 | впереди |

```mermaid
flowchart LR
    Z0[Ж0<br/>ПО к железу] --> A1[А1<br/>синтез, пины]
    A1 --> A2[А2<br/>цифровое ядро] --> A3[А3<br/>MIDI, панель] --> A4[А4<br/>аналог] --> A5[А5<br/>стенд целиком<br/>+ АВК проводами]
    A1 -.пины.-> B1
    A5 -->|поправки номиналов,<br/>закрытые HO| B1[Б1<br/>схема KiCad] --> B2[Б2<br/>плата, панель] --> B3[Б3<br/>первое включение] --> B4[Б4<br/>блок на столе] --> B5[Б5<br/>блок в АВК]
```

Часть А снимает все риски, которые дорого исправлять на плате: распиновку, тайминг ПЛИС, DC-тракт ЦАП, SDRAM,
номиналы аналоговых узлов, уровни СИНХР. Часть Б начинается, когда стенд целиком работает и цифры записаны.
Схему (Б1) можно доводить параллельно с А2–А5: распиновка известна после А1.
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

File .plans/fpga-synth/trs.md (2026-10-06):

# ТЗ: FPGA-синтезатор / процессор эффектов — сменный модуль АВК-6

Статус: **черновик v0.2**. Приоритеты: **P0** — обязательно в первой версии, **P1** — во второй, **P2** — потом.
Открытые вопросы собраны в разделе 10 (`O-xx`).

---

## 1. Назначение

Сменный модуль АВК-6, развитие проекта MIDI2AUX:

1. **Полифонический виртуально-аналоговый синтезатор** с MIDI-входом, реакцией на силу нажатия и огибающими.
2. **Процессор сигналов АВК**: два DC-входа, эффекты на кольцевом буфере (задержка, хорус, реверберация) и математические операции над сигналами.
3. **Связь синтезатора с АВК в обе стороны**: сигналы АВК модулируют синтезатор, а модуляционные сигналы синтезатора выводятся в АВК.
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

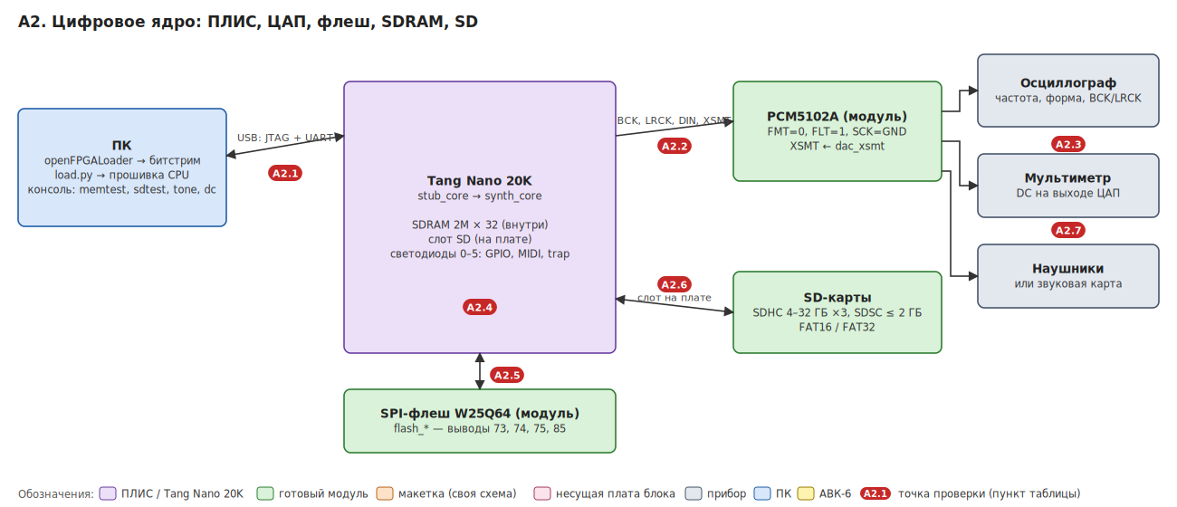
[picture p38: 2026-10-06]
.plans/fpga-synth/img/plan_a2.png

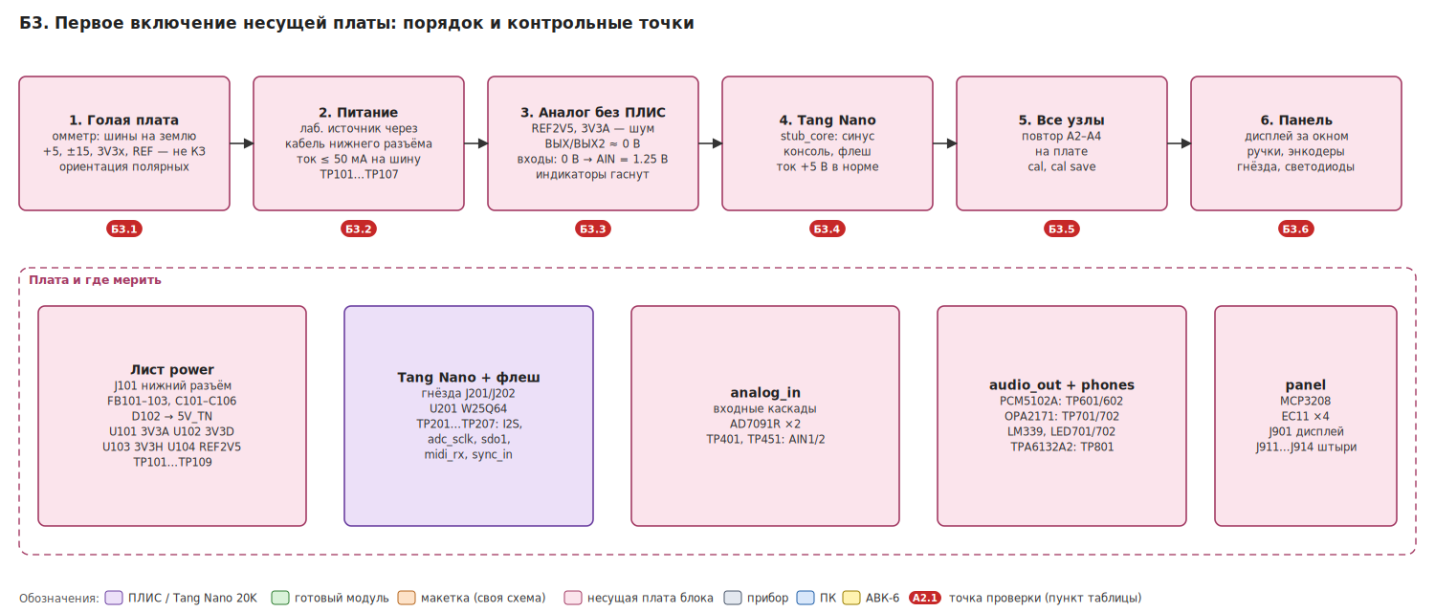
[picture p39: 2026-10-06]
.plans/fpga-synth/img/plan_b3.png

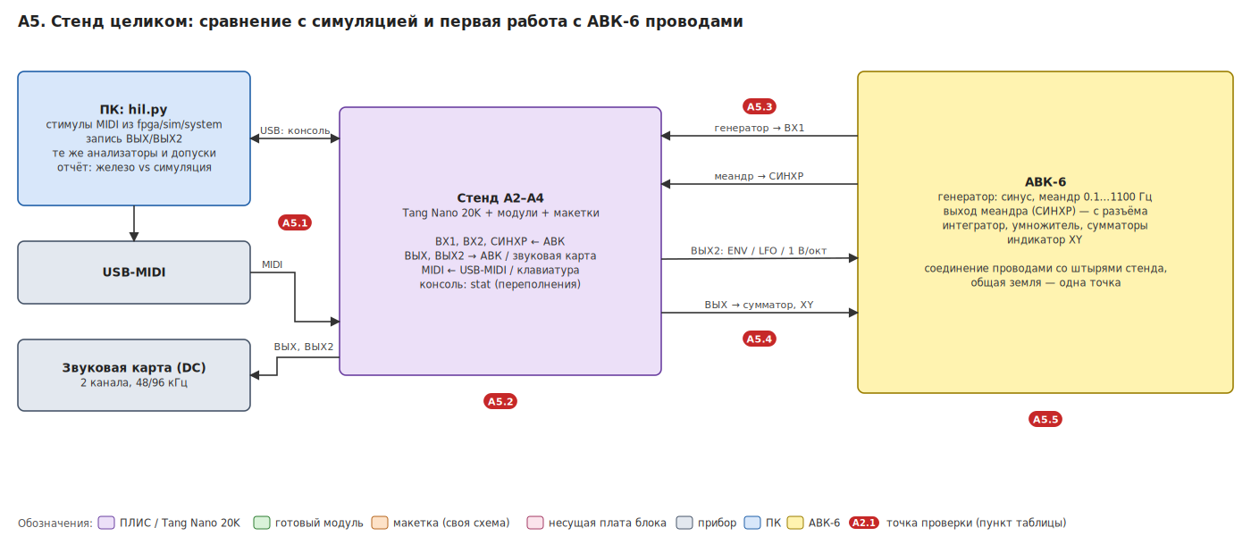
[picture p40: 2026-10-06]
.plans/fpga-synth/img/plan_a5.png

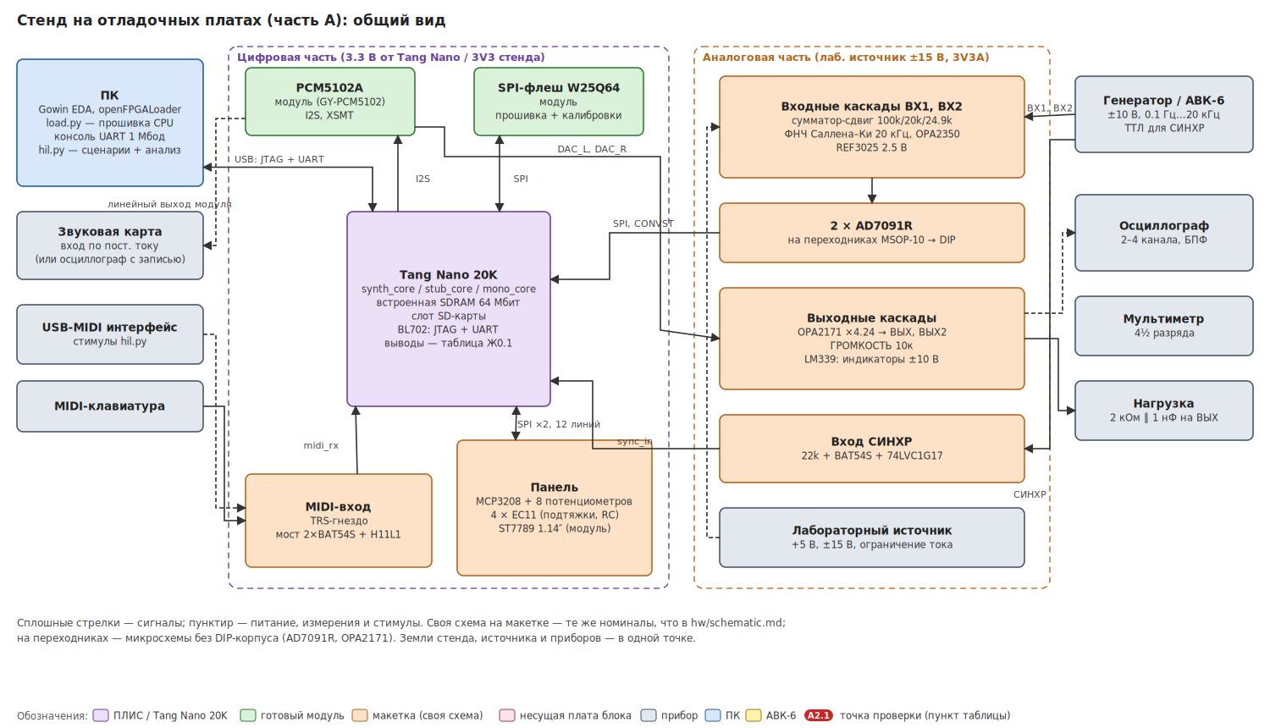
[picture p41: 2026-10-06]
.plans/fpga-synth/img/plan_stand.png

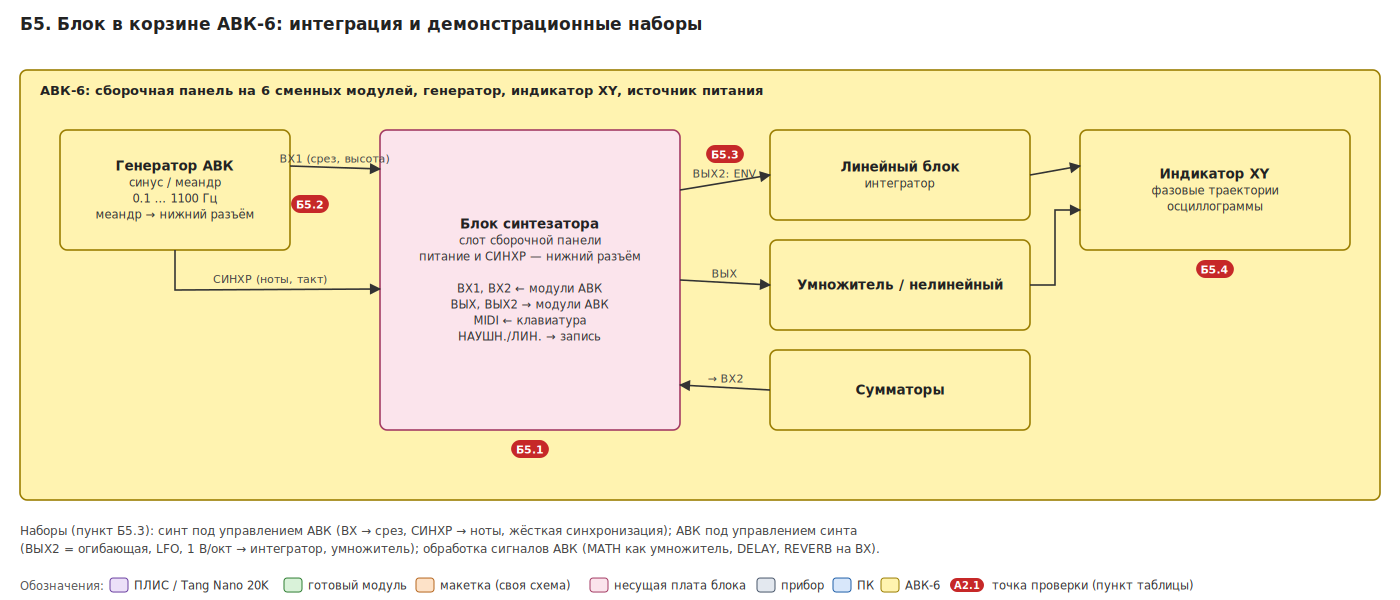
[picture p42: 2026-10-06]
.plans/fpga-synth/img/plan_b5.png

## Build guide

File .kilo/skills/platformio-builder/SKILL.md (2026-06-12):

---
name: platformio-builder
description: Автоматически собирает (build) и загружает (upload) прошивку для платформы, используя PlatformIO. Этот скилл следует использовать, когда пользователь просит собрать или загрузить прошивку для любого проекта на PlatformIO.
---

# Инструкция по работе с PlatformIO

Ты — AI-агент, специализирующийся на автоматизации сборки и загрузки прошивок для PlatformIO.

## Доступные задачи

1.  **Полная сборка и загрузка (Build & Upload)**:
    *   Эта команда выполняет компиляцию всего проекта и сразу прошивает устройство.

2.  **Только сборка (Build only)**:
    *   Эта команда только компилирует проект, не пытаясь прошить устройство. Используется для быстрой проверки кода.

3.  **Только загрузка (Upload only)**:
    *   Эта команда загружает на устройство последнюю успешно собранную версию прошивки.

4.  **Монитор**:
    * Эта команда открывает терминал и читает все что пишет устройство в последовательный порт

## Правила выполнения

1.  **Определение окружения**:
    *   Перед запуском команд всегда проверяй, что находишься в корневой директории проекта, где лежит файл `platformio.ini`.
    *   Если в проекте несколько окружений (environments), уточни у пользователя, какое именно нужно использовать. По умолчанию используй стандартный `pio run` без указания флага `-e`.

2.  **Выполнение команд**:
    *   Для выполнения задач используй следующие точные команды:

        **Команда 1 (Полная сборка и загрузка):**
        ```bash
        pio run --target upload
        ```

        **Команда 2 (только сборка):**
        ```bash
        pio run
        ```

        **Команда 3 (Только загрузка последней версии):**

        ```bash
        pio run --target upload --upload-no-build
        ```
        Если нужно указать конкретное окружение (например, env:esp32dev), используй флаг -e:

        ```bash
        pio run -e esp32dev --target upload
        ```

        **Команда 4 (Монитор)**
        ```bash
        pio device monitor
        ```

3. Обработка ошибок:

      Если сборка завершилась с ошибкой, внимательно проанализируй вывод терминала и предложи пользователю варианты исправления.

      Наиболее частые ошибки — отсутствие подключенной платы или неверно указанный порт. В случае ошибки загрузки посоветуй проверить подключение.

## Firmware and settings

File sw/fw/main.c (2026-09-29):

/* Firmware: polyphonic synth driven by MIDI; UART console (fw/console.h).
 * The log (UART) is non-blocking; "AVKB" on the UART re-enters the boot loader. */
#include "hw.h"
#include "lib.h"
#include "console.h"
#include "disp.h"
#include "storage.h"
#include "synth.h"

static struct synth synth;
static struct ui ui;
static struct storage storage;

/* SD card on SPI block 11 */
#define SPI_SD 11
static uint8_t sd_xfer(void *ctx, uint8_t b)
{
    (void)ctx;
    SPI_DATA(SPI_SD) = b;
    while (SPI_STATUS(SPI_SD) & 1u)
        ;
    return (uint8_t)SPI_DATA(SPI_SD);
}
static void sd_select(void *ctx, int on)
{
    (void)ctx;
    SPI_CS(SPI_SD) = (uint32_t)on;
}
static void sd_speed(void *ctx, int fast)
{
    (void)ctx;
    SPI_DIV(SPI_SD) = fast ? 2u : SYSINFO_SYS_CLK / 800000u; /* 16.5 MHz / 400 kHz at 99 MHz */
}
static const struct sd sd_hw = {sd_xfer, sd_select, sd_speed, 0, 0, 0};

static void preset_request(void)
{
    char line[32];
    int n = (int)synth.p.v[P_PRESET], load = ui.request == UI_REQ_LOAD;
    int r = load ? storage_load(&storage, &synth, n) : storage_save(&storage, &synth, n);
    ui.request = UI_REQ_NONE;
    if (r < 0)
        xsnprintf(line, sizeof line, "Пресет %d: ошибка %d", n, r);
    else
        xsnprintf(line, sizeof line, load ? "Пресет %d загружен" : "Пресет %d записан", n);
    log_printf("preset %d %s %d\n", n, load ? "load" : "save", r);
    if (load && r >= 0)
        ui_refresh(&ui);
    ui_status(&ui, line);
}

static const char *const ev_names[8] = {"note_off", "note_on", "poly_at", "cc",
                                        "program", "chan_at", "bend", "system"};

static void __attribute__((noreturn)) enter_loader(void)
{
    log_flush();
    __asm__ volatile("jr %0" ::"r"(BOOTROM_BASE + 4));
    __builtin_unreachable();
}

/* UART input: the boot loader magic "AVKB" or console lines */
static void poll_uart(void)
{
    static int k;
    static const char magic[4] = {'A', 'V', 'K', 'B'};
    int c;
    while ((c = uart_getc_nb()) >= 0) { /* drain: the RX FIFO is short */
        k = (c == magic[k]) ? k + 1 : (c == magic[0]);
        if (k == 4)
            enter_loader();
        console_feed((char)c);
    }
}

static void handle_event(uint32_t ev)
{
    uint8_t st = ev >> 16, d1 = ev >> 8, d2 = ev;
    int v = synth_midi(&synth, st, d1, d2);
    if (st == 0xF8 || st == 0xFE) /* clock / active sensing: too frequent to log */
        return;
    log_printf("midi: %02x %02x %02x %s", st, d1, d2, ev_names[(st >> 4) & 7]);
    if (st < 0xF0)
        log_printf(" ch=%u", (st & 15u) + 1);
    if (v >= 0)
        log_printf(" v=%d", v);
    log_printf("\n");
    if (st < 0xF0) {
        char line[32];
        xsnprintf(line, sizeof line, "MIDI %02x %02x %02x", st, d1, d2);
        ui_status(&ui, line);
    }
}

static void poll_panel(uint32_t now_ms)
{
    struct ui_input in;
    for (int k = 0; k < 4; k++)
        in.enc[k] = (int16_t)ENC_COUNT(k);
    in.pressed = (uint8_t)ENC_PRESSED;
    if (in.pressed)
        ENC_PRESSED = in.pressed;
    for (int k = 0; k < UI_POTS; k++)
        in.pot[k] = (uint16_t)(POT(k) >> 4);
    ui_update(&ui, &in, now_ms);
}

int main(void)
{
    struct fs_info fs = {SYSINFO_SYS_CLK, SYSINFO_BCK_HALF};
    uint32_t nv = SYSINFO_NUM_VOICES;
    uint32_t fs_mhz = (uint32_t)(((uint64_t)fs.sys_clk * 1000u) / (128u * fs.bck_half));
    synth_init(&synth, (int)(nv > VA_MAX_VOICES ? VA_MAX_VOICES : nv), fs);
    disp_init();
    ui_init(&ui, &synth);
    for (int k = 0; k < 4; k++) /* counters keep running across a firmware reload */
        ui.enc_prev[k] = (int16_t)ENC_COUNT(k);
    console_init(&synth, &ui);
    console_set_storage(&storage, sd_hw);

    log_printf("AVK6 synth fw, hw version %08x\n", (unsigned)SYSINFO_VERSION);
    log_printf("sys_clk %u Hz, fs %u.%03u Hz, RAM %u bytes, %u voices\n", (unsigned)fs.sys_clk,
         (unsigned)(fs_mhz / 1000), (unsigned)(fs_mhz % 1000), (unsigned)SYSINFO_RAM_BYTES, (unsigned)nv);
    int sd = storage_mount(&storage, sd_hw);
    if (sd)
        log_printf("sd: none (%d)\n", sd);
    else
        log_printf("sd: fat%d\n", storage.fat.fat32 ? 32 : 16);
    log_printf("READY\n");

    uint32_t t_led = cycles(), t_panel = cycles(), ms = 0;
    const uint32_t ms_cycles = fs.sys_clk / 1000u;
    for (;;) {
        uint32_t ev = MIDI_EVENT;
        if (ev & MIDI_EV_VALID)
            handle_event(ev & 0xFFFFFFu);
        if (MIDI_STATUS & MIDI_ST_OVERFLOW) {
            log_printf("midi: overflow\n");
            MIDI_CTRL = 1;
        }
        avk_poll(&synth);
        if (ui.request)
            preset_request();
        log_poll();
        ui_poll(&ui);
        poll_uart();
        if (cycles() - t_panel > 10 * ms_cycles) { /* panel every 10 ms */
            t_panel += 10 * ms_cycles;
            ms += 10;
            poll_panel(ms);
        }
        if (cycles() - t_led > fs.sys_clk / 2) {
            t_led = cycles();
            GPIO_OUT ^= 1u;
        }
    }
}

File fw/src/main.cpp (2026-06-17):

#include <avr/io.h>
#include <avr/interrupt.h>
#include <avr/sleep.h>
#include <util/delay.h>
#include "uart.h"
#include "midi.h"
#include "waveform.h"

#define MIDI_BAUD 31250

static void initTimer2(void) {
	TCCR2A = (1 << COM2B1) | (1 << WGM21) | (1 << WGM20);
	TCCR2B = (1 << WGM22) | (1 << CS20);
	OCR2A = 99;
	OCR2B = 0;
	DDRD |= (1 << 3);
}

static void initGPIO(void) {
	DDRD  |= (1 << 2) | (1 << 4) | (1 << 5) | (1 << 6) | (1 << 7);
	PORTD &= ~((1 << 2) | (1 << 4) | (1 << 5) | (1 << 6) | (1 << 7));

	DDRC  &= ~(1 << 1);
	PORTC |= (1 << 1);
}

static void initADC(void) {
	ADMUX  = (1 << REFS0) | (1 << ADLAR);
	ADCSRA = (1 << ADEN) | (1 << ADATE) | (1 << ADIE)
	       | (1 << ADPS2) | (1 << ADPS1) | (1 << ADPS0);
	ADCSRA |= (1 << ADSC);
}

ISR(ADC_vect) {
	potValue = ADCH;
}

static void initTimer1Btn(void) {
	TCCR1A = 0;
	TCCR1B = (1 << WGM12) | (1 << CS12) | (1 << CS10);
	OCR1A  = 155;
	TIMSK1 = (1 << OCIE1A);
}

static uint8_t btnState = 0;
static uint8_t btnCounter = 0;

ISR(TIMER1_COMPA_vect) {
	uint8_t btn = (PINC & (1 << 1)) ? 1 : 0;

	switch (btnState) {
	case 0:
		if (btn == 0) {
			btnState = 1;
			btnCounter = 3;
		}
		break;
	case 1:
		if (--btnCounter == 0) {
			if (btn == 0) {
				btnState = 2;
				noteOff();
				waveMode++;
				if (waveMode >= 3) waveMode = 0;
				PORTD &= ~((1 << 4) | (1 << 5) | (1 << 6));
				PORTD |= (1 << (4 + waveMode));
			} else {
				btnState = 0;
			}
		}
		break;
	case 2:
		if (btn == 1)
			btnState = 0;
		break;
	}
}

int main(void) {
	initTimer2();
	initGPIO();
	initADC();
	initTimer1Btn();
	initWaveform();
	uart_init(UART_BAUD_SELECT(MIDI_BAUD, F_CPU));

	PORTD &= ~((1 << 4) | (1 << 5) | (1 << 6));
	PORTD |= (1 << (4 + waveMode));

	_delay_ms(1000);
	PORTD |= (1 << 2);

	sei();
	set_sleep_mode(SLEEP_MODE_IDLE);

	for (;;)
		sleep_mode();

	return 0;
}

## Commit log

2026-06-12 Initial commit: MIDI→AUX firmware for Arduino Nano (ATmega328P)
    - platformio.ini: bare AVR-GCC, nanoatmega328, src_dir=fw/src
    - uart.h/cpp: Peter Fleury interrupt-driven UART, 31250 baud MIDI input
    - midi.h/cpp: note period table, MIDI parser, debug output on PB0 (38400)
    - waveform.h/cpp: Timer1 ISR, 4 waveform modes (square/triangle/saw/sine)
    - main.cpp: Timer2 160kHz PWM, ADC, button/LEDs, MIDI optocoupler gate (PD2)
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2026-06-12 Interrupt-driven rewrite: no main loop work, pure sleep
    - UART stripped to RX-only, midiParser called from USART_RX_vect
    - ADC free-running with interrupt, potValue updated automatically
    - Timer0 10ms tick handles button debounce and waveMode cycling
    - All debug output removed, midi.cpp is pure parser
    - main() does init, 1s bootloader delay, sei(), then sleep_mode()
2026-06-12 Fix hang on high notes: OCR1A minimum 500 + eliminate division in pot scaling
    Root cause: for high notes OCR1A was smaller than ISR execution time,
    causing CPU to never leave TIMER1_COMPA_vect cascade.
    - OCR1A clamped to >= 500 (31us period, safe margin for all modes)
    - (pot*64)/255 replaced with fast pot>>2 (error <0.4%)
    - (pot*63)/255 replaced with fast pot>>2 (error <1.2%)
    Eliminates 180-cycle divisions from the waveform hot path.
    [waveform.cpp]
2026-06-12 Swap Timer0/Timer1: button on high-priority Timer1, waveform on Timer0
    - TIMER1_COMPA_vect: 10ms button scan + noteOff on press (highest priority)
    - TIMER0_COMPA_vect: waveform generation (lower priority, can be preempted)
    - Timer0 waveform uses dynamic prescaler: 8 for high notes, 64 for low notes
    [main.cpp, waveform.cpp]
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2026-06-12 Revert Timer0 to dynamic prescaler (8/64) — Timer0 is 8-bit
2026-06-12 Lower OCR0A clamp: 500 -> 350 (ISR now ~250 cycles in worst case)
2026-06-12 Update README: Timer0/1 swap, prescaler table, clamp 350
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2026-09-28 Add TRS draft and implementation plan for FPGA synth module
    Panel sketch: add output clip LEDs and second (modulation) output.
    Claude-Session: https://claude.ai/code/session_01JcNV2ZCXWxtNzRVWffkrjk
2026-09-28 FPGA synth TRS v0.2: AVK jumper-grid pin positions, toolchain decision
    - Inputs/outputs placed on AVK-6 jumper grid; sync comes via bottom module connector
    - Remove ground pins and sync pin from panel
    - Resolve O-03 (second output), O-04 (Gowin EDA), O-06 (pot functions)
    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
2026-09-28 Add hardware requirements, AGENTS.md; CI-first plan
    - hw-requirements.md: per-node schematic requirements with component values
    - TRS v0.2: FS ±12.5 V, O-02 resolved (delay), link to hardware doc
    - plan: stage 0 starts with GitHub Actions CI (Verilator sim + WAV analysis)
    - AGENTS.md: project overview, docs, key decisions and rules for agents
    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
2026-09-28 Add stage 0 stub core and Verilator testbench
    Sine/saw NCO -> I2S TX with audio_tick from a parameterised sys_clk,
    MIDI UART RX echo. The testbench decodes I2S at the pins into WAV and
    check_stub.py verifies frequency, THD and bit-exactness with the model.
    Claude-Session: https://claude.ai/code/session_019zKoH7ZNWhtjqvhNK1wcXX
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2026-09-28 Add stage 1: MIDI parser, mono voice core, cocotb unit tests
    - midi_parser (running status, realtime, SysEx), sync_fifo, pitch2inc
    (log pitch -> phase increment), dac_scale (Q2.16 -> DAC, 1 MU = 0.8 FS)
    - mono_core: last-note square voice with pitch bend, gate CV on OUT2;
    board tops build it
    - RTL unit tests with cocotb against the Python models; system tests are
    pytest-driven via a generic Verilator testbench (tb_audio.cpp)
    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
2026-09-28 Add stage 2: PicoRV32 SoC, boot loader and firmware base
    - synth_core: PicoRV32 (RV32IMC) with RAM, generated boot ROM, UART,
    timer, GPIO, MIDI event FIFO, sysinfo and SPI flash peripherals
    - boot loader: UART image load with CRC, save to / boot from SPI flash,
    re-entry from the running firmware; host tool sw/tools/load.py
    - firmware runtime (UART, printf subset, CRC-32, flash) and stage 2
    firmware printing MIDI events; host C unit tests
    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
2026-09-28 Add stage 3: polyphonic voice engine and voice allocation
    - voice_engine: time-multiplexed voices (2 NCO + noise, Chamberlin SVF
    2x, ADSR1 -> VCA, ADSR2 -> cutoff, velocity), bit-exact with the new
    Python model synthmodel.voice; softclip output limiter
    - synth_core maps the engine at 0x2000_0000; OUT = softclip(voices + DC)
    - firmware: voice allocator (free / quietest releasing / oldest, same
    note reuse, sustain), parameter conversion, MIDI -> engine registers,
    non-blocking log; host unit tests for all of them
    - system test: chord, release, pitch bend and voice stealing through the
    firmware on the simulated PicoRV32
    Claude-Se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
    [main.c]
2026-09-28 Add stage 4: LFOs, modulation matrix, vibrato, UART console
    - mod_unit: 2 LFOs (sine, triangle, saws, square, S&H) and an 8-route
    modulation matrix (source x depth x via -> pitch/cutoff/amp/PWM),
    bit-exact with synthmodel.modunit; wired into the voice engine
    - voice engine: PW modulation input, ENV output of the last voice,
    clear pass after reset; fix ADSR decay to sustain 0 wrapping below
    zero (model + RTL, regression test)
    - firmware: parameter descriptor table, UART console (set/get/list/
    route/note/off), mod wheel vibrato, ENV/GATE sources; host tests
    - system tests: vibrato from the mod wheel, filter envelope
    Claude-Sess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
    [console.c, main.c]
2026-09-28 Add stage 5: panel -- knobs, encoders, ST7789 display, menu
    - RTL: MCP3208 poller with smoothing, EC11 encoder decoder with debounce,
    ST7789 stream controller (fills, 1-bpp glyph expansion, colour entries)
    - firmware: 8x16 font with Cyrillic (GNU Unifont), menu pages from the
    parameter table, knobs that take over on move, status line; the screen
    is a cell model drawn without blocking, so MIDI latency stays < 1 ms
    - testbench models: MCP3208, encoders, ST7789 framebuffer; the display
    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
2026-09-28 Add stage 6: AVK link -- inputs, SYNC, signal bus, MATH slot
    - RTL avk/: AD7091R pair at 4*fs with calibration and 64-tap FIR decimator,
    SYNC input (glitch filter, edges, period), signal bus with effect slots
    and OUT/OUT2 mixers, MATH slot; bit-exact with synthmodel/avk.py
    - synth_core: periph blocks 9 (SYNC) and 10 (ADC), bus at 0x3000_0000,
    inputs/SYNC/GATE wired into the modulation unit and the bus
    - testbench: AD7091R and SYNC signal sources (--in1/--in2/--sync)
    - firmware: bus/slot/OUT2/SYNC parameters and menu pages, SYNC modes,
    input calibration, avk/cal console commands; UART RX drained per loop
    pass and UI drawing bounded per pass (RX FIFO overflowed at 1 Mbaud)
    - tests: u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
    [avk.c, console.c, main.c]
2026-09-28 Add stage 7: external memory, SDRAM controller, DELAY slot
    - mem/: memory arbiter (slots first, then the CPU window at 0x4000_0000),
    block RAM backend (9K), SDR SDRAM controller for the 20K embedded SDRAM
    - slot DELAY (time, feedback, wet/dry); CHORUS and REVERB slot RTL with
    models (firmware and docs follow)
    - tests: SDRAM controller against a timing-checking device model,
    arbiter + BRAM, slots bit-exact with the model under random memory
    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
2026-09-29 Add stage 8: chorus and reverb slots, hard sync, envelope follower
    - slots CHORUS (modulated, interpolated delay) and REVERB (4 damped combs
    + 2 allpasses) in firmware, menu and on the 20K (6 slots)
    - voice engine: HSYNC register, oscillator phases restart on SYNC edges
    - mod unit: envelope follower of IN1/IN2 as modulation source 10
    - OUT2 can carry the pitch CV of the last note (1 V/octave)
    - tests: hard sync and follower bit-exact with the models, system tests
    for reverb tail, chorus, hard sync, follower and pitch CV
    - vsys: pass parameters wider than 32 bits as sized literals
    Claude-Session: https://claude.ai/code/session_019zK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
    [avk.c]
2026-09-29 Add SD card storage layer: FAT16/32, SD SPI driver, presets, fw update
    Firmware modules not yet wired into the core (SPI block, console and menu
    follow): root-directory FAT16/FAT32 read/write, SD card SPI driver
    (SDHC/SDSC), binary presets keyed by parameter-name hashes, firmware
    update from FIRMWARE.BIN to flash in the boot loader's format.
    Host tests use disk images from tools/fatimg.py (an independent FAT
    implementation that also checks the written images) and an SD card model
    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
2026-09-29 Add stage 9: SD card presets and firmware update in the core
    - synth_core: SPI block 11 for the SD card (400 kHz at reset), board ports
    - firmware: mount at start, console sd/ls/save/load/fwupdate, presets
    page in the menu (button 2 loads, 3 saves); fits 32 KB again: compact
    64-bit division instead of libgcc's, int16 parameter limits, 512-byte
    log ring; no gp relaxation for the start-up addresses
    - testbench: SD card model on the SD pins (--sd-image/--sd-dump)
    - tests: console storage commands, preset buttons, system tests for
    presets from console and panel, no card, SD -> flash -> boot
    Claude-Session: https://claude.ai/code/se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
    [console.c, main.c]
2026-09-29 Add PolyBLEP for saw and square oscillators
    - voice engine: BLEP register; x = d / inc through pitch2inc of the
    fractional pitch (17-bit precision at every pitch), corrections at both
    square jumps; 32 clk per voice (32 voices ~1060 of 2048 clk)
    - model: exact arithmetic and an aliasing test (-14..-15 dB at 3.5 kHz)
    - RTL bit-exact with the model, PolyBLEP on in every other scene
    - firmware: parameter `blep` (off by default), on the presets page
    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
2026-09-29 Replace the README with the FPGA synth description
    - new README.md: module panel, features, block diagram, oscillators,
    PolyBLEP, hard sync, filter, envelopes, LFO and modulation matrix,
    envelope follower, AVK link, all effects (MATH, DELAY, CHORUS/FLANGER,
    REVERB, output limiter), menu guide with screenshots, presets, console
    - pictures from the bit-exact models and the firmware menu code:
    fpga/model/readme_figs.py + sw/tools/ui_pages.c, `make readme-img`
    - the MIDI2AUX README moves to docs/midi2aux.md
    - presets page label: ПАР.1 loads, ПАР.2 saves (was "2:загр 3:зап")
    Claude-Session: https://claude.ai/code/sessio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
2026-10-01 Make line output headphone-capable (TPA6132A2)
    - Headphone/line output: 16-600 ohm, short-circuit protected, separate 3.3H rail
    - Output op-amp back to OPA2171 (OUT, OUT2)
    - Update block diagram, panel label, TRS and hardware requirements; close HO-07
    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
    [tools-gen-block-diagram.py]
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2026-10-03 Replace ASCII schematics with rendered drawings
    - hw/img/gen_schematics.py draws node schematics with schemdraw
    - hw/schematic.md links sch_*.png instead of text diagrams
    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
2026-10-03 Add KiCad 7 schematic project for the carrier board
    - hw/kicad: hierarchical schematic (10 sheets) generated from hw/schematic.md
    with standard KiCad symbols/footprints and custom AD7091R, Tang_Nano_20K
    - tools/gen_kicad.py (generator), check.py (netlist vs intended nets: 153/153),
    render.sh; PDF of all sheets
    - schematic.md: TPA6132A2 differential inputs (C808/C809), HPVDD cap, TVS pair
    - AGENTS.md: how the KiCad project is maintained
    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
    [adc.kicad_sch, ain1.kicad_sch, ain2.kicad_sch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]
2026-10-03 Reorganize KiCad schematic into 7 functional sheets with framed blocks
    - Sheets: power, fpga, midi_sync, analog_in (inputs + ADC), audio_out
    (DAC + OUT/OUT2 + clip LEDs), phones, panel
    - Each functional block is drawn in a dashed frame with a title; blocks are
    tiled across the sheet, A3/A2 chosen automatically
    - Netlist check still 153/153; PDF and docs updated
    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
    [adc.kicad_sch, ain1.kicad_sch, ain2.kicad_sch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]
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
